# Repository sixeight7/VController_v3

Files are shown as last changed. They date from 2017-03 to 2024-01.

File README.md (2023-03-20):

# VController_v3
Production model of the VController, VC-mini and VC-touch

The VC-touch is a MIDI footcontroller with 15 buttons and a large TFT touch screen:

VC-touch

The VC-mini is a small version of the VController with 3 buttons, 3 LEDs, 2 encoders and 1 LCD display:

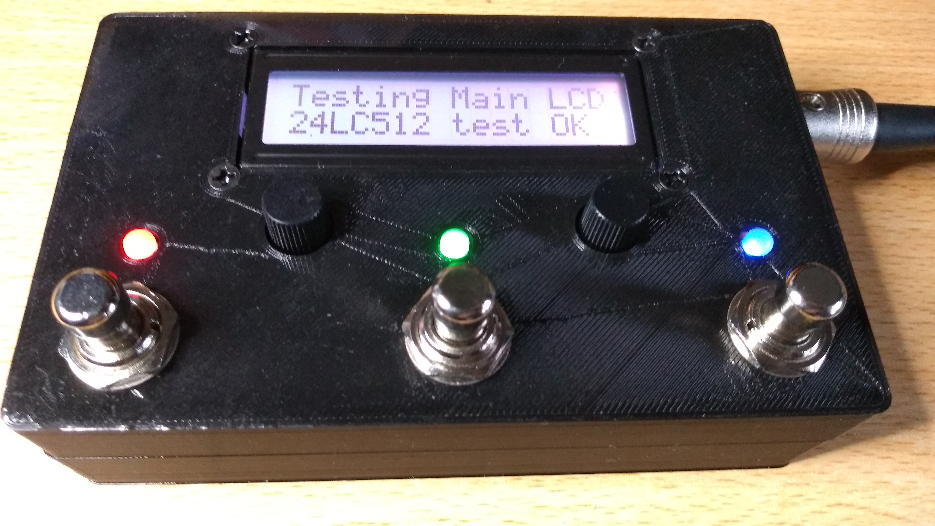
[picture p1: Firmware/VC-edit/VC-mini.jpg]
VC-mini


The VController is the original controller with 16 buttons, 12 LCDs and 12 LEDs:

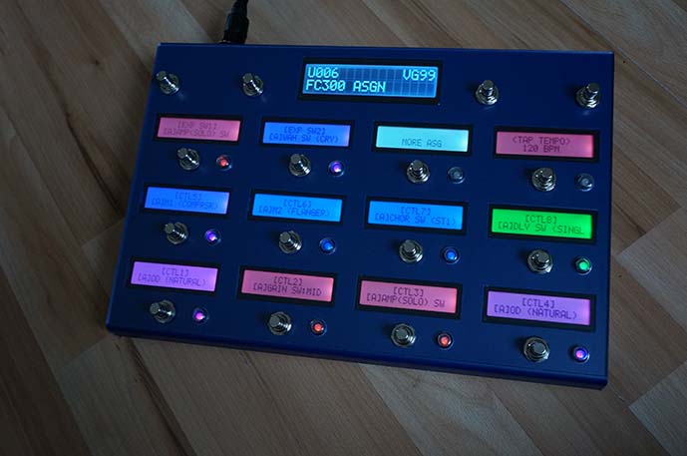
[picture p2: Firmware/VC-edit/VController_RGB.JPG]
VController


All can be fully programmed both onboard and via an external editor for Mac and PC called VC-edit.
All devices share the same code for the Teensy firmware and the editor (Qt)

# Device support
A number of guitar modelers and synths are supported, where it actively read patch names and parameter states for the following devices:
* Fractal Audio Axe-fx 2 (other models may work too, but have not been tested yet)
* Boss GP-10
* Roland GR-55
* Roland VG-99
* Boss Katana (50/100/Artist - MK1 and MK2)
* Boss SY-1000
* Kemper Profiling Amp
* Line 6 Helix (limited)
* Line 6 M13
* Zoom G3
* Zoom MS70-cdr
* Strymon Volante
* TC Electronics G-Major
* NUX MG-300

# General MIDI
The VController, VC-mini and VC-touch are also able to send MIDI PC, CC and Note on/off messages to control any device that is able to receive these messages.

# Programmability
The VController, VC-mini and VC-touch support up to 200 user pages, where a total of almost 3000 commands can be programmed. Any button can execute up to 50 commands.

# Connectivity of the VController
* There are two MIDI in/out conenctors and MIDI 2 doubles as an RRC2 connection for the VG-99.
* Four external expression pedals or eight external switches can be connected.
* One USB slave connector (also used for programming the VController)
* An internal or external Raspberry Pi can add four USB host ports to the VController.

# Connectivity of the VC-mini
* Two 7 pin MIDI connectors with MIDI in/out and power in one connector. MIDI1 has a seperate 7 pin connector with MIDI in/out reversed. The 7 pin connectors are compatible with regular 5 pin MIDI connectors.
* One external expression pedal or two external switches can be connected via a 3.5 mm jack plug (may need an adapter to regular jack.)
* One USB slave connector (also used for programming the VC-mini)
* One USB host port

# Connectivity of the VC-touch
* Three 7 pin MIDI connectors with MIDI in/out and power in one connector, MIDI in/out port on 3,5 mm plugs, wireless MIDI through MIDI BLE and WIFI - AppleMIDI.
* Three external expression pedal or six external switches can be connected via a 3.5 mm jack plug (may need an adapter to regular jack.)
* One USB slave connector (also used for programming the VC-touch)
* One USB host port

# Hardware
This repository contains the building plans (enclosure and schematics) for the VC-mini, the VController and the optional external Raspberry Pi. Check out the building guides for both projects.

# Firmware
This repository also contains the source code for the V-Controller, the VC-mini and for VC-edit. The source code for VC-bridge (the code for the raspberry pi) is in a separate repository called VC-bridge. There are also ready made hex files for the V-Controllers Teensy. There is also special firmware to check hardware of the V-Controller or the VC-mini.

For VC-edit there is a ready to run zip file for windows and dmg-file for Mac. Also the source code of VC-edit is provided.

# Webstore
You can buy ready made VC-mini's and VC-touches or seperate PCBs and enclosures at my webstore.
https://sixeightsoundcontrol.onlineweb.shop/

# Support
Please visit https://www.vguitarforums.com/smf/index.php?board=277.0 for additional information or for any questions you have regarding this project. Please post any questions on the board, where several users and builders can respond and help.

I have invested thousands of hours in this project. You can support me here: https://www.paypal.me/sixeight

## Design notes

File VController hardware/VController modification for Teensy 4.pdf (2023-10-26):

VController modification for Teensy 4.1

To run firmware 3.12.0 or higher on the VController the existing Teensy 3.2 must be replaced with a Teensy 4.1.

Step 1: determine the pin type used in the VController for the Teensy 3.2.
Open the VController by removing the six screws from the bottom plate. Remove the main PCB by removing the nuts of the EXP pedal jacks, the screws around the RRC2 connector and the screw next to it. Now gently remove the Teensy 3.2 and check the pin type. These are either thin pin headers or regular pins headers. I have used different ones for different VControllers

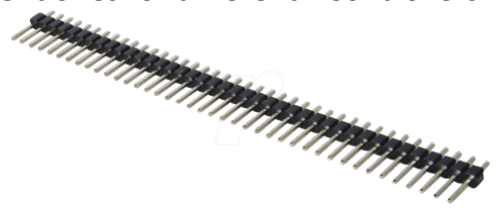
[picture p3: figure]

Thin pin headers: reichelt.de product code: BKL 10120538
Regular pin headers: reichelt.de product code: SL 1X40G 2,54
Step 2: get the parts
So you will need to get a Teensy 4.1 without a pin header attached and you will need two 14-pin headers.
Step 3: flash the firmware on the Teensy 4.1
The switch to get the Teensy 4.1 into program mode will no longer be accessible once it is placed on the board, so make sure you flash the firmware using the Teensy loader before you put the Teensy on the board.
Step 4: replace the Teensy
Solder the two 14-pin header to the top side of the Teensy, using pin 0 – 23 and the power pins. Remove the Teensy 3.2 and replace it with the Teensy 4.1.
Now replace the wires connected to D- and D+ to the small pads on the Teensy 4.1. The pads are not marked on the Teensy 4.1 but the wires do go the same way around.
The wires of pad 29 and 30 of the Teensy 3.2 go the pin 24 and pin 25 of the Teensy 4.1.
The wire of pad 28 of the Teensy 3.2 goes to pin 26 of the Teensy 4.1.
Then attach two wires connecting pin 9 with pin 28 and pin 10 with pin 29. This will fix the serial port that is on different pins on the Teensy 4.1

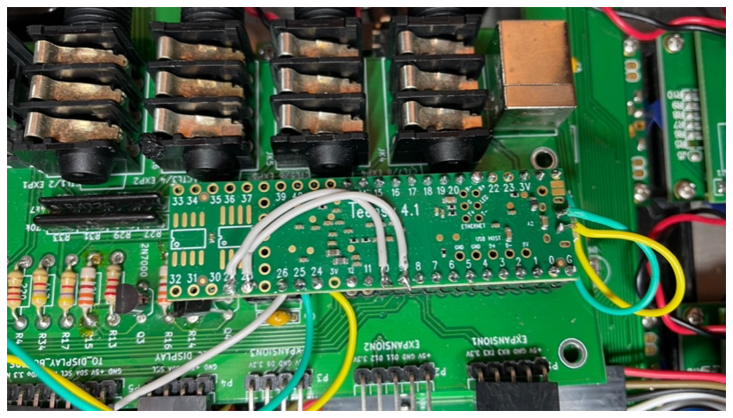
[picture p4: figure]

That’s it. If you have any questions or would like me to do the modification, please contact me at sixeightsoundcontrol@gmail.com.

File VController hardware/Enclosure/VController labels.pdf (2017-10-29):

USB | EXP4 | EXP3 | EXP2 | EXP1 | OUT | IN | IN/OUT | RRC2 | DC
CTL7/8 | CTL5/6 | CTL3/4 | CTL1/2 | MIDI 1 | MIDI2 | POWER
USB | EXP4 | EXP3 | EXP2 | EXP1 | OUT | IN | IN/OUT | RRC2 | DC
CTL7/8 | CTL5/6 | CTL3/4 | CTL1/2 | MIDI 1 | MIDI2 | POWER
USB | EXP4 | EXP3 | EXP2 | EXP1 | OUT | IN | IN/OUT | RRC2 | DC
CTL7/8 | CTL5/6 | CTL3/4 | CTL1/2 | MIDI 1 | MIDI2 | POWER
USB | EXP4 | EXP3 | EXP2 | EXP1 | OUT | IN | IN/OUT | RRC2 | DC
CTL7/8 | CTL5/6 | CTL3/4 | CTL1/2 | MIDI 1 | MIDI2 | POWER
USB | EXP4 | EXP3 | EXP2 | EXP1 | OUT | IN | IN/OUT | RRC2 | DC
CTL7/8 | CTL5/6 | CTL3/4 | CTL1/2 | MIDI 1 | MIDI2 | POWER
IN/OUT | OUT/IN | DC
MIDI | POWER
IN/OUT | OUT/IN | DC
MIDI | POWER
IN/OUT | OUT/IN | DC
MIDI | POWER
IN/OUT | OUT/IN | DC
MIDI | POWER
IN/OUT | OUT/IN | DC
MIDI | POWER
IN/OUT | OUT/IN | DC
MIDI | POWER
IN/OUT | OUT/IN | DC
MIDI | POWER
IN/OUT | OUT/IN | DC
MIDI | POWER
IN/OUT | OUT/IN | DC
MIDI | POWER
USB | EXP4 | EXP3 | EXP2 | EXP1 | OUT | IN | IN/OUT | RRC2 | DC
CTL7/8 | CTL5/6 | CTL3/4 | CTL1/2 | MIDI 1 | MIDI2 | POWER
USB | EXP4 | EXP3 | EXP2 | EXP1 | OUT | IN | IN/OUT | RRC2 | DC
CTL7/8 | CTL5/6 | CTL3/4 | CTL1/2 | MIDI 1 | MIDI2 | POWER

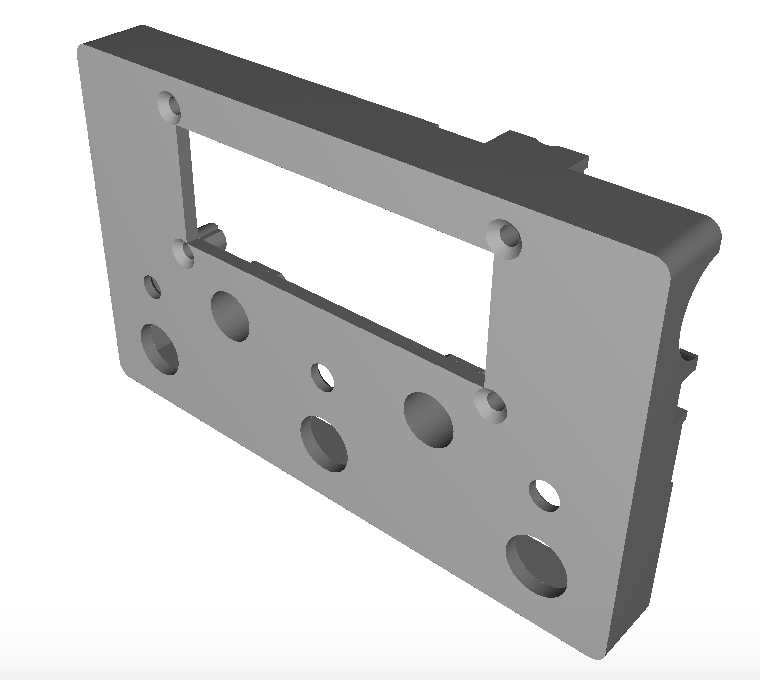
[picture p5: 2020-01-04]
VC-mini hardware/Enclosure/VCmini_upper_cover_Buydisplay_display.png

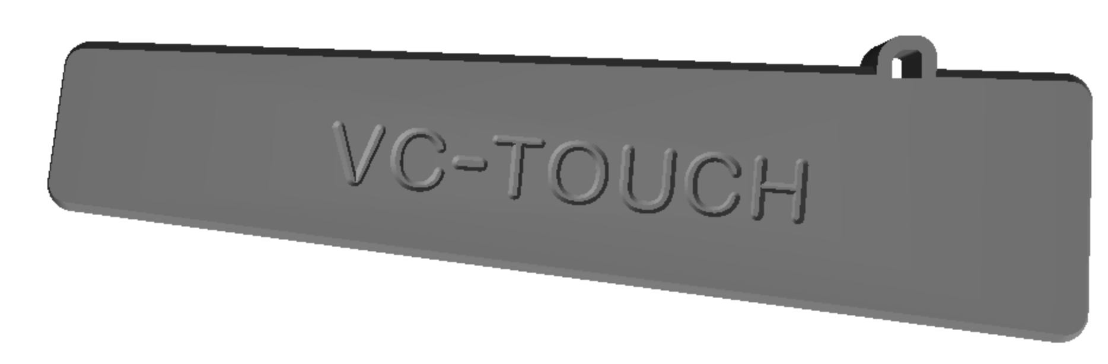
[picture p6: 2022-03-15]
VC-touch hardware/Enclosure stl/vctouch_right_side.png

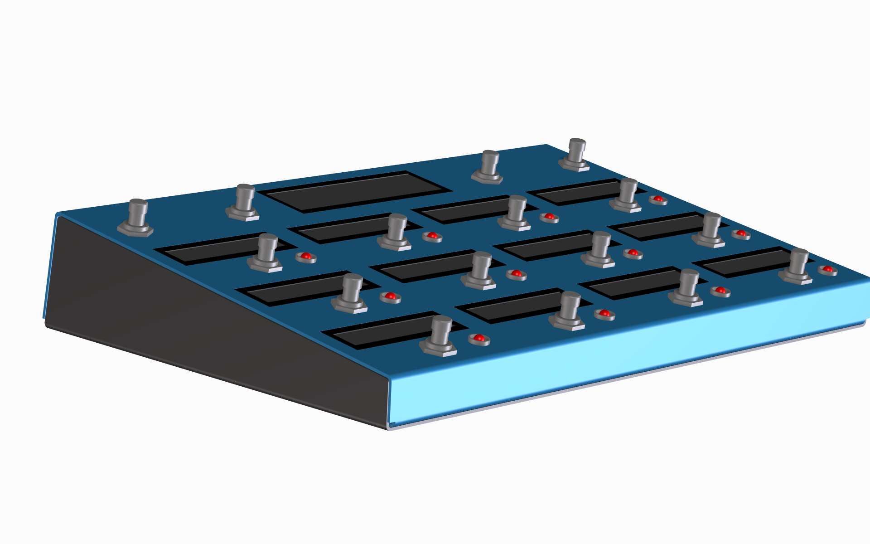
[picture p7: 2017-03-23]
VController hardware/Enclosure/Metal/VController front view render.png

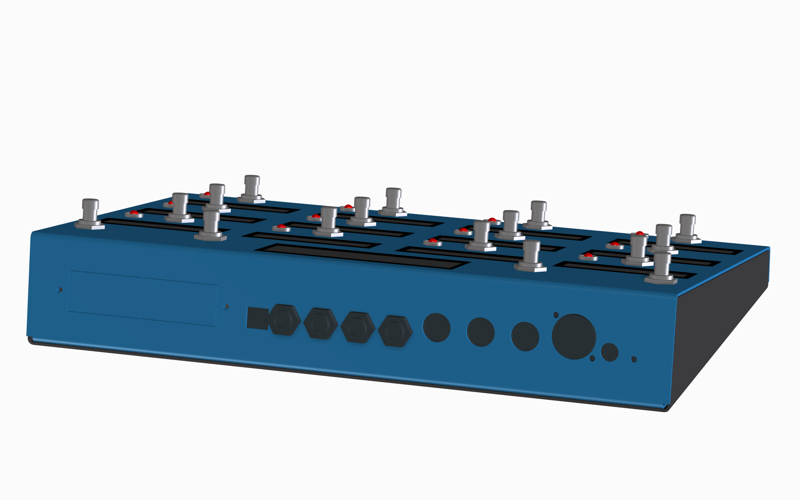
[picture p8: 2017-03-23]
VController hardware/Enclosure/Metal/VController back view render.png

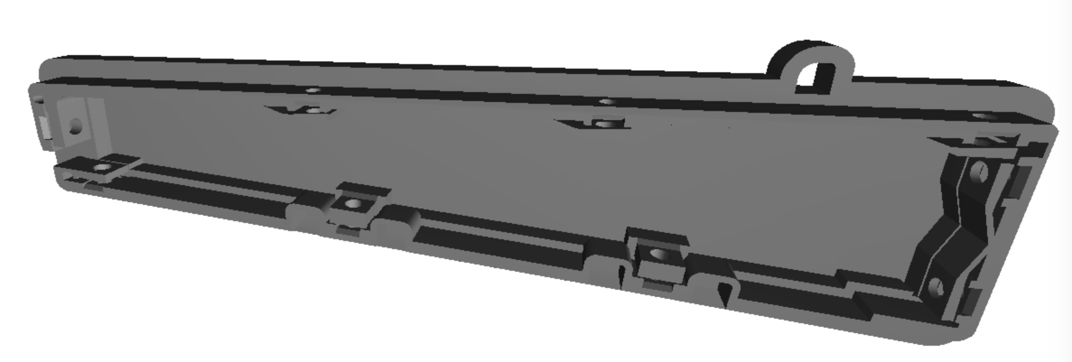
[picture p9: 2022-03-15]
VC-touch hardware/Enclosure stl/vctouch_left_side.png

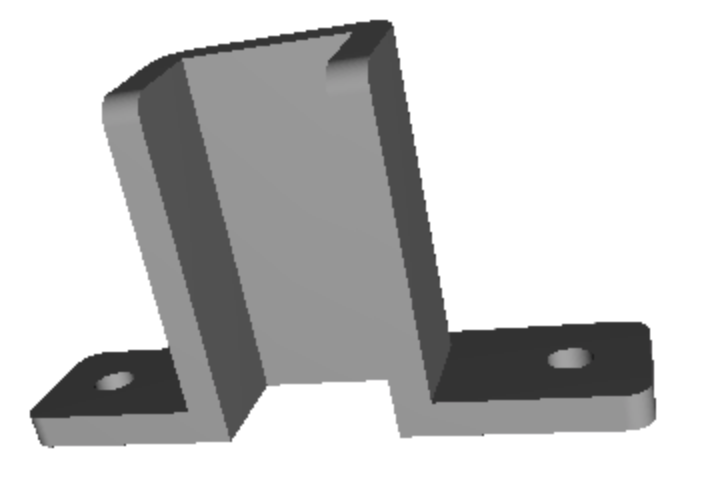
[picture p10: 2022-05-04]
VC-touch hardware/Enclosure stl/vctouch_display_support.png

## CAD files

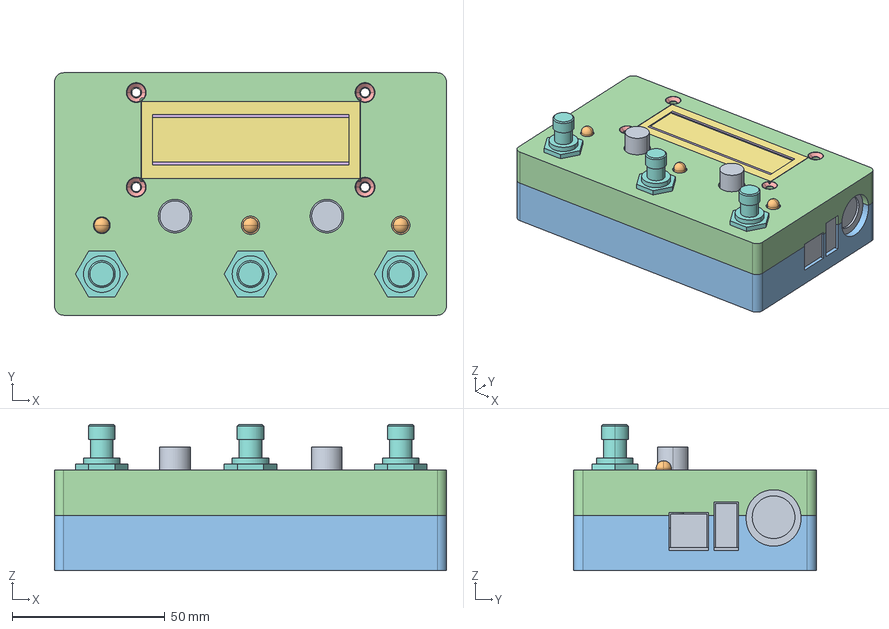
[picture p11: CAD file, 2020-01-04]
VC-mini hardware/Enclosure/VC-mini enclosure.stp
128.5 x 79.5 x 47.9 mm
PRINTPLAAT_B
LOWER_COVER_B
UPPER_COVER_B
UPPER_COVER_COLOR_DISPLAY
DISPLAY_SMALL_B
DISPLAY_COLOR
SWITCH x 3

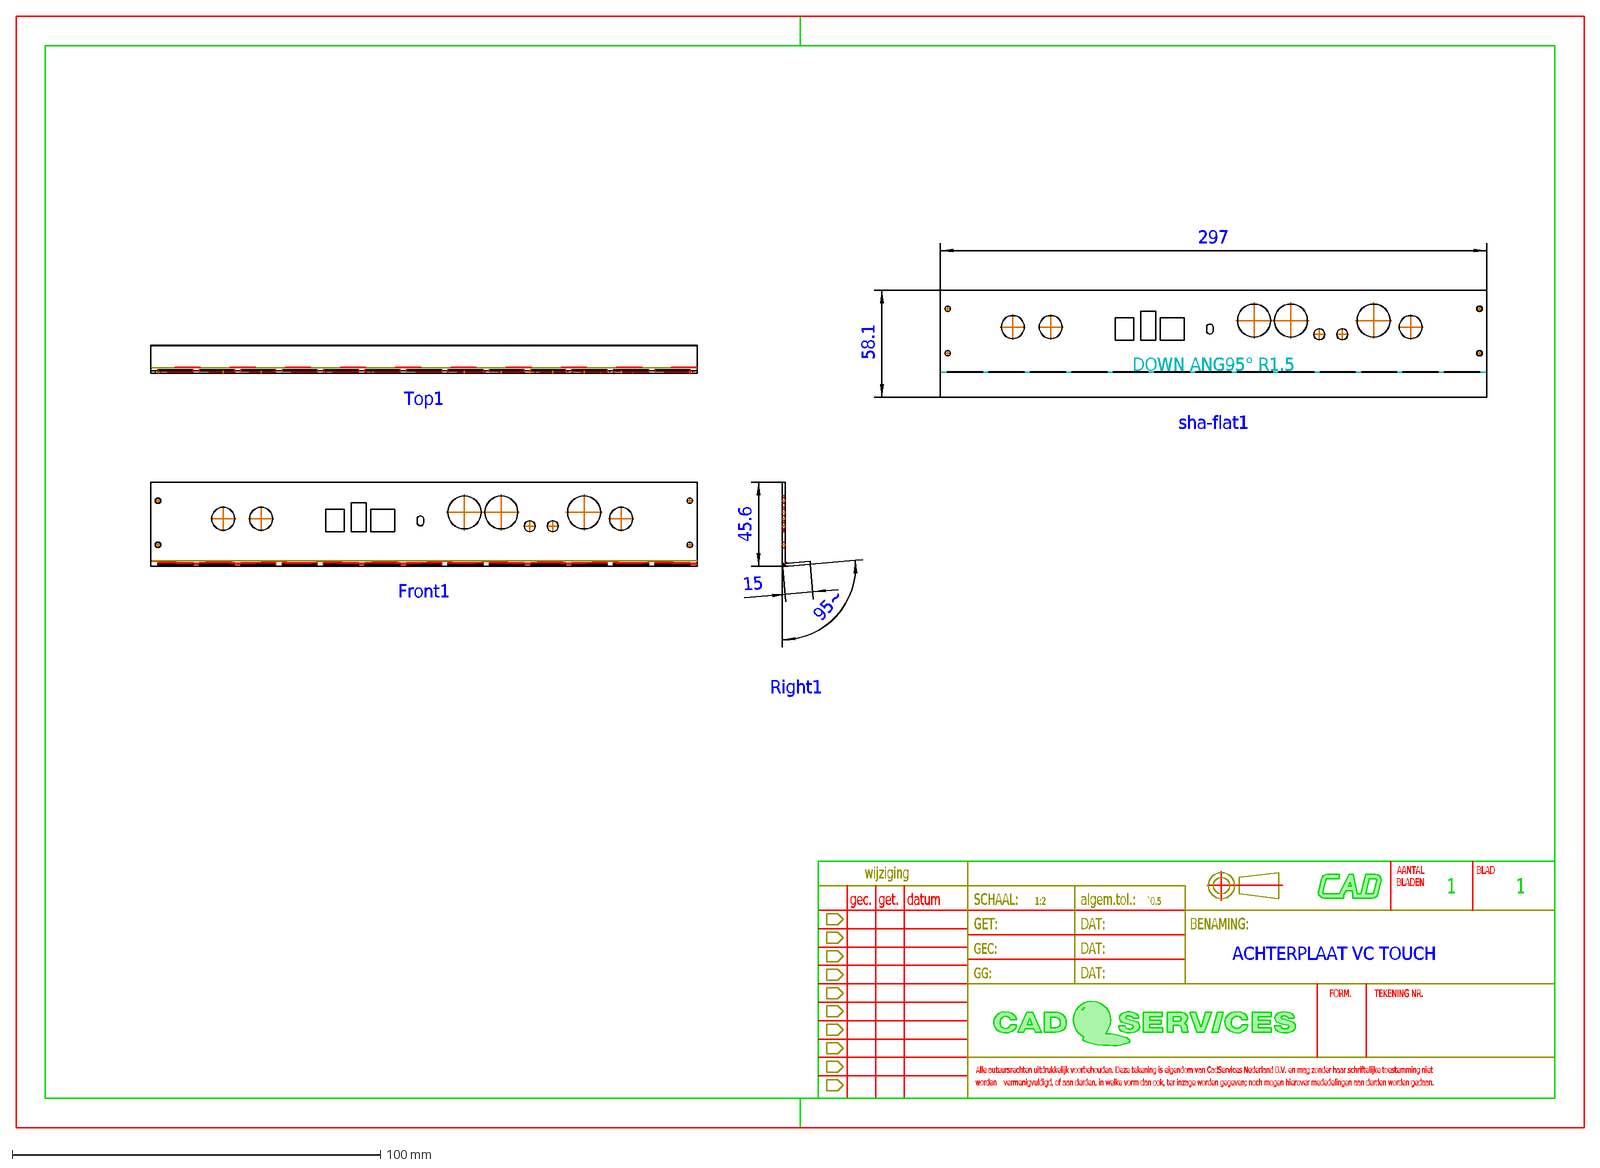
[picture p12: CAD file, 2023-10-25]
VC-touch hardware/Enclosure metal/backside.dxf
Front1
Right1
15
45.6
Top1
DOWN ANG95° R1.5
sha-flat1
297
58.1
SCHAAL:
Alle auteursrechten uitdrukkelijk voorbehouden. Deze tekening is eigendom van CadServices Nederland B.V. en mag zonder haar schriftelijke toestemming niet
1:2
algem.tol.:
GG:
DAT:
GET:
GEC:
wijziging
get.
gec.
datum
BENAMING:
worden
vermenigvuldigd, of aan derden, in welke vorm dan ook, ter inzage worden gegeven; noch mogen hierover mededelingen aan derden worden gedaan.
1
BLAD
FORM.
BLADEN
AANTAL
TEKENING NR.
ACHTERPLAAT VC TOUCH

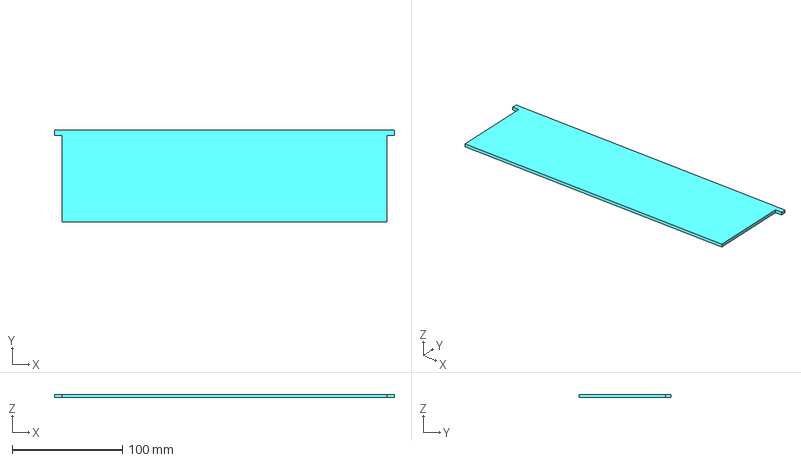
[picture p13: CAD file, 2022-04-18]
VC-touch hardware/Enclosure perspex/VC-touch_window.stp
309.0 x 84.0 x 3.00 mm

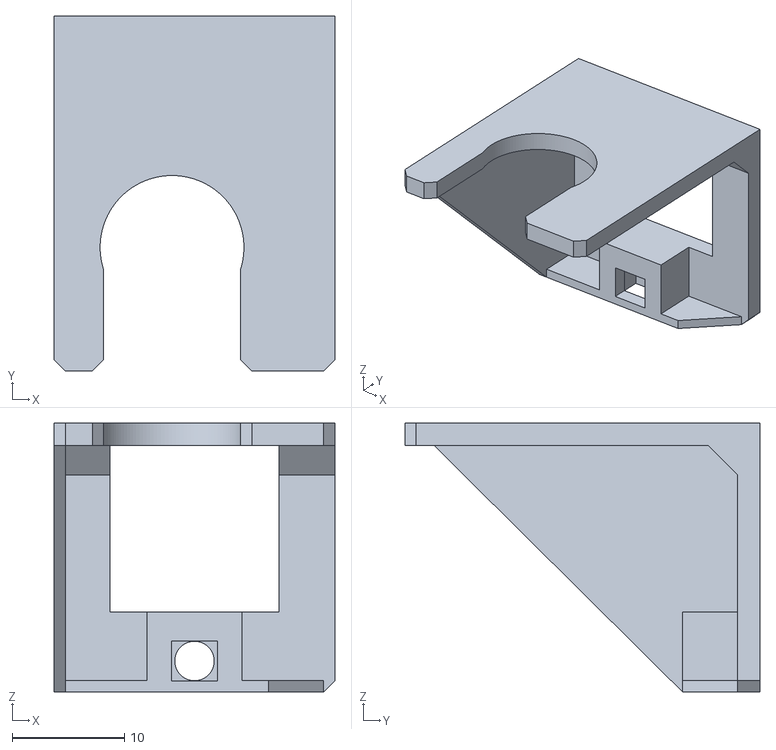
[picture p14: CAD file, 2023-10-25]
VC-touch hardware/Enclosure stl/vctouch_plate_holder.stl
25.0 x 31.6 x 23.9

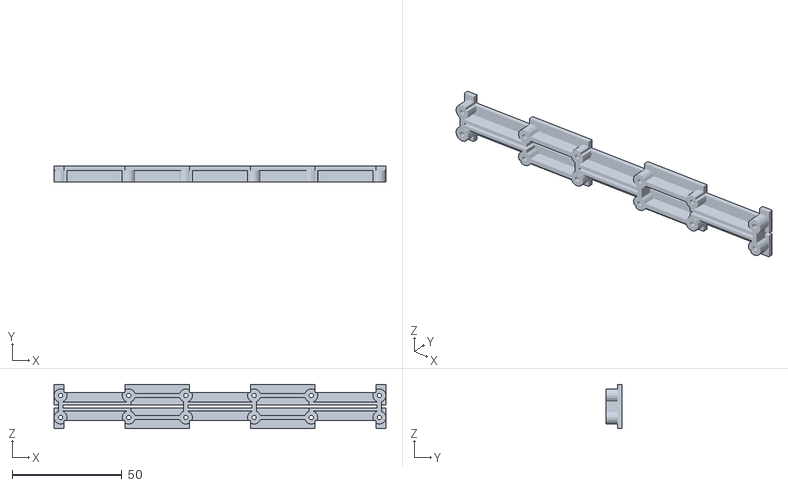
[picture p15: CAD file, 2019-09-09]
VController hardware/Enclosure/3D printing/Small 3xLCD support Adafruit.stl
151.0 x 7.30 x 20.2

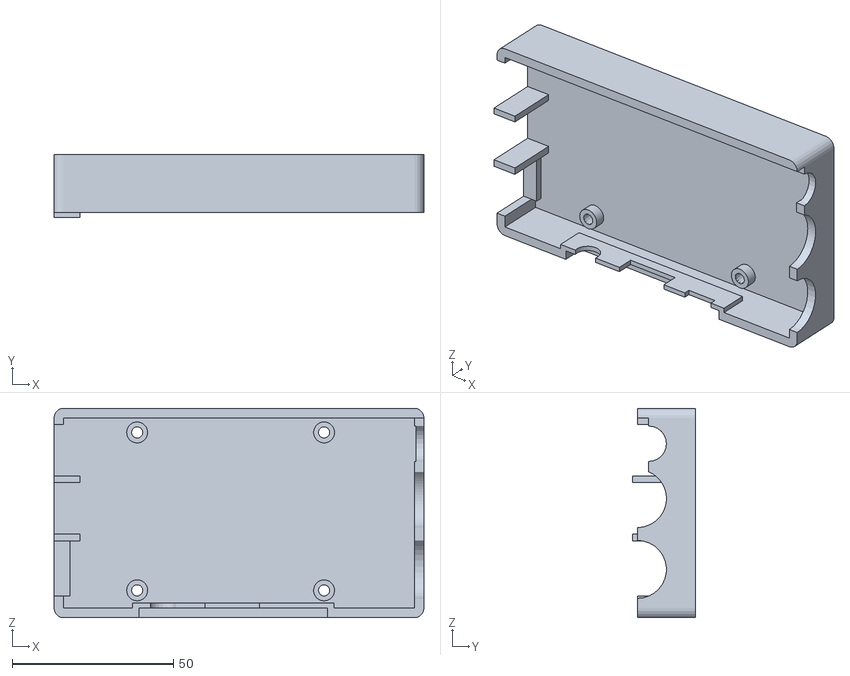
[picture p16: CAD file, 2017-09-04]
VController hardware/Enclosure/RPi case/top part.stl
114.8 x 19.5 x 65.0

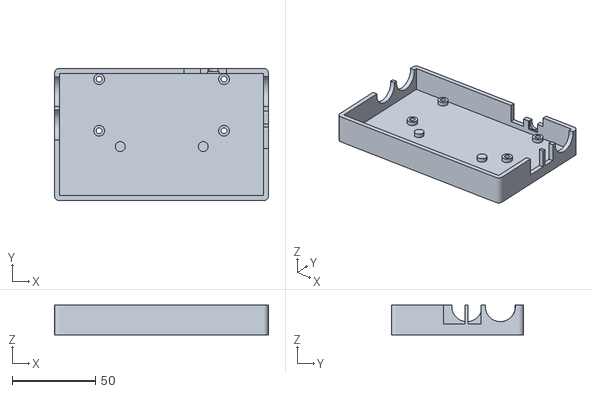
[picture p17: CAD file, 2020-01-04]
VC-mini hardware/Enclosure/VC-mini_lower_cover_b.stl
128.5 x 79.5 x 18.0

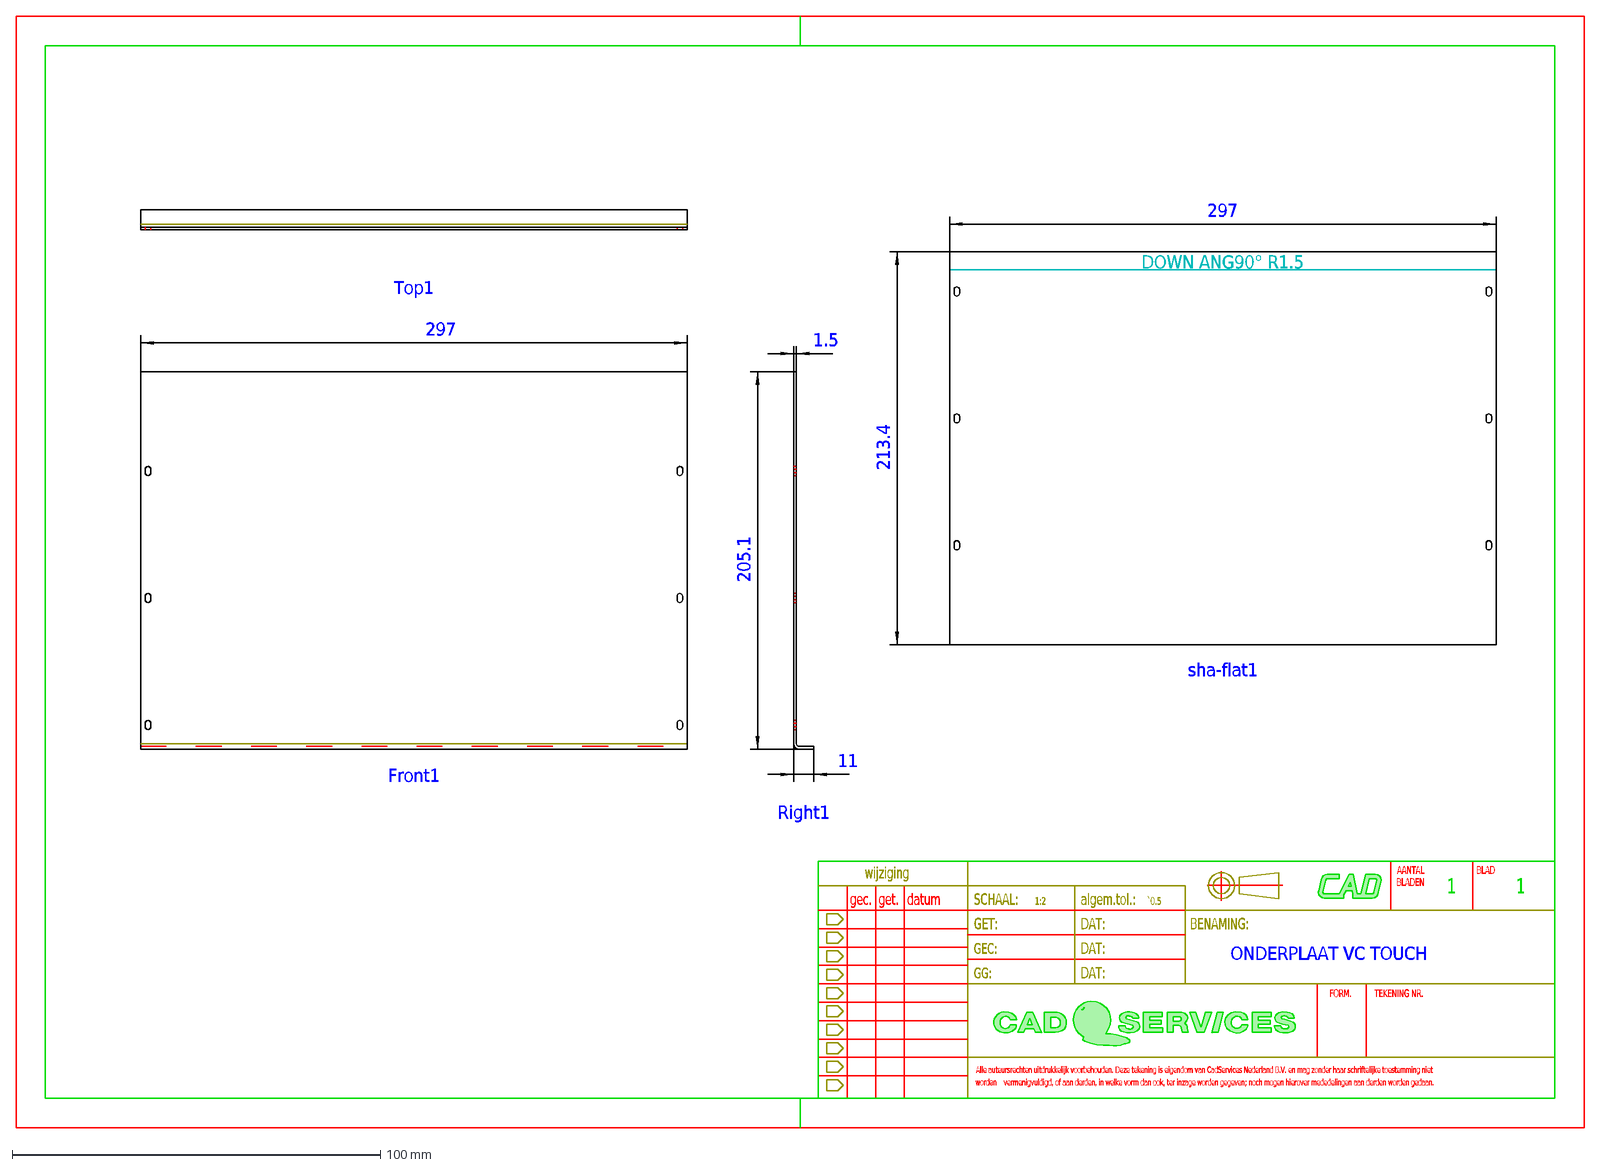
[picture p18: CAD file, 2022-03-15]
VC-touch hardware/Enclosure metal/bottom plate.dxf
Front1
297
Right1
1.5
11
205.1
Top1
DOWN ANG90° R1.5
sha-flat1
213.4
DAT:
TEKENING NR.
AANTAL
BLADEN
FORM.
BLAD
1
vermenigvuldigd, of aan derden, in welke vorm dan ook, ter inzage worden gegeven; noch mogen hierover mededelingen aan derden worden gedaan.
worden
BENAMING:
datum
gec.
get.
wijziging
GEC:
GET:
GG:
algem.tol.:
1:2
Alle auteursrechten uitdrukkelijk voorbehouden. Deze tekening is eigendom van CadServices Nederland B.V. en mag zonder haar schriftelijke toestemming niet
SCHAAL:
ONDERPLAAT VC TOUCH

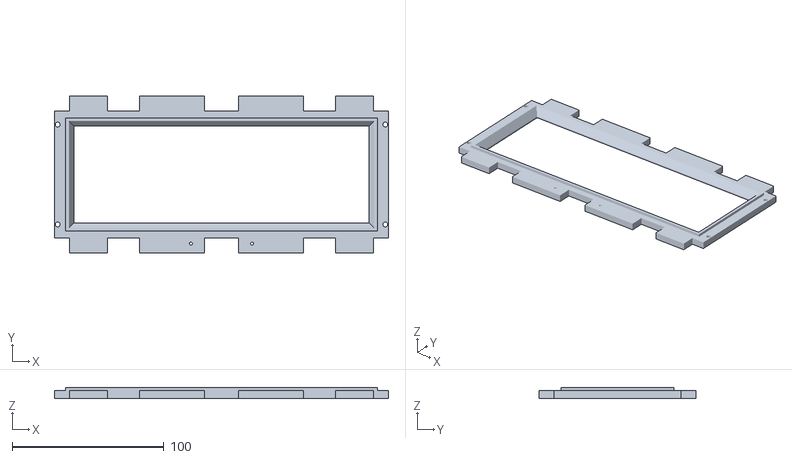
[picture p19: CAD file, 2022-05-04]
VC-touch hardware/Enclosure stl/vctouch_display_bezel.stl
220.0 x 103.6 x 7.00

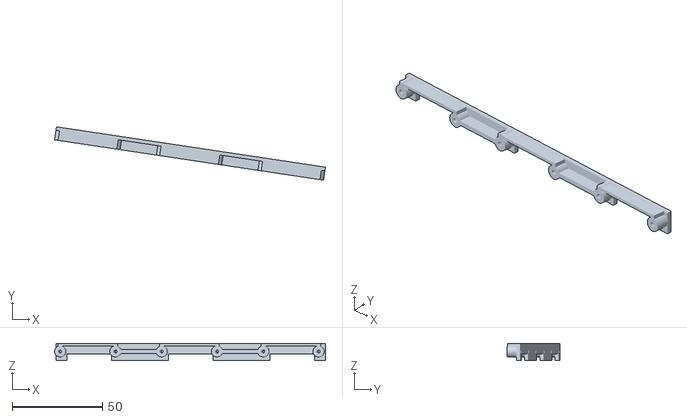
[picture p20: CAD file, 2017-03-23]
VController hardware/Enclosure/3D printing/Half support 3xLCD diameter_2_0.stl
150.4 x 29.6 x 9.60

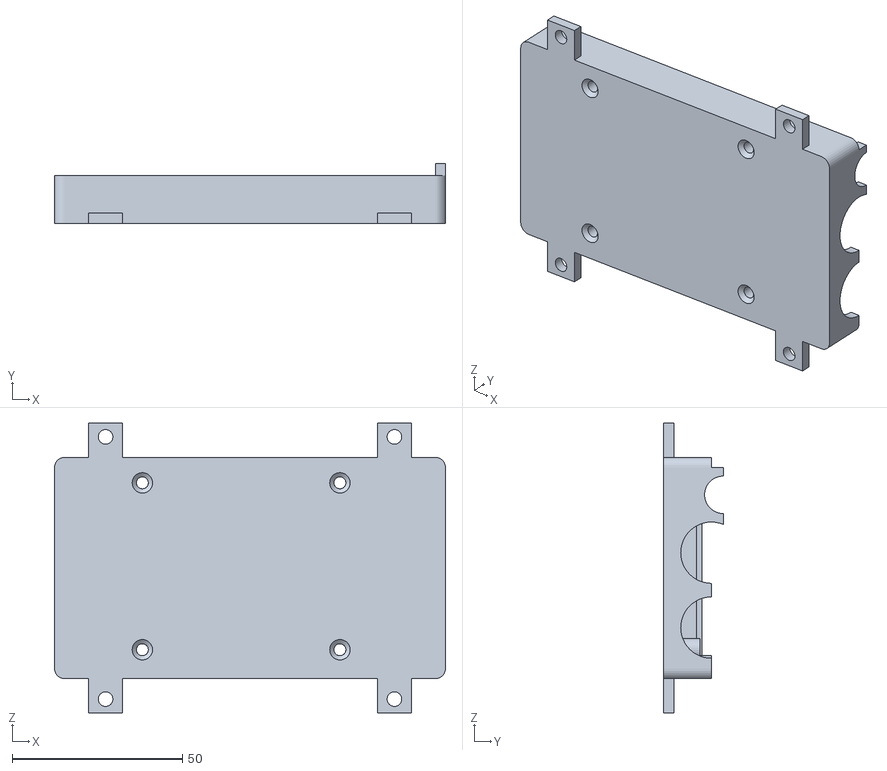
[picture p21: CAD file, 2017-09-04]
VController hardware/Enclosure/RPi case/bottom part.stl
114.8 x 17.5 x 85.0

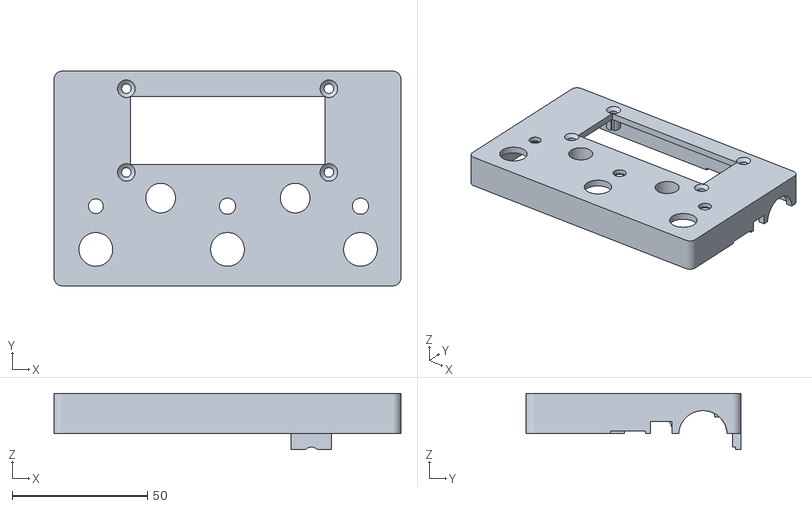
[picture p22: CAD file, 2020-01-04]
VC-mini hardware/Enclosure/VCmini_upper_cover_Buydisplay_display.stl
128.5 x 79.5 x 20.9

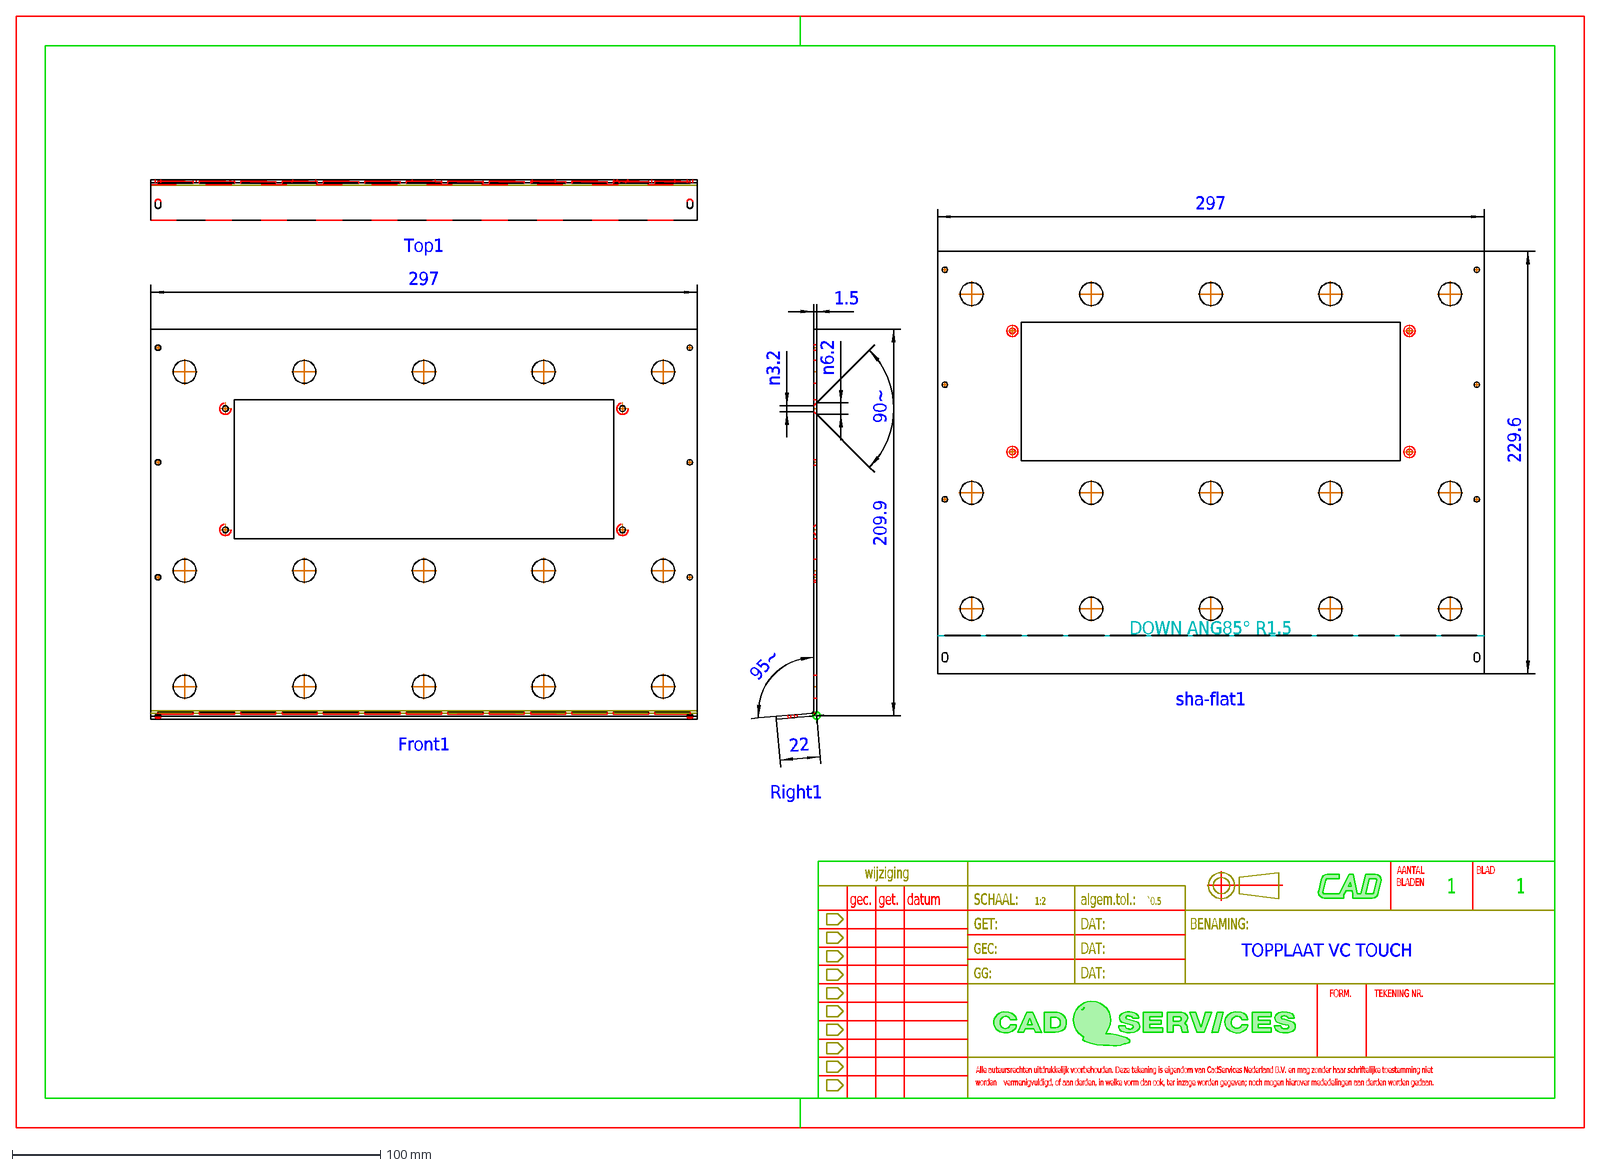
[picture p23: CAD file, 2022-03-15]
VC-touch hardware/Enclosure metal/top plate.dxf
Front1
297
Right1
1.5
209.9
22
Top1
DOWN ANG85° R1.5
sha-flat1
229.6
DAT:
TEKENING NR.
AANTAL
BLADEN
FORM.
BLAD
1
vermenigvuldigd, of aan derden, in welke vorm dan ook, ter inzage worden gegeven; noch mogen hierover mededelingen aan derden worden gedaan.
worden
BENAMING:
datum
gec.
get.
wijziging
GEC:
GET:
GG:
algem.tol.:
1:2
Alle auteursrechten uitdrukkelijk voorbehouden. Deze tekening is eigendom van CadServices Nederland B.V. en mag zonder haar schriftelijke toestemming niet
SCHAAL:
TOPPLAAT VC TOUCH

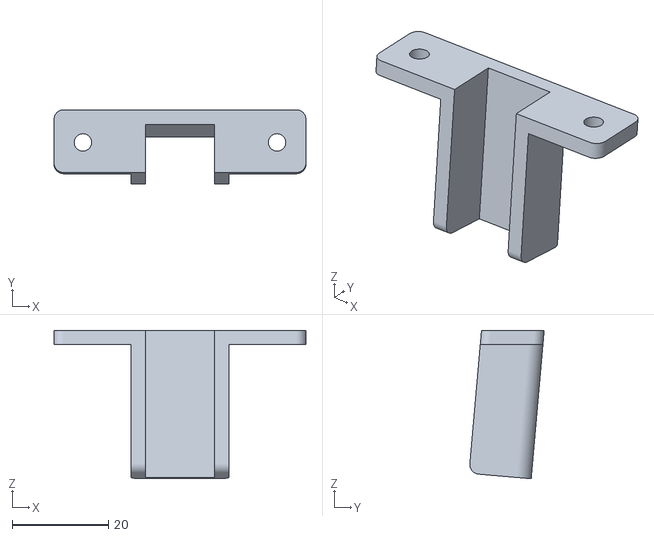
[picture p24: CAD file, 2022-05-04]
VC-touch hardware/Enclosure stl/vctouch_display_support.stl
52.3 x 15.4 x 30.8

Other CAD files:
VController hardware/Enclosure/Metal/RPi expansion board bracket.dwg
VController hardware/Enclosure/Perspex/perspex.dwg
VController hardware/Enclosure/Metal/top plate VController Adafruit displays.dwg
VController hardware/Enclosure/3D printing/Large LCD support_2_0.stl
VC-mini hardware/Enclosure/VC-mini_upper_cover_Adafruit_display.stl
VController hardware/Enclosure/3D printing/Small 3xLCD support diameter_2_0.stl
VController hardware/Enclosure/Metal/VController_mk4.step
VController hardware/Enclosure/Metal/bottom plate VController_mk4_05122016.dwg
VController hardware/Enclosure/Metal/top plate VController_mk4_05122016.dwg

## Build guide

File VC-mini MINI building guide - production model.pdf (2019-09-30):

V-Controller MINI production model building guide Version 1.1
By sixeight at vguitarforums.com

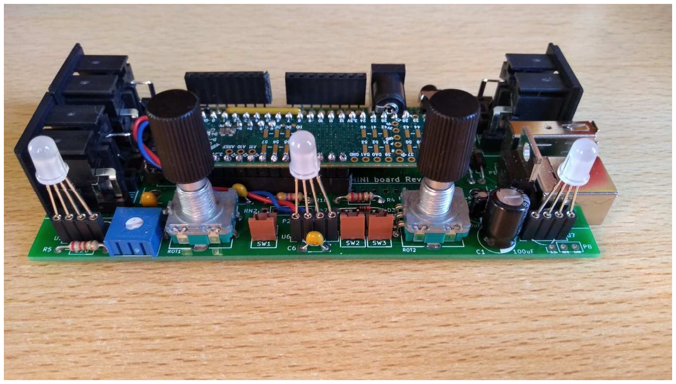
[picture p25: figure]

Introduction
Here is a quick guide for building the VC-MINI, a dedicated MIDI controller for Boss GP-10 / Roland GR-55 / Roland VG-99 / Zoom G3 / Zoom MS70-CDR / Line6 M13 / Line6 Helix / Fractal AxeFX / Boss Katana and the Kemper Profiling Amp. Building this device should cost around 4 hours and $100 -150 for parts, depending on the cost for the enclosure and the display.

Features of the VC-MINI:
Check out the VC-MINI User Guide for features.

Main parts of the VController:
The VController has the following main parts:
- 3D printed enclosure
- VController MINI PCB board.

Additional documents:
- STL files for the 3D printed enclosure:
- PDF with the schematic

Bill of materials: VC-mini

Reference | Num-ber | Part | Where to get
Display* | 1 | 16x2 LCD character displays ERM1602DNS-4-5V* | Buydisplay.com: ERM1602DNS-4-5V
Display** | 1 | RGB backlight Positive or negative LCD 16x2** | Adafruit: 398 or 399
Display | 1 | 16 or 18** pin header | reichelt.de: SL 1X40G 2,54
Display | 1 | Arduino stackable header kit R3. Use 8 + 8 or 6 + 10 pin (middle pins of display are not connected) | Sparkfun: PRT-11417
U5-U7 | 3 | Neopixel LED 5mm (Neopixel or PL9823 F5) | Adafruit: 1938 Ebay (search for PL9823 F5)
U5-U7 | 3 | Female header 2.54 mm, 1x4 straight Or 4 pin male header | reichelt.de: MPE 115-1-004
SW1-3 | 3 | Footswitch | http://www.ebay.com/itm/271930278587
SW1-3 U5 | 3 | PCB connector straight, brown, 2-pin (also for wire to USB port on Teensy) | reichelt.de: PS 25/2G BR
ROT1, ROT2 | 2 | Rotary encoder Alps STECC11B03 | reichelt.de: STEC11B03
ROT1, ROT2 | 2 | Rotary knob for rotary axis 6mm | reichelt.de: KNOPF 10-150B
RV1 | 1 | 10k trimmer 10 mm horizontal | reichelt.de: 76-10 10K (test 64W-10k and 64Z-10k)
U5 | 1 | Teensy 3.6 or 3.2 or LC (without pins as the Teensy is mounted upside down!’ | https://www.pjrc.com/store/teensy36.html reichelt.de: TEENSY 3.6
U5 | 1 | Pins for Teensy | reichelt.de: SL 1X40G 2,54
U5 | 2 | Socket for Teensy. 20 pins suffice for Teensy 3.6. Cut one into 14 pin + 5 pin (one pin butchered). See guide. | reichelt.de: BL 1X20G 2,54 (socket)
U2 | 1 | VO2630 dual optocoupler | reichelt.de: VO 2630
U1 | 1 | uA7805 Voltage regulator | reichelt.de: L 7805 CV
U4 | 1 | 24LC512 I/P serial EEPROM | reichelt.de: 24LC512-I/P
U5** | 1 | WS2811** | Adafruit: 1378
U1, U2 | 2 | 8 pin IC socket | reichelt.de: GS 8
JK1,JK2, JK3 | 3 | 7 pin din socket (MIDI) Cliff FM6727 Pro Signal PSG03465 | Farnell: 1791759 or 2679728 reichelt.de does not stock these. Could use 5 pin MABP 5S instead if power is not needed
JK4 | 1 | Power barrel – centre pin 2 mm | reichelt.de: LUM NEB 21R Farnell: 1737246
P7 | 1 | 1x Lumberg 1503-07 3,5mm stereo jack PCB | reichelt.de: LUM 1503-07
P3 | 1 | 1x USB male socket type B | reichelt.de: USB BW
P1 | 1 | 1 x USB A vertical | Reichelt.de: USB AW-VL
D1, D4, D5, D6, D7, D8 | 6 | 1N5817 shottky diode | reichelt.de: 1N 5817
D2, D3 | 2 | 1N4148 diode | reichelt.de: 1N 4148
C1 | 1 | 100 uF capacitor, >=16V | reichelt.de: RAD FR 100/35
C3 | 1 | 10 uF capacitor, >=16V | Reichelt.de: SM 10/16RAD
C2, C4, C5, C6, C7** | 4* or 5** | 100 nF capacitor | reichelt.de: KERKO 100N
RN1, RN2 | 2 | Resistor network 4 res./5 pin 4k7 RN2 can be skipped. | reichelt.de: SIL 5-4 4,7K
R1, R2, R3, R6 | 1 | Resistor network 4 res./8 pin 47 | reichelt.de: SIL 8-4 47
R7, R8, R11, | 1 | Resistor network 4 res./8 pin 4k7 | reichelt.de: SIL 8-4 4,7K

R13
R10 | 1 | 4k7 resistor | reichelt.de: 1/4W 4,7k
R4, R5 | 2 | 220 resistor | reichelt.de: 1/4W 220
R12 | 1 | 470k resistor | reichelt.de: 1/4W 470K
R9* | 1 | 100 Ohms resistor* | reichelt.de: 1/4W 100
| 4 | 15mm spacer | reichelt.de: DI 15mm
| 4 | M3 x 12mm (black) | ebay
| 4 | M3 x 16mm (black) | ebay
* Only for monochrome display | ** Only for colored display

Power supply (optional)
1 | Compact switching power supply,
18W, out 9V

Reichelt.de: PSAA 18U-090

Building the Main PCB

PCB manufacturing:
Contact me to order a main PC board at SixEightSoundControl@gmail.com or by sending a pm to sixeight on vguitarforums.com.

Options

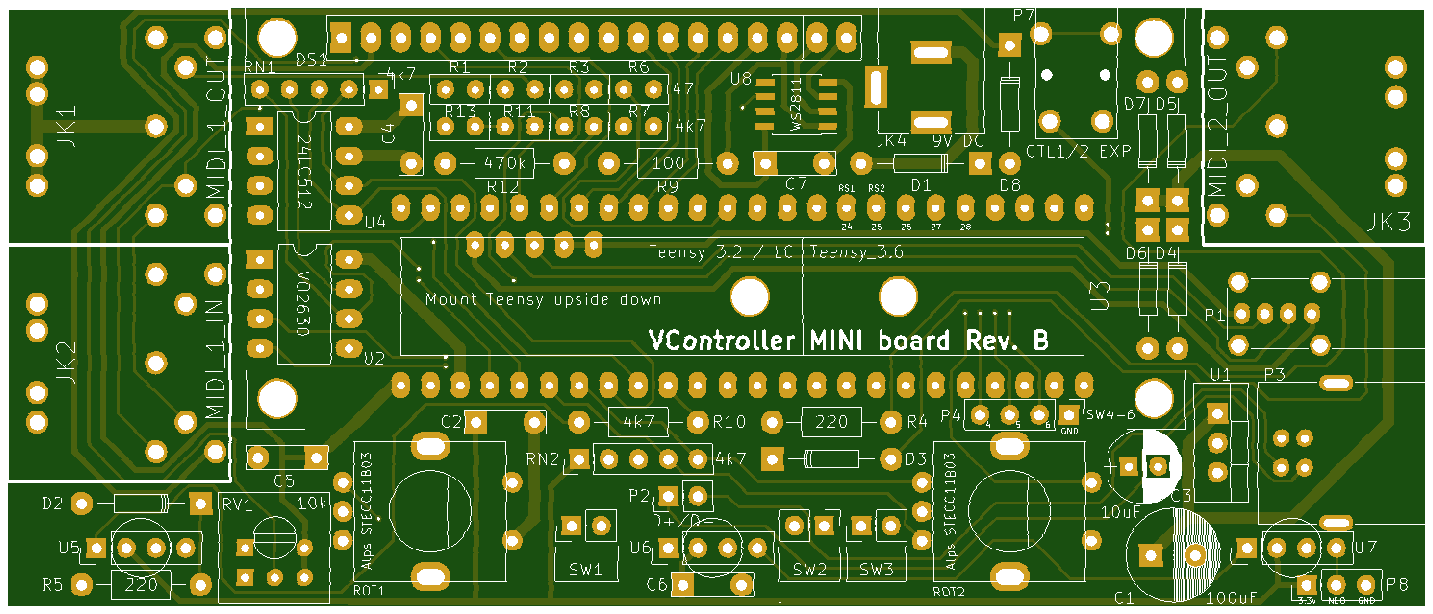
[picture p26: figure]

To build the VC-mini, there are a few choices to be made.

Teensy 3.6, 3.2 or LC:
The VC-mini board is compatible with all these Teensy models.
1) Teensy 3.6 is the best option. It has plenty of memory and speed and most important it is the only Teensy with a USB host port, which you need for direct connection of the Katanas, the Boss GP-10 and the Zoom devices! All Teensies do have a working USB slave port. (GP-10 currently not working)
2) Teensy 3.2 is large enough to run the full VController code, but it does not have a USB host port.
3) Teensy LC is the cheapest, but it will not run the full sketch of the VController and it has no USB host port. But it may be just fine for your project.

Monochrome or RGB backlit display:
I really like the Buydisplay white on black monochrome display. It has the best visibility:

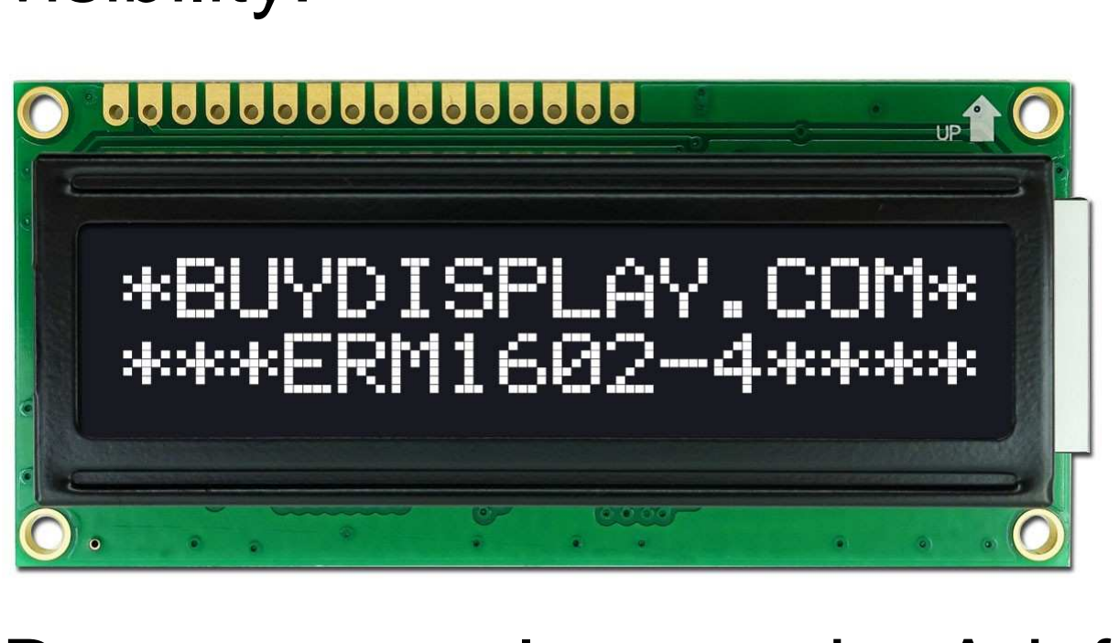
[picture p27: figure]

But you can also use the Adafruit RGB positive or negative displays:

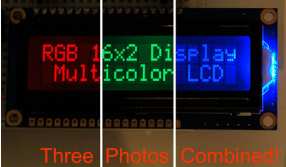
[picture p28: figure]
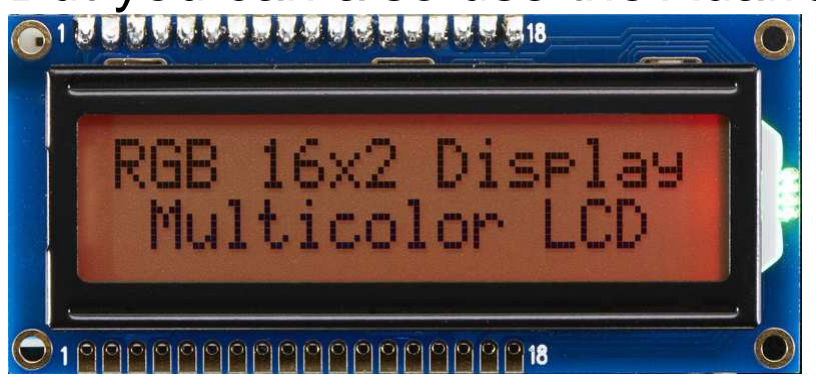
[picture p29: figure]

When using an RGB backlit display R9 (100 Ohms) must be omitted and U5 (WS2811) and its capacitor (C7) must be put on the board. You can also use U5 to control the backlight of a monochrome display.

Do note that most 16x2 displays have the same PCB size, but the size of the bezel is different. There are different 3D print (stl) files for the the Buydisplay and the Adafruit displays. Use different branded displays at your own risk. In my opinion most white on blue displays have bad visibility!

Soldering:
I always solder starting with the parts with the least height. Then I work my way up to the parts with more height. Before soldering all the pins of the connectors, check if they fit the enclosure.

Soldering the Teensy:
For the Teensy I use two low profile 20 pin female headers:

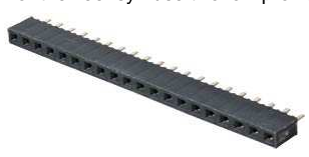
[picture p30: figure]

The Teensy 3.6 has more than 20 pins, but not all pins are used.
One of the headers is cut into a 14 and a 5 pin header. The cut will butcher one pin. The headers are connected to the board in the following way:

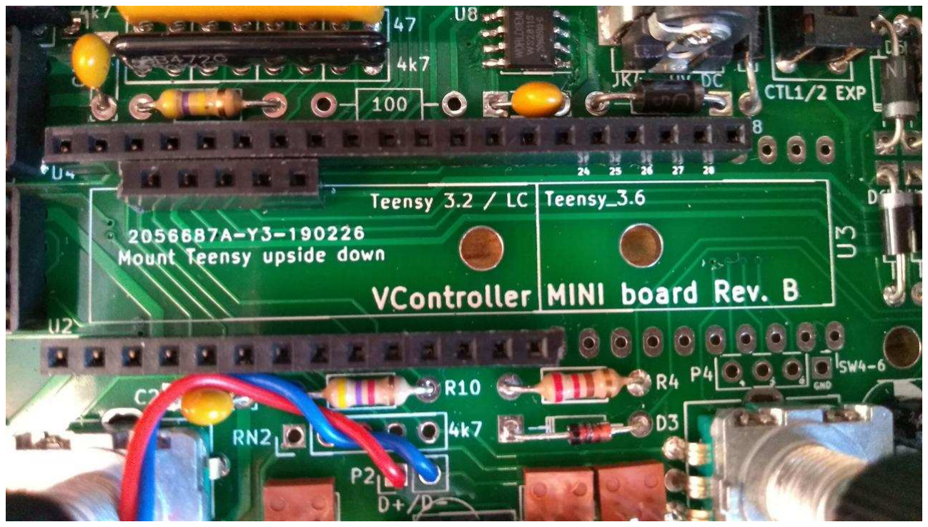
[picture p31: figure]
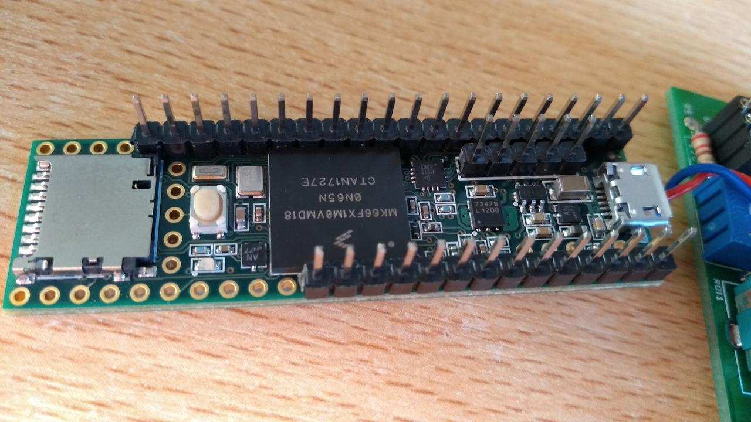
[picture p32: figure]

Also on the Teensy I only connect the pins that are in use:

Two wires connect the D+ and D- pads on the Teensy to the D+ / D- connectors on the PCB:

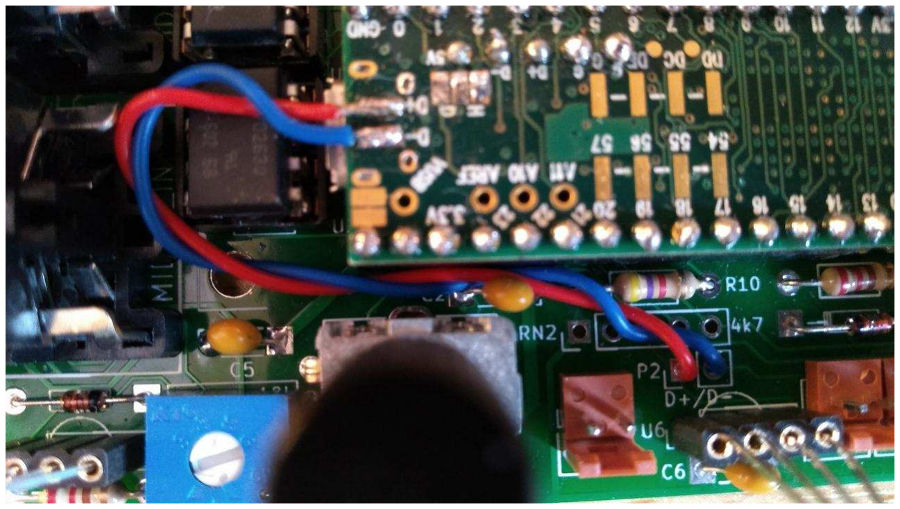
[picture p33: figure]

Connecting the Teensy 3.2 or Teensy LC
The 20 pin female headers can be cut to 14 pins for the Teensy 3.2 or LC. Use two wires to connect pin 24 and 25 from the board to the Teensy. Pin 24 and 25 are marked on the PCB.

On the Teensy 3.2 these pins are pads and on the LC they are holes.

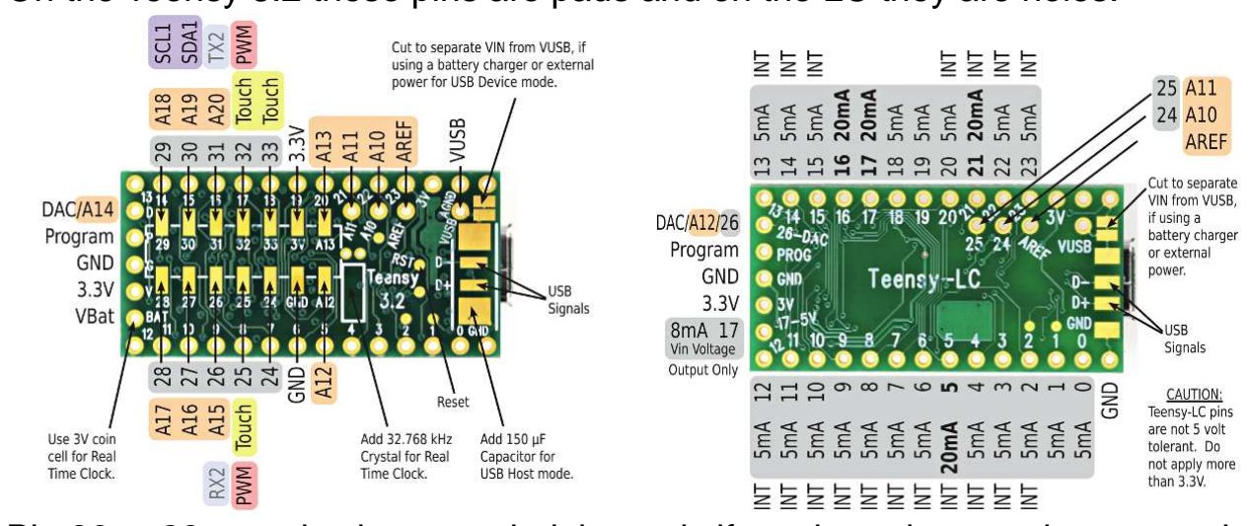
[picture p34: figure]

Pin 26 to 28 can also be extended, but only if you intend to use the connections for the extra switches (switch 4-6, see further modifications)

Also connect D+ and D- from the PCB to the pads on the Teensy.

Adding the display:
The display is attached to the PCB using four 15 mm spacers. A standard 16 or 18 pin female header is too short to make the connection between the display and the PCB. So I use stackable headers. The Arduino Stackable Header Kit R3 is just fine for the job:

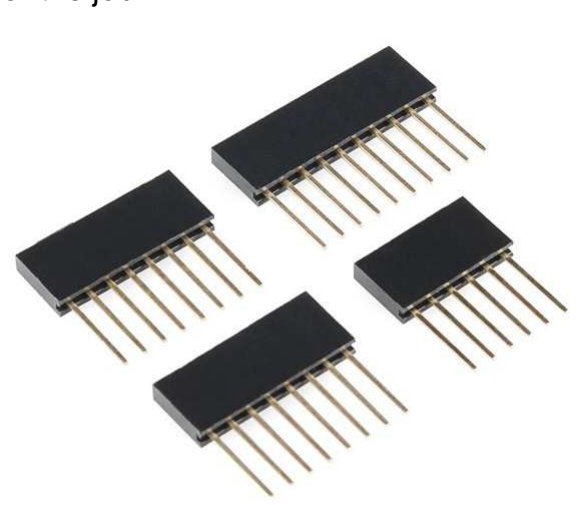
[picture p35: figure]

Before cutting the pins of the header, make sure you put the spacers in place and push the female header up to the display, so it all fits properly:

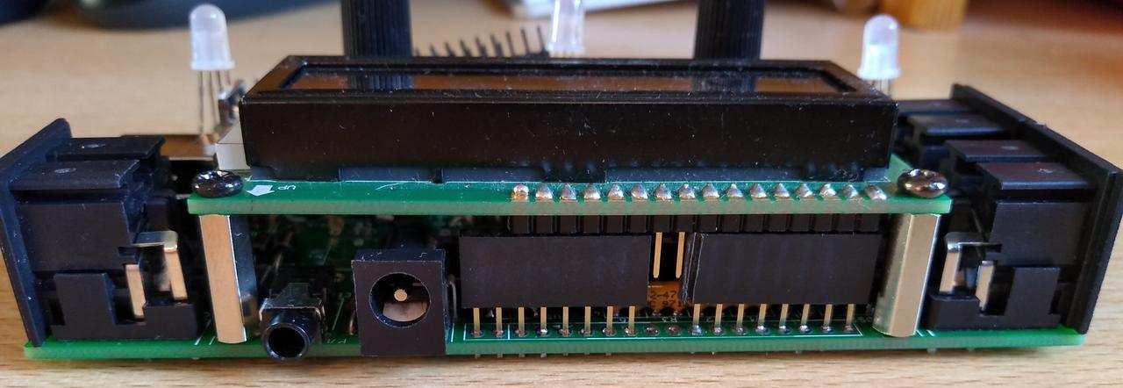
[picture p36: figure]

The middle pins are not connected, but that is no problem. The pads on the PCB are not connected either.

Adding the neopixel displays:
The height of the Neopixel LEDs also has to line up properly with the board, but by chance everything fits beautifully and makes assembly very simple.

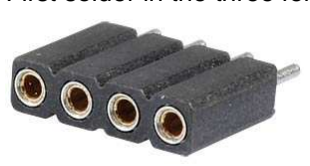
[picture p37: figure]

First solder in the three female precision four pin headers:

The LEDs just fit without making any cuts to them:

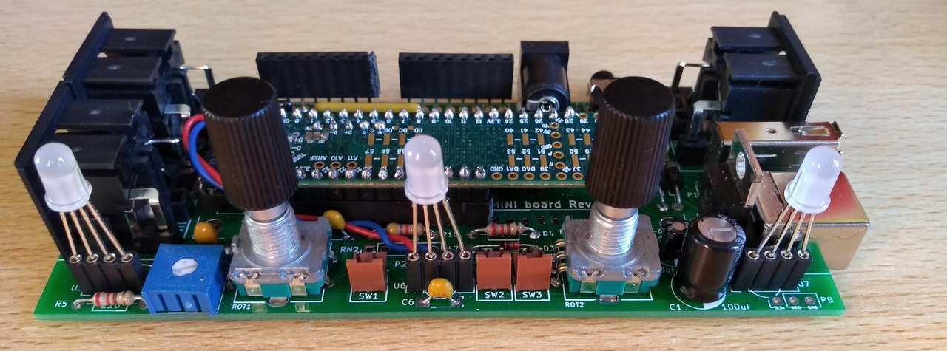
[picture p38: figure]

Do watch the pinout of the neopixel LEDs. The longer pins are on the right side in the picture above. Data is on the left, data out on the right side.

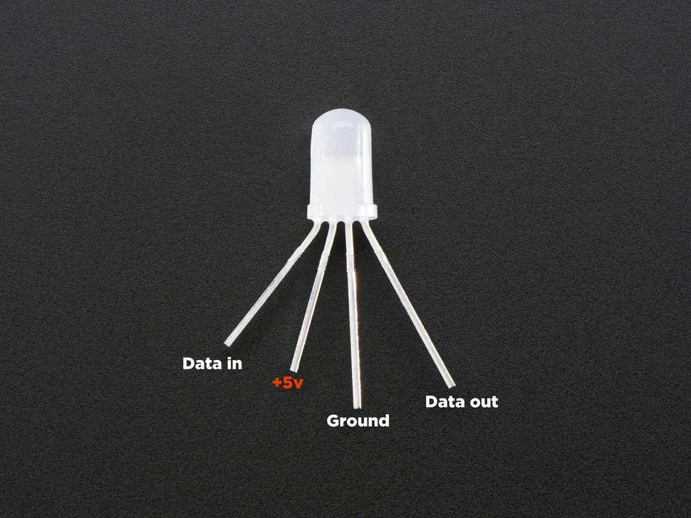
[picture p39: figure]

Further modifications

Adding extra switches and LEDs
Just above ROT2 there is an optional connector (P4) for three extra switches.

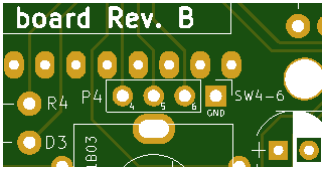
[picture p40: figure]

These share a common ground. On the Teensy LC there are not enough available pins to connect any extra pins.

To add extra Neopixel LEDs to these switches, three more LEDs can be daisychained to connector P8.

You will need to manually change the firmware to be able to use there extra switches and pins.

Using 3.3V display
If you have a 3.3V display, there is an easy modification to support these. First cut the 5V to the display and RV1, by cutting a trace below C5

Then use a small wire to connect 3.3v power to the display. The picture below shows the wire on the top of the board, but it is easier to do this on the bottom.

Usually 3.3V displays are more expensive than 5V ones, so unless you have one lying around, there is no reason to do this modification!

Testing:
You can find a link to a hardware test sketch in the firmware section below. Link to sketch:
https://github.com/sixeight7/VController_v3/tree/master/Firmware/Hardware_test_VC_mini_rev_B

Link to pre-compiled test sketch: https://github.com/sixeight7/VController_v3/tree/master/Firmware/Compiled
you need Hardware_test_VC_mini_rev_B.ino.hex, which can be loaded in the Teensy application.

The test sketch does a number of tests during boot.
Check that the display and the LEDs are working and that the 24LC512 tests out OK. You can also test the switches and check if the LEDs line up with the switches.

Printing the enclosure
The enclosure consists of two parts, an upper cover and a lower cover. There are two versions of the upper cover: one for the Buydisplay displays and one for the Adafruit (RGB) displays:

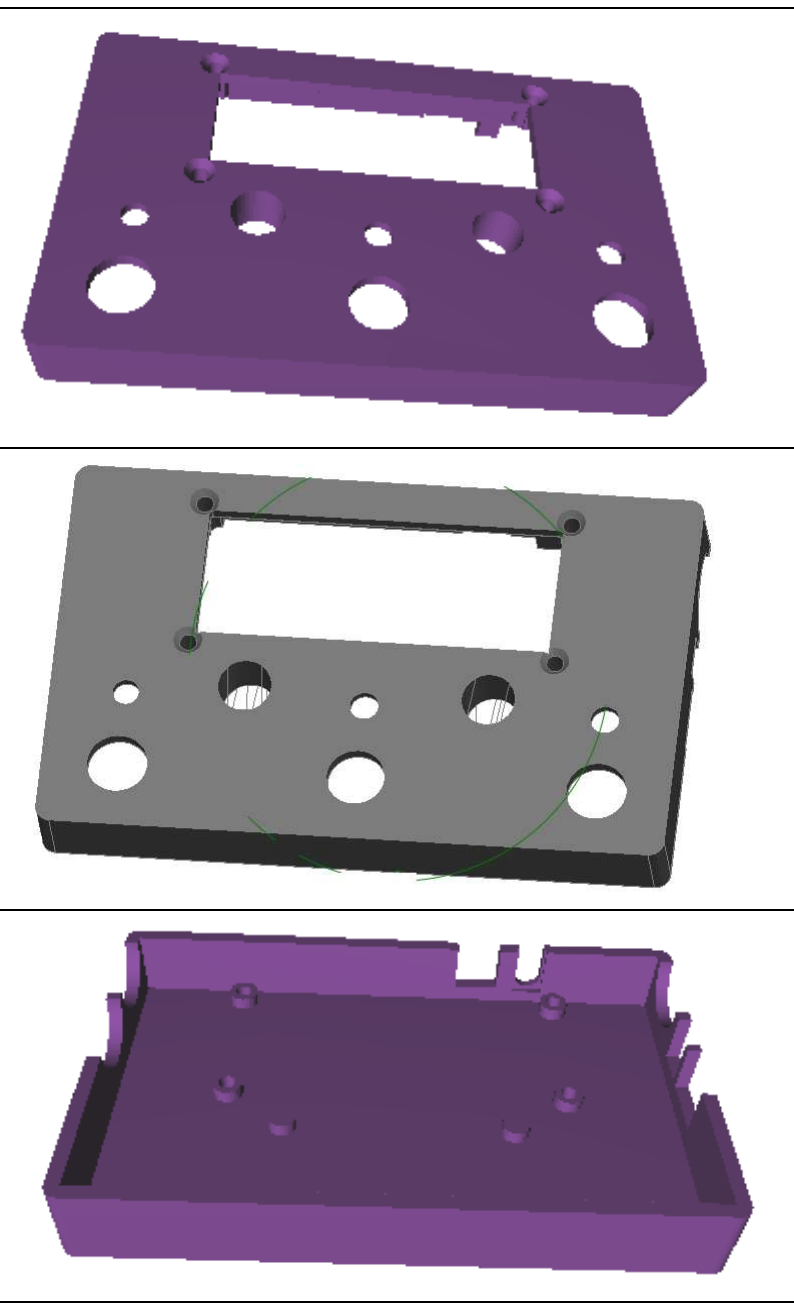
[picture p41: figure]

Upper cover Buydisplay: Link to stl: https://github.com/sixeight7/VController_v3/VC-mini hardware/Enclosure/ VCmini_upper_cover_Buydisplay_display.stl

Upper cover Adafruit: Link to stl: https://github.com/sixeight7/VController_v3/VC-mini hardware/Enclosure/ VCmini_upper_cover_Adafruit_display.stl

Lower cover: Link to stl: https://github.com/sixeight7/VController_v3/VC-mini hardware/Enclosure/ VCmini_lower_cover_b.stl

I use Innofil PLA black 2.85 mm on a Ultimaker 3 printer. The print quality setting is “draft”. This will have fewer layers, give a stronger result and reduce printing time. Probably ABS will give a stronger enclosure, but so far I have not experimented with this, as the 3D printer I make use of does not have the correct nozzle for that filament.

Putting it all together

Once the enclosure is ready and all the board has passed the hardware test, it is time to put everything together.

First solder the 2 pcb connection wires to the switches. The default length is a bit long, so I usually cut them in half.

First attach the display to the top half of the enclosure using the screw and the spacers:

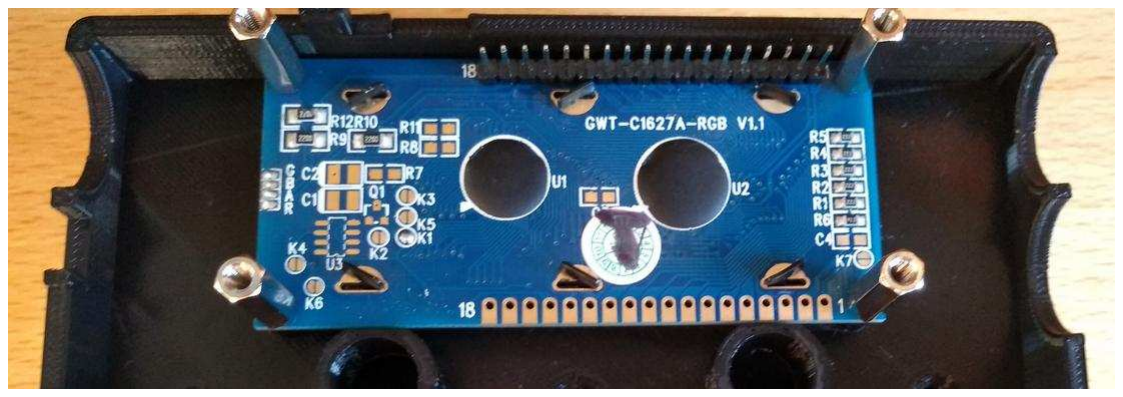
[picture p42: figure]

Now add the encoders to the PCB. Do not solder them, until the PCB is put in the enclosure and the rotary knobs are aligned with the holes in the enclosure.

Then add the switches:

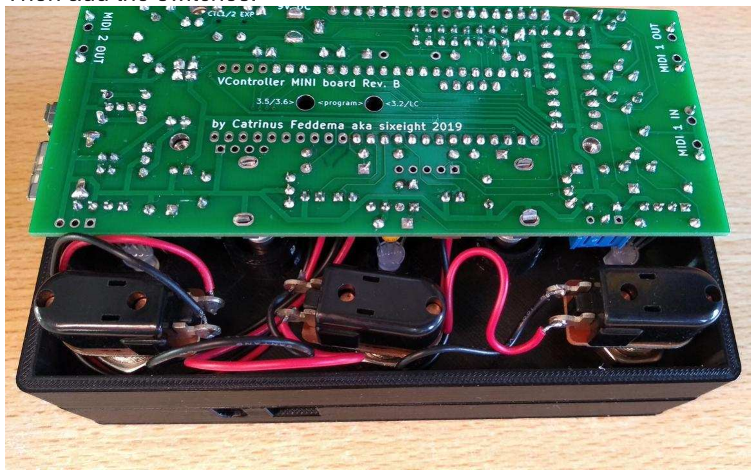
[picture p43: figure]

It should all fit nicely.

Firmware
There are two ways to install firmware. One is to use a pre-compiled hex file. The other way is to compile the data yourself, using the Arduino IDE.

Loading precompiled hex files to the Arduino:

In https://github.com/sixeight7/VController_v3/tree/master/Firmware/Compiled you can download the hex files for the test sketch and the VController firmware itself. Right click on the hex file and select Save as…

To install the firmware on the VController you need the following tool: https://www.pjrc.com/teensy/loader.html

Follow the instructions on the PJRC website to install the tool for you operating system.

To install the firmware, take the following steps:

1. Connect the VController or just the Teensy to your computer using a USB cable
2. Press the small button on the Teensy. It is now ready to receive firmware.
3. Start the Teensy loader. You should see the following three buttons:
4. Press the first button to open the hex file.
5. Press the second button to upload it to the Teensy.
6. Press the third button to reboot the Teensy. This should reboot the VController with the hardware test sketch or the Vcontroller firmware.

Compile the Teensy sketches yourself:

You will need to install Arduino IDE with the additional Teensyduino add-on: https://www.arduino.cc/en/main/softwarehttps://www.pjrc.com/teensy/teensyduino.html

You will need the correct LiquidCrystal library, which can be found here: https://bitbucket.org/fmalpartida/new-liquidcrystal/downloads/LiquidCrystal_V1.2.1.zip

Test sketch for hardware: to test the displays, LEDs and switches: https://github.com/sixeight7/VController_v3/tree/master/Firmware/Hardware_test_VC_PM

Firmware can be downloaded and installed from github: https://github.com/sixeight7/VController_v3/tree/master/Firmware/VController_v3

The first page of the VController gives instructions on how to compile the code for the full VController or for the VC-mini. Enable the correct hardware.h file and make the right settings in the Arduino IDE.

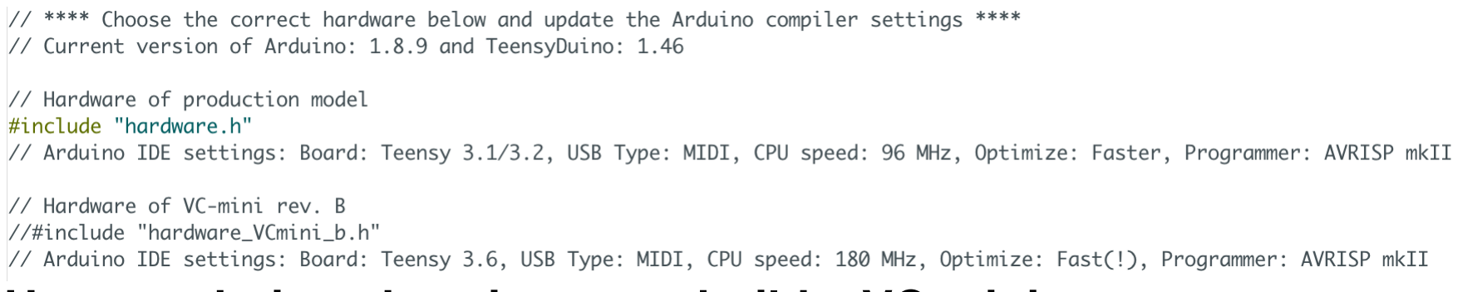
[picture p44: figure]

How much time does it cost to build a VC-mini:

Ordering of parts | 1 hours
Having enclosure and 3D printing done | 15 minutes
Building PCB | 2 hours
Putting it all together | 15 minutes
Testing and debugging | 30 minutes
Total time: | 4 hours

RRC2 cable:

To make an RRC2 to DIN-7 cable, I use an existing CAT 5 or CAT6 cable and replace one of the RJ45 connectors with a DIN-7 plug.

First check if the existing cable has been wired according to T-568A or T-568B standard, by checking if the colours match the correct diagram below. Then use the correct diagram for the DIN-7 side.

The view of the DIN-7 pin is the solder side of the plug.

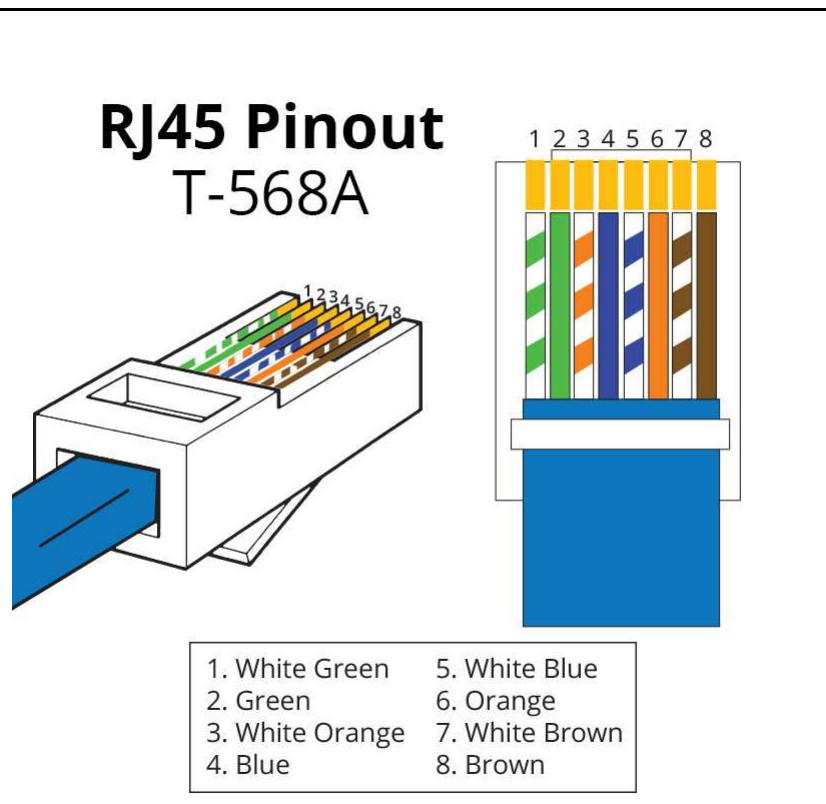
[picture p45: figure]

RJ45 side – T-568A | DIN-7 side

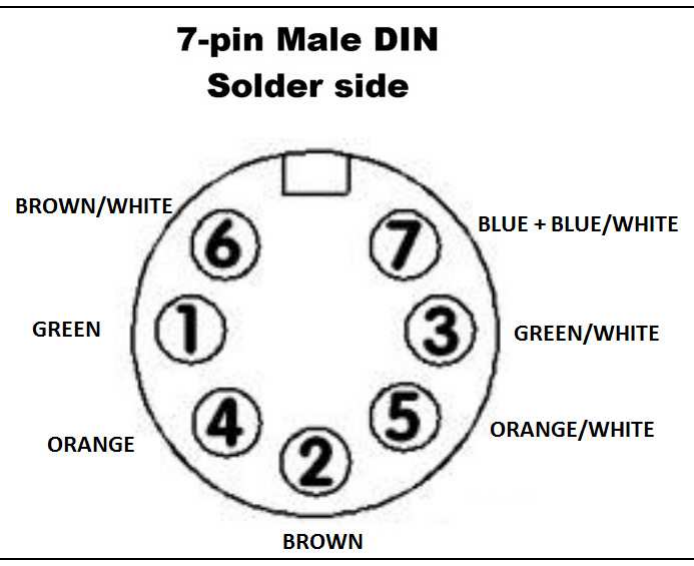
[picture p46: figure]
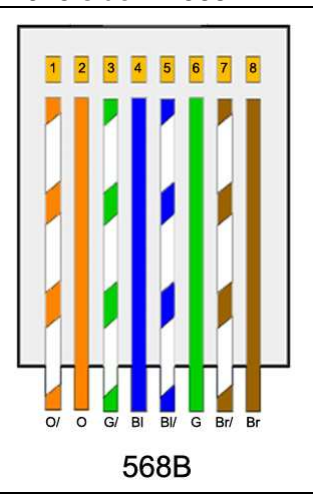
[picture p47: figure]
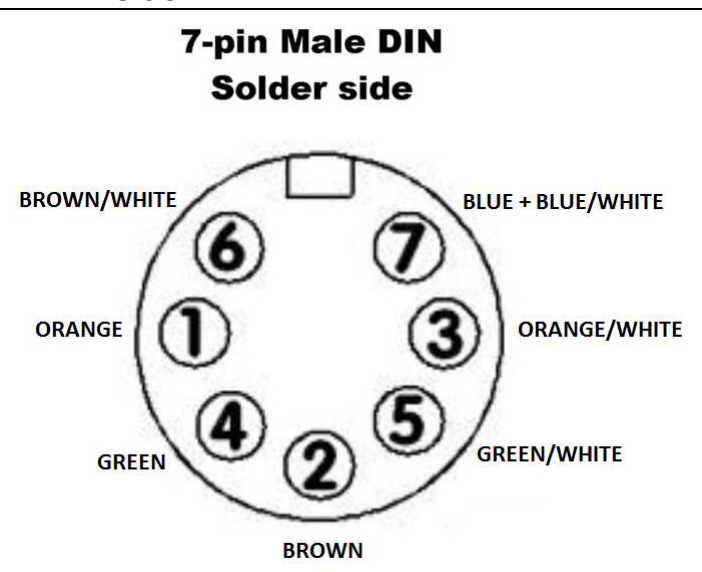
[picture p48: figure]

RJ45 side – T568B | DIN-7 side

Additional information:
Check out my blog at vguitarforums.com: http://www.vguitarforums.com/smf/index.php?topic=15154.0

I have spent countless hours since May 2015 developing the VController and the VC-mini. I would really appreciate a small donation: https://www.paypal.me/sixeight

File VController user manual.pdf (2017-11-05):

# V-Controller user manual

## Version 20171011

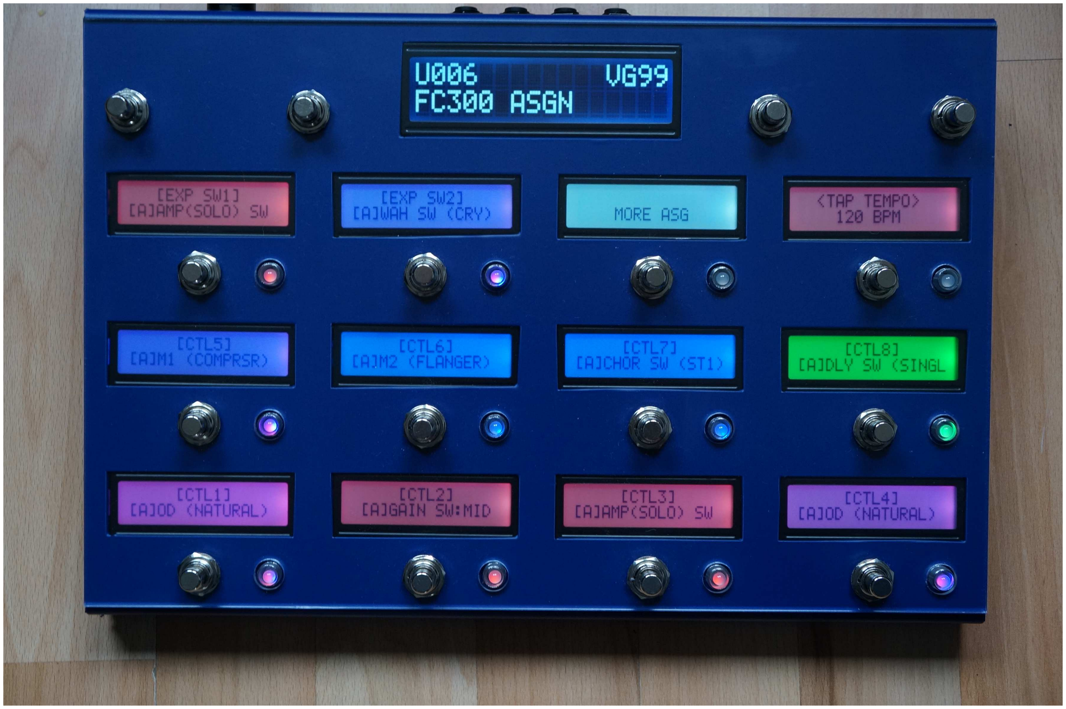
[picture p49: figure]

## By Catrinus Feddema (sixeight at vguitarforums.com)

Features:
- Advanced midi foot controller with 16 switches, 13 displays and 12 RGB LEDs.
- Two serial midi ports. Midi 1 has a midi out port with midi in and power on extra pins and a separate midi in port. Midi port 2 with parallel RRC2 port (for VG99)
- USB connector for MIDI and firmware updates.
- Connections for four expression pedals or dual switches. Automatically detects the type of pedal connected including if it is a normally open or normally closed external switch(es).
- Option slot for extra hardware. Currently developed:
- Raspberry pi board which will add four USB host ports!
- Currently supported devices:
- Boss GP-10
- Roland VG-99
- Roland GR-55
- Zoom G3
- Zoom MS70-cdr
- Features for these devices:
- Automatic detection when connected or disconnected
- Reading of patch names from these devices.
- Control of a number of parameters. For the most common parameters the names and current states are read from the devices.
- Control and active reading of assigns (Boss/Roland only)
- Colour coded effect types
- Global Tap Tempo: all devices pick up the tempo from the V-Controller. There is the option to keep this tempo on all patches on all devices.
- Global tuner for most devices (not possible on GR-55 or Zoom G3)
- US-20 simulation: smart muting of GP10, GR55 or VG99 by switching off the COSM guitar/synth/normal PU on the devices that are not active.
- The VController has the following switch types:
- Patch select
- Patch select in bank
- Bank up/down
- Previous patch / next patch
- Direct select
- Parameter control (momentary, toggle, three state, four state, five state, range, updown)
- Assign control (through cc or FC300 emulation for VG99)
- Mute/unmute
- Global tap tempo and set tempo
- Global tuner
- Select page
- Select next device
- Page up/down
- Midi PC/CC/note on/off
- Autobass mode: sends a CC message with the number of the lowest string that is being played (CC #15)
- Internal Raspberry Pi option slot or external Raspberry Pi box.

Making connections:

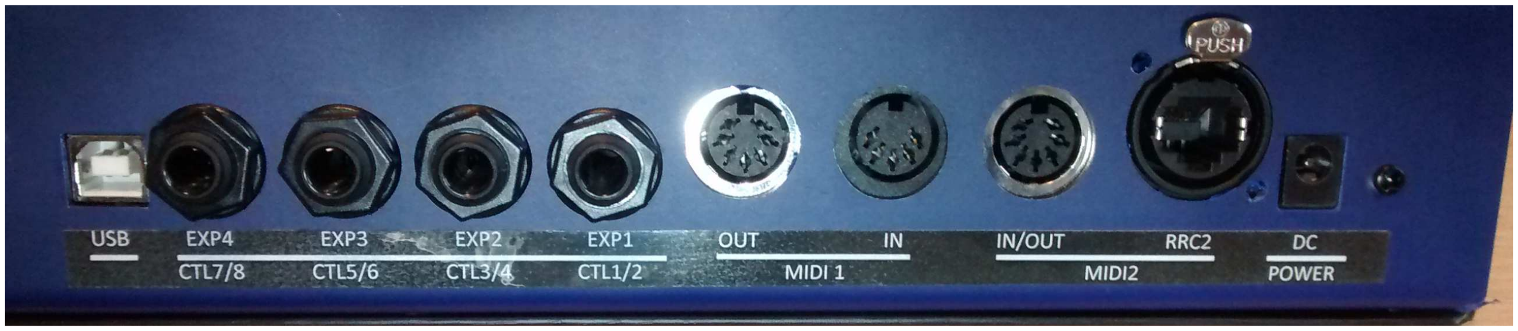
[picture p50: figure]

- USB – Use this port to connect the VController to a PC or Mac. The VController will act as a “class compliant” MIDI device. This USB port is also used for firmware upgrades.
- EXP1-4 / CTRL 1-8 – External input jacks. These support:
- An expression pedal (tested with Roland EV-5 and Roland DP-10)
- A normally closed single or dual switch.
- A normally open single or dual switch.

The type of pedal or switch is detected during power on of the VController. Make sure no external footswitch is pressed when switching on the VController.

- MIDI 1 OUT and IN – To connect to an external MIDI device.
- MIDI 2 IN/OUT and RRC – Midi 2 has in and out wires to the same connector. Details are below. RRC2: use only to connect to a VG-99. Do not connect anything to MIDI-2 in/out when RRC2 is in use!
- DC power jack: connect a “Roland-style” power supply rated at 9 V. The basic VController draws less than 1A. But with an internal or external Raspberry Pi, you will need more power, especially when the Raspberry Pi also powers other devices over USB. To be on the safe side a 2-3A power supply is recommended.

Power can be supplied through the DC power jack, through the RRC2 connector (from the VG99) or through the MIDI 1 or MIDI 2 7-pin connectors.

Always connect MIDI in and MIDI out as communication between the VController and the devices is bi-directional.

Wiring of midi connectors:

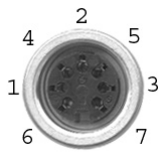
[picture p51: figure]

Midi 1 OUT/IN and midi 2 OUT/IN:

### 1. MIDI IN PIN + 2. Ground/Shield 3. MIDI IN PIN -4. MIDI OUT PIN + 5. MIDI OUT PIN -6. Power Positive (+9V) 7. Power Negative (GND)

Midi 1 IN:

### 1. No connection 2. No connection 3. No connection 4. MIDI IN + 5. MIDI IN -

Here is how you can connect the devices the VController supports:
Device | Connection
Boss GP-10 | USB host port on Raspberry Pi Serial midi via Primova MIDX-10/20
Roland GR-55 | Two serial midi cables to MIDI1 Midi splitter cable to MIDI1 out or MIDI2 out USB host port on Raspberry Pi
Roland VG-99 | RRC2 cable Two serial midi cables to MIDI1 in and out Midi splitter cable to MIDI1 out or MIDI2 out Serial midi to USB cable to Raspberry Pi (USB to Raspberry Pi does not work for FC300 assigns!)
ZOOM G3 | USB host port on Raspberry Pi
ZOOM MS70-cdr | USB host port on Raspberry Pi

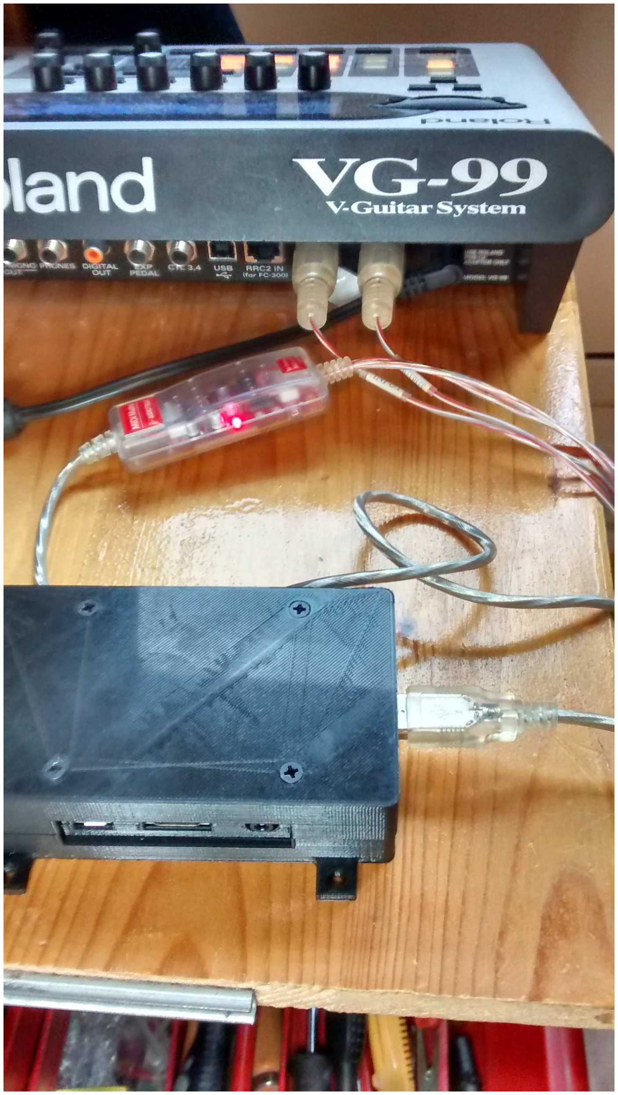
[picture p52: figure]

Note: Connecting the VG99 with a single USB cable to the Raspberry Pi has the limitation that the FC300 assigns do not work! For these assigns the VController mimics the FC300. The VG99 does not expect an FC300 to be connected to the USB host port, and therefore it does not work. As a solution you can connect the VG99 via a MIDI-to-USB adapter to the Raspberry Pi. Then the FC300 assigns work fine.

Raspberry Pi
One option is to have a Raspberry Pi (RPi) in the VController option slot. The internal MIDI3 connection is used to connect the RPi to the VController.

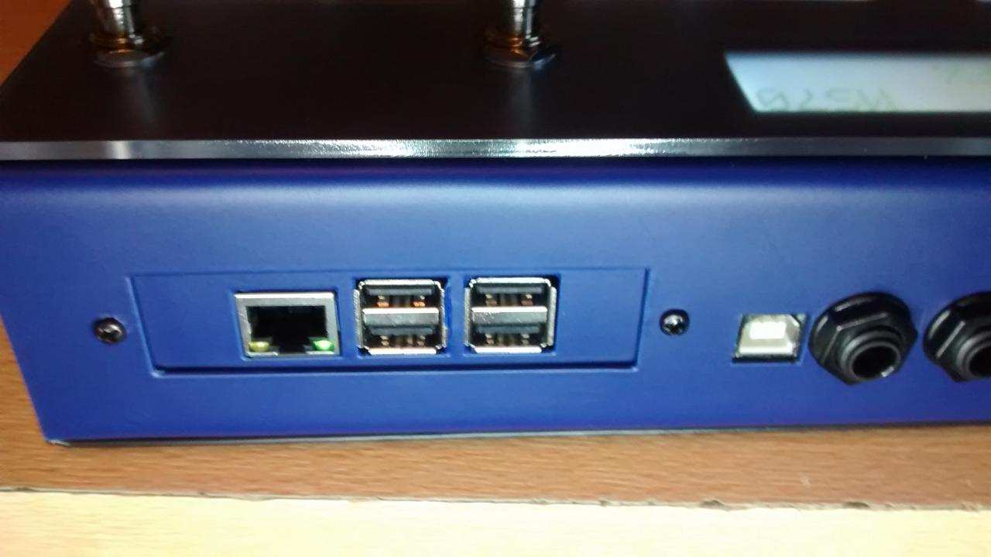
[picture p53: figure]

It is also possible to put the RPi with the VCBridge software in a separate box.

The external Raspberry Pi has the following connections:
- Midi IN/OUT is mainly used for MIDI IN, but has MIDI OUT and POWER OUT on extra pins. Always use this port to connect the VController with one wire!

- Midi OUT/IN is mainly used for MIDI OUT, but has MIDI IN and POWER IN on extra pins.
- DC POWER: use this pin to connect a Roland style power supply (9V, 1 Amps)
- Ethernet port: can be used to program the Raspberry Pi.
Do NOT use this port to connect to the RRC2 port of the VG99 or VController!
- Four USB host ports. You can connect these to GP10, GR55, GP10, G5 or MS70cdr. Also a USB to MIDI adapter can be connected here. The Raspberry Pi has not been tested with a USB host.
- 5V micro USB port. This port can also power the Raspberry Pi. It is not possible to remote power the VController through this port. You have to use the main 9V DC Power input for that
- HDMI. You can connect a HDMI monitor here. Together with a USB keyboard the Raspberry Pi can be programmed this way as well.
- 3,5 mm headphone jack. Is not used by the VController software.

When the Raspberry Pi is built inside the VController, only the Ethernet port and the USB ports are available on the outside. Power and MIDI are connected internally. The HDMI and headphone jack are not accessible.

You can hotplug devices to the USB ports or the serial MIDI ports. The RPi is actively detecting the connection of new USB devices.

Basic operation
The VController is switched on by pressing the top left switch. It is switched off by holding that switch for three seconds. Alternatively it can be switched on and off by a separate switch at the back. This is an extra hardware option.

The Raspberry Pi (RPi) is powered together with the VController when it is built in. With the RPi in a separate enclosure, the RPi is powered as soon as power is connected to it. After power is applied it will take around 20 seconds before the Linux operation system of the RPi has booted. A green LED will come on when the VCbridge software is running and the RPi is ready to pass on MIDI data to the VController.

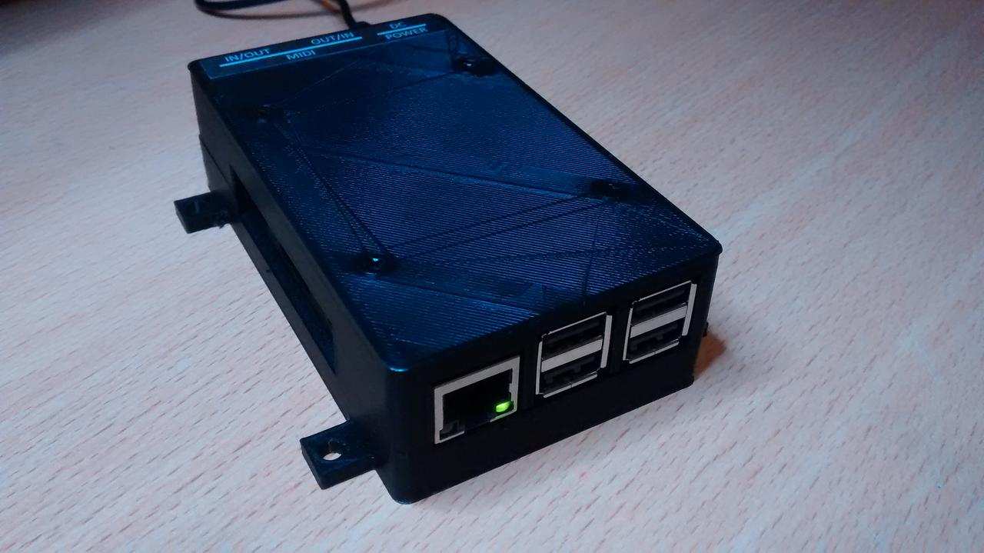
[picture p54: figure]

Whenever a supported device is connected to the VController, it will connect automatically as long as both MIDI in and MIDI out are connected. A USB connection is always bi-directional . The VController automatically reads the relevant patch names and parameter states of this device.

Multiple devices can be connected at the same time. It is best to use a different port for every device. All the USB ports on the RPi are seen as separate ports!!!

The VController sends midi data only to the port where the device is detected. This avoids midi buffer overruns when a lot of devices are connected. Also on the Raspberry Pi (internal or external) the midi data is only sent to the USB port that has a device connected. General MIDI data can be sent to all ports.

The VController has 16 internal switches and 8 external switches. Every switch can execute any number of commands on press. The configuration of all the switches is stored in a page. The VController has a number of fixed pages and a number of programmable pages.

The internal switches are numbered 1 to 16:

Switch 13 | Switch 14 | Switch 15 | Switch 16
Switch 9 | Switch 10 | Switch 11 | Switch 12
Switch 5 | Switch 6 | Switch 7 | Switch 8
Switch 1 | Switch 2 | Switch 3 | Switch 4

By default switch 13 – 16 have the following functions. This can be programmed otherwise:

Switch | Press | Long press
13 Bank down (patch/parameter select) | Patch down (assign page) | Open direct select Extra long press – power down
14 Bank up (patch/parameter select) | Patch up (assign page) | Open direct select
15 | Select next connected device | Open select page for programmed pages or menu
16 | Select next page of current device* | Open select page for programmed pages or menu

Select next page of current device: For every device three pages can be set. This switch toggles through the three pages. By default these are set to patch select, parameter select, assign select for Boss/Roland devices. For Zoom there is only one default page. In the device menu, you can change these device pages.

When you connect devices to the VController the first time, check if the midi channel of the device matches the settings on the VController.

Here are the default midi channels of the devices as set on the VController:

Device | MIDI channel
Boss GP-10 | 1
Roland GR-55 | 8
Roland VG-99 | 9
ZOOM G3 | 1
ZOOM MS70-cdr | 1

You can also change the MIDI channel on the VController in the device menu. To get to the device menu long press switch 15, then press MENU (switch 12) followed by Device Settings (switch 10). Note that the GP-10 only works on midi channel 1 and not on other channels. This is a bug in the GP-10. On Zoom devices the MIDI channel cannot be changed.

Once the midi channels match, you should be able to select patches on your devices from the VController.

Here are the MIDI settings I use on the VG99:

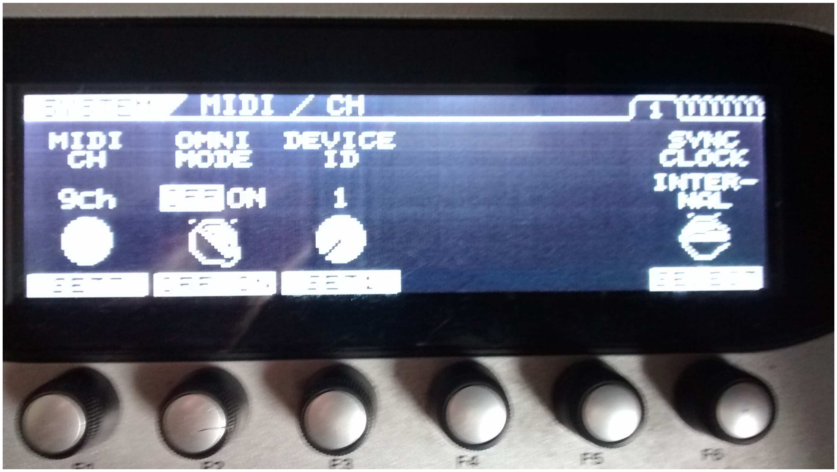
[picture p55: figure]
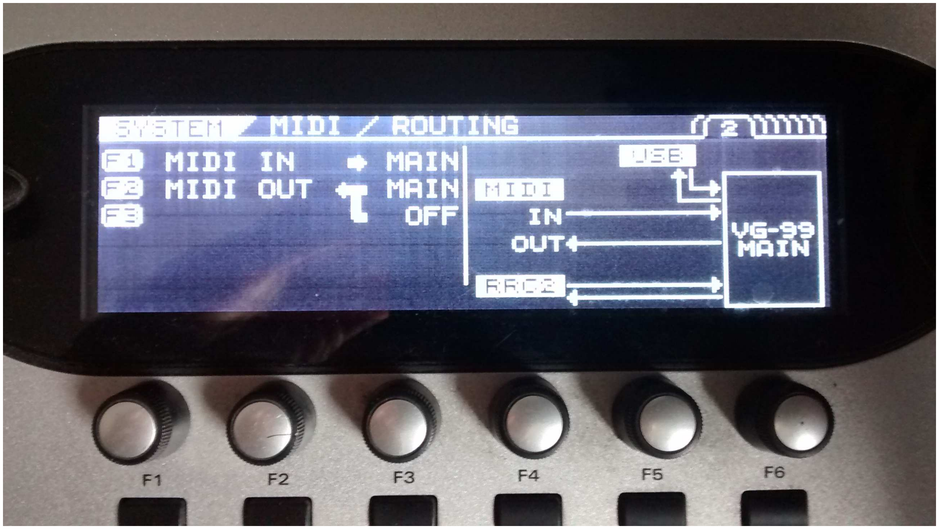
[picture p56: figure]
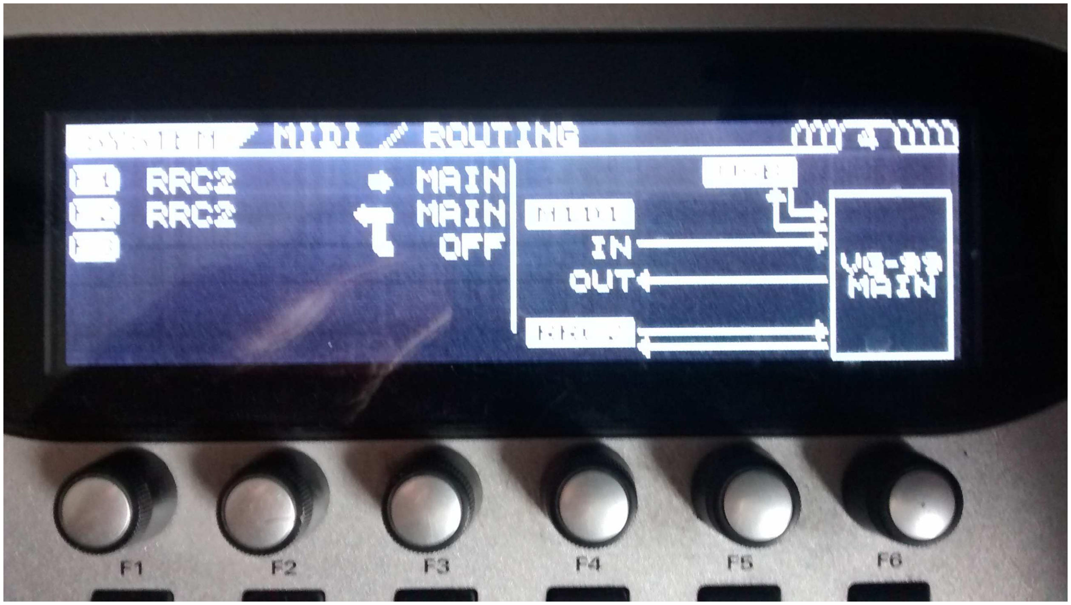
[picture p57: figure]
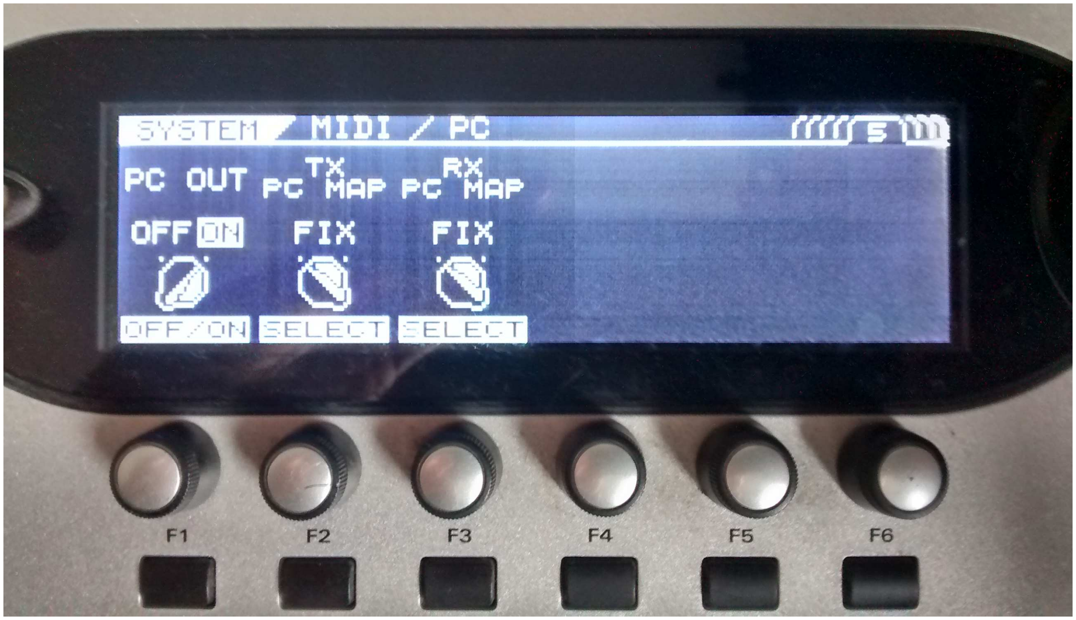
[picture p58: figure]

And here are my MIDI settings on the GR-55:

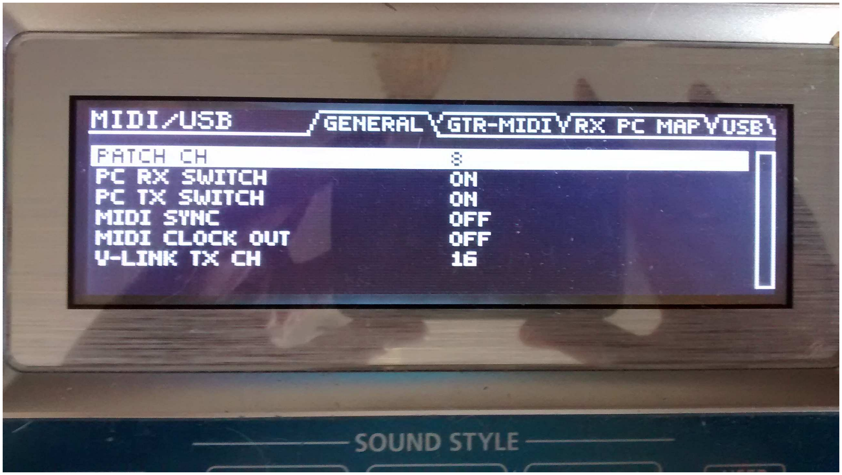
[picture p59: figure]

Pressing switches
The VController will detect the press and release of all its switches (also external). Some functions are triggered by long pressing a switch, holding it for 1 second. Powering down the VController is done by holding switch 13 for 3 seconds.
It is possible to hold switches that are programmed to control a parameter or cc. The speed of change is increasing as the switch is held down.

Navigating the VController

The VController is programmed with a number of fixed pages and with a number of programmable pages.

With the fixed pages it is possible to select a device (switch 15) and switch between the patches, parameters and assigns of this device (switch 16)

On a patch page switch 13 and 14 control BANK DOWN and BANK UP.
On a parameter page switch 13 and 14 will select the previous or next page of parameters.
On an assign page switch 13 and 14 will select the previous or next patch.

Direct select mode
Long pressing BANK UP or BANK DOWN will take you to direct select mode. Here you can type the number of the patch you want to go to. For devices with many patches (VG99) you can press bank up and down to move forward and backward 100 patches in direct select mode.

Controlling parameters
On a parameter page a select number of parameters are available to be changed. The memory of the VController is insufficient to support all possible parameters of a device. More parameters can be added in future firmware updates.
Parameters can the following types:
Type | Description
Momentary | Press activates and release deactivates parameter
Toggle | Activation and deactivation are toggled
Three state | Run through three values of the parameter
Four state | Run through four values of the parameter
Step | Run through any number of values with a programmable step size
Updown | Pressing will change direction. Holding it will change the value
Range | Used for expression pedals to change the value of the parameter between a minimum and maximum value

The switches on the fixed parameter pages are always of type toggle, step or up/down.

Controlling assigns

The VController can control assigns on the GP10, GR55 and VG99. Zoom devices do not have any assigns.

On all three devices assigns can be programmed. The VController activates the assigns through CC messages. The cc number of the assign on the device has to match the cc number of the assign on the VController.

Once the cc values match, the assign parameter will be read. When the parameter is known to the VController, its name will be shown on the display. If a parameter is unknown, it can still be controlled, but its name will not be displayed. Instead the assign number is shown.

For the VG99 a lot of extra assigns can be controlled. The FC300 CTL1 – 8 assign, the FC300 EXP1, EXP2, EXP SW1 and EXP SW 2 assigns can be programmed and controlled.

From the VG99 assign page you can choose “More assigns.” Here you can see the parameters that are set to all the internal assigns of the VG99. But these assigns cannot be controlled.

Navigating programmable pages
Long pressing switch 15 or 16 will take you to SELECT USER PAGE. Here you see the first 10 user pages and a switch for the MENU.

By default the VController has four example user pages:

Name | Description
GP + GR | To show an example how to navigate two devices on one page. Switch 15 and 16 will do BANK DOWN and BANK UP for the currently selected device. Its name is shown in the main display.
GPVGGR | To show an example how to navigate three devices on one page. Switch 15 and 16 will do BANK DOWN and BANK UP for the currently selected device. Its name is shown in the main display.
FUNCTION TEST | Will show a number of functions that can be programmed to switches
GEN MIDI TEST | Will show the possibilities of using MIDI PC/CC and NOTE ON/OFF commands. Also some custom labels are set.

Select a user page from this menu. On all example user pages switch 16 is reserved to go to the next user page (using the command NEXT_PAGE). Switch 15 will take you to the patch page of the next device. (You may want to reprogram switch 15 to PREV_PAGE if you want more flexibility in navigating the user pages.)

The default user pages serve as an example. You can program your own user pages to tailor the VController for your specific setup.

Global tempo/tuner
Global tempo will update the tempo on all connected devices. When Glob. Tempo on PC is enabled in the settings, all patches will inherit this tempo.

Long pressing global tempo will enable global tuner. Here all connected devices will go in tuner mode. The GR55 and Zoom G3 (v2) do not support this feature. Tuner mode cannot be triggered through any midi command on these devices.

Press any switch on the VController to exit global tuner mode.

US20 emulation
This feature works for GP10, GR55 and VG99. I have these devices connected through a passive GK splitter. US20 emulation allows me to select a patch on one device and have the sound on the other devices switch off. Here the GP+GR and GPVGGR example pages come in handy. Any patch on any device can be selected.

Pressing the switch of the active patch will display “GP10 can be mute” or “GP10 always on.” When a device is “always on”, it will not be switched off by US20 emulation. This will allow several devices to sound at the same time.

Bass mode

With bass mode, you can allow the GP10, GR55 or VG99 to play only the lowest played string of your guitar. You need a patch with a number of specific assigns on these devices to trigger bass mode. Bass mode is always enabled on the VController. It will just send a few cc messages to the device. In the patch you can determine through assigns if you want to act on those cc’s or not.

Bass mode will keep track of the lowest string that is played and send the number of that string as a CC number to a device. By default CC 15 is used for bass mode. Guitar to midi has to be switched on on the device for bass mode to work. Guitar to midi has to be in mono mode, not poly! Also chromatic should be switched on.

Here are my settings on each of the devices that support guitar-to-midi:

GP-10 | MIDI On/Off: ON Mode: MONO Chromatic: ON Pedal bend: OFF Data thin: OFF String Ch: 1 Dynamics: 10 Play Feel: FEEL 2 LowVeloCut: 4
GR-55 | Switch: ON Mode: MONO Chromatic: ON String ch: 1 Data thin: OFF The rest does not matter…
VG-99 | Gtr to midi: ON Patch/Mode: MONO Patch/Play feel: STRUM or FEEL4 Patch/Chromatic: TYPE2 System: Bend thin: OFF System: Basic Ch: OFF System: PC mask: OFF

The VController will use the device MIDI channel as has been set in MENU – DEVICE SETTNGS – MIDI channel

If you make the following assigns on the device, bass mode will switch the strings on and off, so that only the lowest string is heard.

Make five assigns that all have the following settings

Assign target | Assign source | Target min | Target max | Source mode | Act range low | Act range hi
String level 5 | CC #15 | 100 | 0 | MOMENT | 5 | 6
String level 4 | CC #15 | 100 | 0 | MOMENT | 4 | 5
String level 3 | CC #15 | 100 | 0 | MOMENT | 3 | 4
String level 2 | CC #15 | 100 | 0 | MOMENT | 2 | 3
String level 1 | CC #15 | 100 | 0 | MOMENT | 1 | 2

Use these assigns to control the sound of a bass guitar and the bass note will be automatically added to the chord you are playing

If you only want to control three strings, only make the first two assigns and set the level of the top three switches to 0 in the patch.

You can download some example bass mode patches for GP10 / GR55 and VG99 from here:
https://github.com/sixeight7/VController_v3/tree/master/bass%20mode%20patches To download right button mouse click and choose Save as…

In the GLOBAL SETTINGS you can make specific settings for Bass mode.

I have had the best experience with the GP-10 with velocity setting of 50 and the GR-55, with a velocity setting of 100 on the VController. Also it often helps to disable the assigns for the highest two or three strings (B-E or G-B-E) as they are not really bass notes. This helps to avoid false triggers.

VController menu’s

Long pressing switch 15 or 16 will take you to SELECT USER PAGE. Here you can select MENU (switch 12.)

You can select the following menu’s:

GLOBAL SETTINGS

US20 Emulation | See US20 emulation
Glob. Tempo on PC | When enabled the global tempo will be written to all connected devices when a patch change is made. This way all patches will keep the same tempo even if you go from one patch to another.
Main display mode | Will determine if the second line of the main diplsay will show he PAGE NAME, PATCH NAME or PATCHES COMBINED. The last option shows a number of characters of all the patches that are currently active and on (in US20 emulation)
Bass mode G2M channel | The Guitar to midi channel (default: 1)
Bass mode device | The device that is used for bass mode
Bass mode CC | The cc number that is used to control bass mode on through assigns on the device (default CC #15)
Bass mode vl | The minimum velocity that is needed to activate a string. Set this value lower if Bass mode does not respond. Set this value higher if higher payed strings are not blocked through bass mode.
SAVE & EXIT | Save changes and exit
Cancel | Do not save changes and exit

DEVICE SETTINGS

Select device | Will select a device.
Midi channel | Set the midi channel of the selected device. Note that GP10, G3 and MS70-cdr have to be on channel 1, otherwise patch change will not work.
Colour | Set the colour of patch select LEDs (or backlights) for this device
Is always on | Part of US20 mode.
Device page #1 Device page #2 Device page #3 | Pressing switch 16 on the VController will toggle on default between patch/parameter and assign pages. Here you can set other pages (also user pages!) that will be selected by pressing switch 16.
SAVE & EXIT | Save changes and exit
Cancel | Do not save changes and exit

LED SETTINGS

FX COLOUR MENU | Will open a menu where you can set the effect colours by effect category.
LED brightness | Will set the brightness of the neopixel LEDs. Usually set low as these can be very bright! 255 really hurts my eyes.
Backlight Bright | Brightness of RGB backlights (only works for RGB model)
Virtual LEDs | Show LED state in displays!
FX off is dimmed | When enabled an FX LEDs will dim when it is switched off. This way you can see the colour of the effect type. When disabled an FX LEDs will switch off when it is switched off.
Global colour | Colour used for page and menu selection
BPM colour | Colour of the tap tempo and set tempo LED
MIDI PC colour | Colour of a MIDI PC LED
MIDI CC colour | Colour of a MIDI CC LED
MIDI note colour | Colour of a Midi note LED
SAVE & EXIT | Save changes and exit
Cancel | Do not save changes and exit

PROGRAM SWITCHES
See chapter Programming the VController for details

FIRMWARE MENU

Init settings | Will initialize all menu settings to their default values
Init commands | Will initialize all programmed commands to the four example pages that were on the VController when you first got it.
Program mode | Will put the Vcontroller in firmware upgrade mode. See Firmware upgrade for details.
EXIT | Will exit this menu

Programming the VController

On the VController you can program 3000 commands on 200 user pages. Any switch can execute any number of commands. Both internal and external switches (and expression pedals) can be programmed

When you press a switch on the VController it will check if there are any commands programmed on the current page for this switch. If no commands are found, the VController will check if there is a command on the default page and execute that one.

I usually program the external switches on the default page. This way these switches will perform the same action on any page. But you do have the option to “override” default behavior on certain pages by programming a command for these switches on these pages. This allows for a very flexible setup.

PROGRAM SWITCHES

PAGE | Select a page you want to edit. You can also choose the default page or a new page here.
SWITCH | Select the switch on the page. You can choose internal switches, external switches or “on page select” here.
COMMAND | The command you want to edit
EDIT PAGE NAME | Here you can edit the name of the selected page
EDIT SWITCH NAME | Here you can edit the label of the selected switch
EDIT COMMAND | Press this switch to edit the command
MORE… | To clear pages, switches, labels or commands
DECREASE VALUE | Will decrease the value of the last selected parameter (page, switch or command)
EXIT | Will exit this menu

Pressing EDIT COMMAND will take you to the following menu:

PROGRAM SWITCHES

DEVICE | Common Functions, GP10, GR55, VG990, G3, MS70cdr or Current device. Use current device to make one page suitable for several devices.
COMMAND | Select a command
Parameters… | Depends on the command
DECREASE VALUE | Will decrease the value of the last selected parameter (device, command or parameter)
SAVE CMD | To save the command
EXIT | Will exit this menu

The VController has the following common functions:

Command | Parameters | Description
NO COMMAND | -
SELECT PAGE | Page name
PAGE UP | - | Go to the next user page
PAGE DOWN | - | Go to the previous user page
TAP TEMPO | - | Global tap tempo
SET TEMPO | BPM | Set global tempo to specified value
GLOBAL TUNER | - | Enable global tuner
MIDI PC | Program, channel, port | Send a MIDI program change message to the specified channel and port. Set port to ALL PORTS when port is unknown.
MIDI CC | Number, toggle type, max, min, channel, port

Send a MIDI continuous controller message to the specified channel and port. Set port to ALL PORTS when port is unknown.

Toggle types:
ONE SHOT: send max value on press, nothing on release
MOMENTARY. Send max value on press and min value on release
TOGGLE: Send max and min value on subsequent presses
TOGGLE_ON: Same, but default LED state is on.
RANGE: use this for expression pedals STEP: first press sends min value. Every subsequent press increases value by one until max value is reached.
UPDOWN: change parameter between min and max value by holding the switch
MIDI note | Note, velocity, channel, port | Send a MIDI note message to the specified channel and port. Press sends note on message. Release sends not off message
NEXT DEVICE | - | Select the next connected device

Device commands:

Command | Parameters | Description
PATCH SELECT | Patch number, patch bank (100) | To select a patch. To select patch number 314 set patch bank to 3 and patch number to 14.
PARAMETER | Parameter, Toggle type, Value(s) | Control a fixed parameter on the device. Toggle types: MOMENTARY. Send max value on press and min value on release TOGGLE: Send max and min value on subsequent presses

| | TRISTATE: Select one of three values to the device. FOURSTATE: Select one of four values to the device. STEP: first press sends min value. Every subsequent press increases value by the value entered under step until max value is reached. RANGE: use this for expression pedals UPDOWN: change parameter between min and max value by holding the switch
ASSIGN | Assign, trigger | To control an assign on a device. When selecting an assign a default trigger is given. You can choose other cc-numbers if you prefer, but for FC300 controls on the VG99 the default triggers have to be used.
PATCHBANK SELECT | Number, bank size | To select a patch in a bank. Command is used together with BANK UP and BANK DOWN
BANK UP | Bank size | Display the next bank of patches on the PATCHBANK SELECT switches
BANK DOWN | Bank size | Display the previous bank of patches on the PATCHBANK SELECT switches
NEXT PATCH | - | Go to the next patch
PREV PATCH | - | Go to the previous patch
MUTE | - | Mute the device (US20 mode)
SEL DEVICE PAGE | Page | Selects a page and sets the current device.
SEL PAGE PATCH | - | Go to DEVICE PAGE #1 (see Device settings)
SELECT PAGE PAR | - Go to DEVICE PAGE #2 (see Device settings)
SELECT PAGE ASSIGN | - Go to DEVICE PAGE #3 (see Device settings)

Firmware updates.

Find the latest firmware for the VController on Github: https://github.com/sixeight7/VController_v3/tree/master/Firmware/Compiled

In this folder you can download a hex file. Right click on the hex file and select Save as…

To install the firmware on the VController you need the following tool: https://www.pjrc.com/teensy/loader.html

Follow the instructions on the PJRC website to install the tool for you operating system.

To install the firmware, take the following steps:

### 1. Connect the VController to your computer using a USB cable 2. On the VController go to the MENU and choose FIRMWARE MENU – Program

Mode. The VController is now ready to receive the firmware.

### 3. Start the Teensy loader. You should see the following three buttons:

4. Press the first button to open the hex file.

### 5. Press the second button to upload it to the VController 6. Press the third button to reboot the VController. This should reboot the

VController with the new firmware.

The procedure above describes how to upload already compiled firmware to the VController. There will be a guide soon, that will show you how to install the full Arduino IDE and the procedure to compile and upload the firmware yourself.

Updating the Raspberry Pi

You can contact me to download a newer version of the RPi configuration. I am still developing a good way to offer these images online.

The default password for Debian Jessie is on the RPi (user: pi, password: raspberry). Proceed at your own risk.

Specifications

VController:

Weight | 3.350 grams
Dimensions: | 343 x 232 x 70 mm
| (depending on bends and switches)
DC power: | 9V at 500mA (1A with internal RPi)
Measured current: | 240 mA (basic model with Buydisplay displays)

RPi enclosure:

Weight: | 175 grams
Dimensions: | 114 x 85 x 33 mm
DC power: | 9V at 500mA (1A with VController powered as well)
| 5V at 1A though the micro USB is also possible, but
| the VController cannot be powered this way.
Measured current: | 150 mA (with no external devices connected)

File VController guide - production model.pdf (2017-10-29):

V-Controller production model building guide
- First beta version -
By sixeight at vguitarforums.com

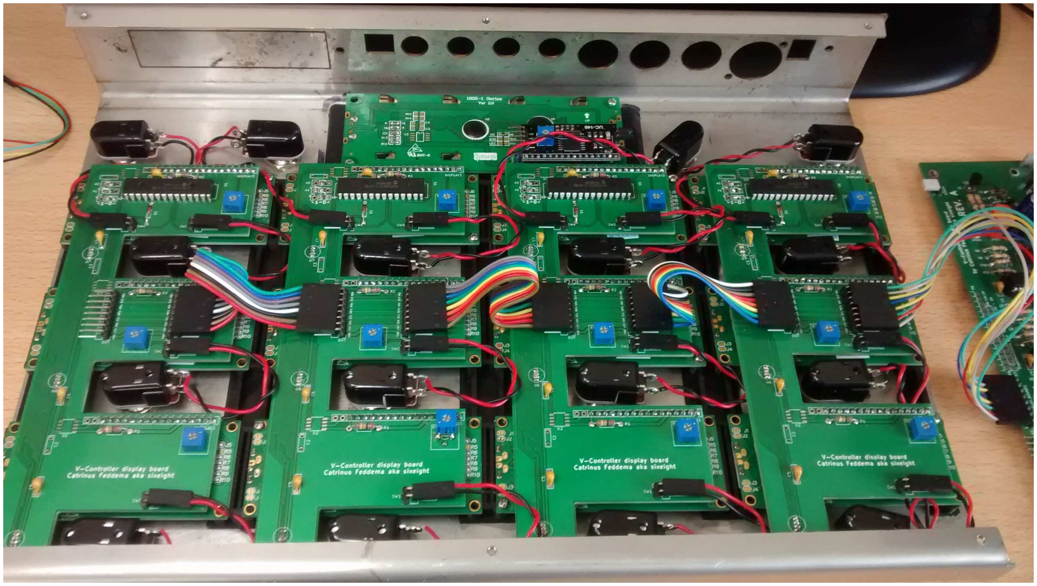
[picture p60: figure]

Introduction
Here is a quick guide for building the V-Controller, a dedicated MIDI controller for Boss GP-10 / Roland GR-55 / Roland VG-99 / Zoom G3 and Zoom MS70-CDR. Building this device should cost around 20 - 40 hours and $200 - 400 for parts, depending on the cost for the enclosure.

Features of the V-Controller:
Check out the VController User Guide for features.

Main parts of the VController:
The VController has the following main parts:
- Enclosure of sheet metal with 3D printed supports for the displays
- Main PCB board with Teensy and all the connectors.
- 4 display PCB boards with 12 displays and Neopixel LEDs connected. Also 16 footswitches connect to the these boards
- 1 main display connected to a i2c module
- Option board: Raspberry Pi model B+ adding 4 USB host ports.

Additional documents – see https://github.com/sixeight7/VController_v3:
- PDF, DWG and step files for the enclosure:
- STL files for the 3D printed files:
- PDF and gerber files of the PCBs

Options for parts:
The following options are available for the VController:
- Type of display: LCD monochrome or LCD RGB color. The RGB color option has not been build, tested or implemented yet.
- Position of on/off switch – at the back or using one of the top switches.
- Enclosure: spray paint, spray coating or wrapped.

Parts list: Enclosure

Reference | Number | Part | Where to get
| 1 | Metal enclosure | DIY
| 1 | Large LCD support | DIY
| 3 | Small LCD support | DIY
| 2 | Half small LCD support | DIY
| 52 | 2,2mm x 6,5mm screws for LCDs | Conrad: 839536 - 8J Microschroeven.nl
| 10 | M3 screws | reichelt.de: SKL M3X10-50
| 1 | Coloured plastic wrapping
| 1 | large 16x2 LCD character display ERM1602DNS-1-5V | Buydisplay.com: ERM1602DNS-1-5V
| 1 | I2c module | ebay
| 1 | 4 pin 20cm 2.54mm Female to Female jumper wire Dupont cable | Ebay – can also be 2x 2pin jumper wire.

Parts list: four PCB displays

Reference | Number | Part | Where to get
U1 | 4 | MCP23017 | Conrad.nl: 651440 - 89 reichelt.de: MCP 23017-E/SP (large)
Display1-3 | 12 | 16x2 LCD character displays ERM1602DNS-4-5V | Buydisplay.com: ERM1602DNS-4-5V
Display1-3 | 12 | RGB backlight Positive or negative LCD 16x2** | Adafruit: 398 or 399
Display1-3 | 12 | 16 pin* or 18 pin** header | reichelt.de*: SL 1X50G 2,54 (x4) reichelt.de**: SL 1X36G 2,54 (x6)
Display1-3 | 12 | 16 pin female header 18 pin female header** - cut to size The BL 1x20G is less high!!! | reichelt.de: MPE 094-1-016 reichelt.de: BL 1X20G 2,54 (pins) or 40 pin female headers from ebay
U2-U4 | 12 | WS2811** | Adafruit: 1378
U5-U7 | 12 | Neopixel LED 5mm (Neopixel or PL9823 F5) | Adafruit: 1938 Ebay (search for PL9823 F5)
U5-U7 | 12 | Female header 2.54 mm, 1x4 straight Or 4 pin male header | reichelt.de: MPE 115-1-004 or reichelt.de*: SL 1X50G 2,54 (x1)
U5-U7 | 12 | 5mm Chrome Plastic LED Bezel Holder | ebay
C1 – C7 | 16* or 28** | Capacitor 100n | reichelt.de: KERKO 100N
SW1-4 | 16 | Footswitch | http://www.ebay.com/itm/271930278587
SW1-4 | 16 | 2 pin angled header (for switch) | reichelt.de: SL 1X40W 2,54
SW1-4 | 8 | 2 pin 20cm 2.54mm Female to Female jumper wire Dupont cable | ebay
RV2 | 4 | 10k trimmer 10 mm horizontal | reichelt.de: 76-10 10K
R1-3 | 12 | Resistor 100 Ohm* | reichelt.de: 1/4W 100
P1, P2 | 8 | 8 pin angled header | reichelt.de: SL 1X40W 2,54
P1 | 1 | 8 pin 20+cm 2.54mm Female to Female jumper wire Dupont cable | Could also be 2 4 pin cables
P1, P2 | 3 | 8 pin 10cm 2.54mm Female to Female jumper wire Dupont cable | ebay

* Only for monochrome display
** Only for colored display

Parts list: PCB main

Reference | Number | Part | Where to get
U1 | 1 | Teensy 3.2 | https://www.pjrc.com/store/teensy32.html reichelt.de: TEENSY 3.2
U1 | 2 | 14-pin strips (male and female) for holding the Teensy in place – cut to size | reichelt.de: BL 1X20G 2,54 (pins)
U2, U3 | 1 | 6n137 optocoupler | reichelt.de: 6N 137
U4 | 1 | uA7805 Voltage regulator or 5V buck converter (when Rpi is in the option slot) | reichelt.de: L 7805 CV ebay: 5V buck convertor – check if pinout corresponds to the image on the left.
U5 | 1 | 24LC512 I/P serial EEPROM | reichelt.de: 24LC512-I/P
U2, U3, U5 | 3 | 4x 8 pin IC socket | reichelt.de: GS 8
JK1, JK3 | 2 | 7 pin din socket (MIDI) Cliff FM6727 Pro Signal PSG03465 | Farnell: 1791759 or 2679728 reichelt.de does not stock these. Could use 5 pin instead if power is not needed
JK2 | 1 | 5 pin din socket (MIDI) Pro Signal PSG03463 | Farnell: 1791756 reichelt.de: MABP 5S
J1 | 1 | RRC2: Neutrik NE8FAH (screws not included) | Farnell: 3886256
J1 | 2 | 2 screws: self tapping 2.9 x 1.05 tri-rondular configuration, 8 mm long, panhead (Neutrik A-SCREW-1-8) | Thought the official Neutrik screws were way overpriced. Found similar screw on ebay.
JK4, JK5, JK6, JK7 | 4 | jack socket 6.35 mm stereo Neutrik NR-J6HF | reichelt.de: NEUTRIK NR-J6HF
JK4, JK5, JK6, JK7 | 4 | jack mounting nut Neutrik NR-JNUTB | reichelt.de: NEUTRIK NR-JNUTB
JK8 | 1 | Power barrel – centre pin 2 mm | reichelt.de: LUM NEB 21R Farnell: 1737246
JK9 | 1 | 1x USB male socket type B | reichelt.de: USB BW
Q1 | 1 | IRF9530 P-channel MOSFET | reichelt.de: IRF 9530
Q2 | 1 | BC547 transistor or similar | reichelt.de: BC 547C
Q3, Q4 | 2 | 2N7000 MOSFET TO92 | reichelt.de: 2N 7000
D1, D2, D4, D8 | 4 | 1N5817 shottky diode | reichelt.de: 1N 5817
D3,D5, D6, D7 | 4 | 1N4148 diode | reichelt.de: 1N 4148
SW1 | 1 | Power switch | Anything you like – drill your own hole or use a regular footswitch…
C1 | 1 | 220 uF capacitor, >=16V | reichelt.de: RAD FR 220/35
C2 | 1 | 100 uF capacitor, >=16V | reichelt.de: RAD FR 100/35
C9 | 1 | 10 uF capacitor, >=16V | Reichelt: SM 10/16RAD
C7 | 1 | 4,7 uF >= 16V | Reichelt: SM 4,7/50RAD
C3, C4 C5,C6 | 4 | 100 nF capacitor | reichelt.de: KERKO 100N
R1, R6, R7, R8 | 4 | 47 resistor | reichelt.de: 1/4W 47
R2, R3, R38, R39 | 4 | 10k resistor | reichelt.de: 1/4W 10K
R13, R14 | 2 | 2k2 resistor | reichelt.de: 1/4W 2,2K
R15, R16 | 2 | 3k3 resistor | reichelt.de: 1/4W 3,3K
R4, R5 | 2 | 220 resistor | reichelt.de: 1/4W 220
R9, R10, R17, R34, R36, R37 | 6 | 4k7 resistor | reichelt.de: 1/4W 4,7K
R35 | 1 | 100k resistor | reichelt.de: 1/4W 100K

R18-R24, R26, R28,R30, R32 | 3 | Resistor network 4 res./8 pin 4k7 | reichelt.de: SIL 8-4 4,7K
R27, R29, R31, R33 | 1 | Resistor network 470k | reichelt.de: SIL 8-4 470K
P1, P2, P3, P4, P5, P6, P8 | 2 | 5 + 5 + 4 + 4 + 8 + 12 + 3 = 41 pins in angled pin strips | reichelt.de: SL 1X40W 2,54
P12, P13 | 1 | M3 PCB Holder | http://nl.rs-online.com/web/p/screw-terminals/6142425/ (small numbers) https://www.ettinger.de/en/product/13.42.320 (large quantities)

Parts list: Option board Rpi (internal)

Reference | Number | Part | Where to get
U1 | 1 | Raspberry Pi model B+ | reichelt.de: RASPBERRY PI B+
U1 | 4 | Distance sleeve (3-5mm) | reichelt.de: DK 5mm
U1 | 1 | Micro SD card 16 Gb class 10 | reichelt.de: INTENSO 3433470
| 1 | Bracket
| 1 | Connecting wire – could be 4 pin Dupont

Parts list: Option board Rpi (external)

Reference | Number | Part | Where to get
| 1 | Raspberry Pi model B+ | reichelt.de: RASPBERRY PI B+
| 1 | Micro SD card 16 Gb class 10 | reichelt.de: INTENSO 3433470
| 1 | Enclosure (3d printed)
U1 | 1 | 6n137 optocoupler | reichelt.de: 6N 137
U2 | 1 | 74HC14 6xinv. Smitt trigger | reichelt.de: 74HC 14
U3 | 1 | 5V buck converter | ebay: 5V buck convertor – check if pinout corresponds to the image on the left.
CON1 | 1 | Power barrel – center pin 2 mm | reichelt.de: LUM NEB 21R Farnell: 1737246
| 2 | 7 pin din socket (MIDI) Cliff FM6727 Pro Signal PSG03465 | Farnell: 1791759 or 2679728 reichelt.de does not stock these. Could use 5 pin instead if power is not needed
P2 | 1 | Female header 2x20 pin | reichelt.de: MPE 094-2-040
D1, D3, D4 | 4 | 1N5817 shottky diode | reichelt.de: 1N 5817
D2 | 1 | 1N4148 diode | reichelt.de: 1N 4148
C2 | 1 | 100 uF capacitor, >=16V | reichelt.de: RAD FR 100/35
C3 | 1 | 10 uF capacitor, >=16V | Reichelt: SM 10/16 RAD
C1, C4 | 2 | 100 nF capacitor | reichelt.de: KERKO 100N
R1, R4, R5 | 3 | 220 resistor | reichelt.de: 1/4W 220
R2 | 1 | 4k7 resistor | reichelt.de: 1/4W 1,8K
| 4 | 12mm spacer | reichelt.de: DI 12mm
| 4 | M3 x 12mm (black) | ebay
| 4 | M3 x 16mm (black) | ebay

Cable for external RPi
2 | Neutrik NYS323G 7 pin plug | Farnell: 8020442
| Tasker C281 7x0,25 mm² audio cable | Or something similar

Power supply (optional)
1 | Compact switching power supply, 18W, out 9V

Reichelt.de: PSAA 18U-090

Enclosure
See https://github.com/sixeight7/VController_v3/tree/master/Enclosure/Metal. There are three parts to the enclosure:
- Top plate
- Bottom plate
- RPi expansion board bracket

There are two versions of the Top plate of the VController:
- top plate VController_mk4_05122016
- top plate VController Adafruit displays

The difference is in the size of the holes for the displays. I found Adafruit displays (both monochrome and RGB) to have a slightly larger bezel than the Buydisplay ones. Make sure you use the Adafruit version of the top plate when you have those displays.

The dwg files show flat versions of each of these boards. Extra space for bending has been taken into account, but different type of metal may give different results.

You may want to give the VController_mk4.step file to a metal company and let make their own design for the flat version of the enclosure. That way they can be sure the extra space for making the bends is compatible with the materials and tools used.

I found a metal company that does laser cutting to build the enclosure for me. Bending the enclosure was done at a different place, but it would be wise to have both done at the same place. See additional documents for building plans for the enclosure.

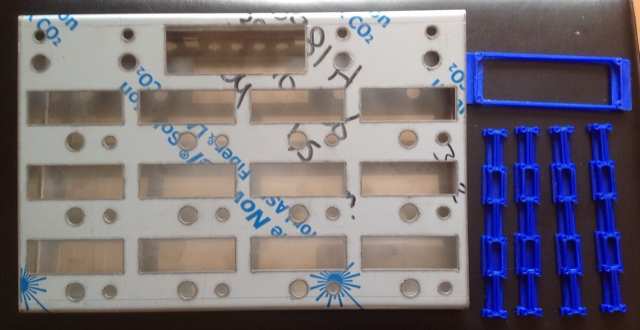
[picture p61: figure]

After the board is made, you may have to do some filing to get it smooth on all sides. Laser cutting often leaves some melted metal bits left on the enclosure.

You can take out the piece of metal for the option board slot if you need it. With a chisel and a hammer it is very easy to get it out.

3D printing:
See https://github.com/sixeight7/VController_v3/tree/master/Enclosure/3D%20printing:

The holes in the 3D design are 2 mm, but turned out to be slightly smaller when printed. The preferred color for the filament is black. I use Innofil PLA black 2.85 mm on a Ultimaker 3 printer. The print quality setting is “draft”. This will have fewer layers, give a stronger result and reduce printing time. The display supports will be out of view, so there is no reason to go for high quality fine layer settings.

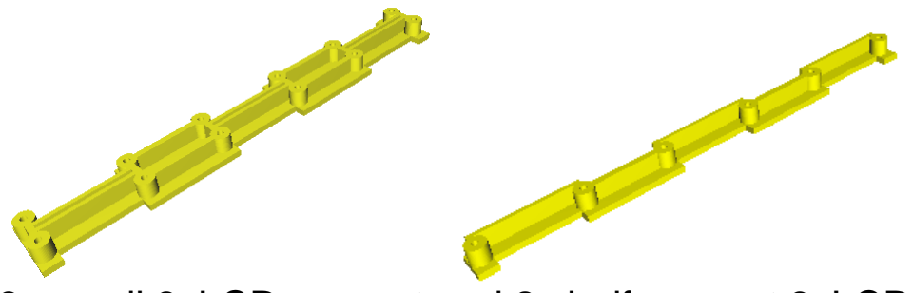
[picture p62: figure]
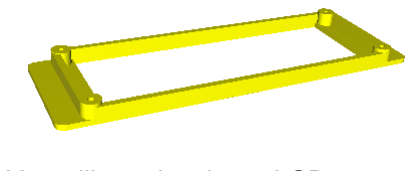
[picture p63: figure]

You will need 1x large LCD support, 3x small 3xLCD support and 2x half support 3xLCD. Or alternatively you could print four small supports and cut one in half. If you have Adafruit displays, make sure you print the Small 3xLCD support Adafruit stl. This one is easily breakable.

The 3D supports are attached to the enclosure with glue. I used Bison Kit. Tested beforehand if the glue would not make the 3D printed supports melt. So far the glue has been strong enough and the display supports have not loosened at all.

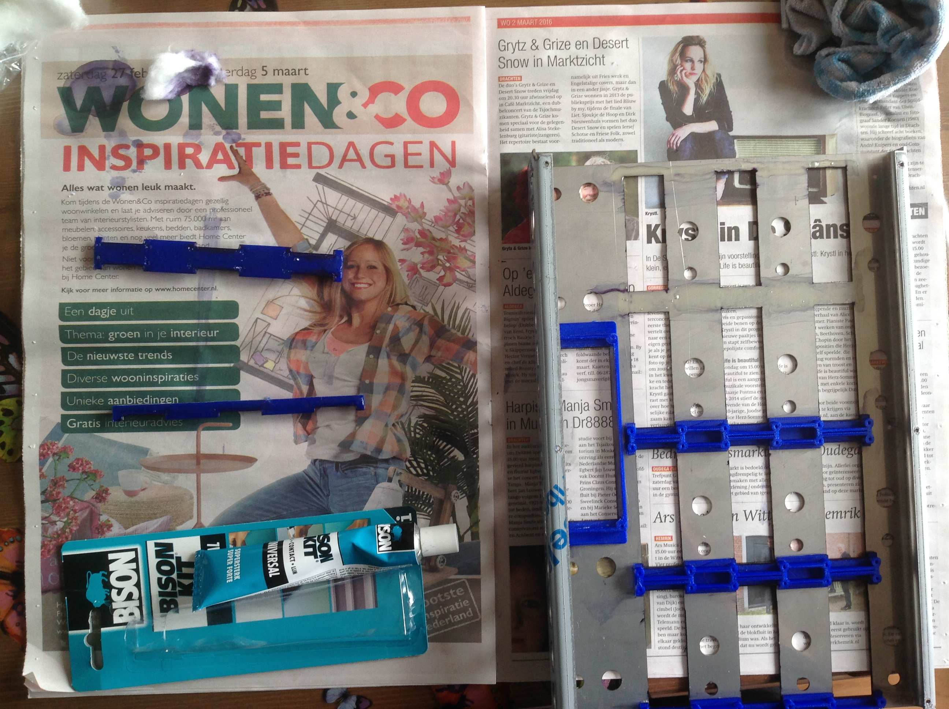
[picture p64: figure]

Check all the boards and displays fit before painting or wrapping the enclosure. I always have to do a little filing to get the displays to fit.

Check out the video: Gluing the enclosure

https://youtu.be/sExP2jf99Nc

Main display with i2C module

You will need a i2c module, which can be bought from ebay easily On most of these adapters you can set the i2c address (with A0, A1, A2 – see picture below)


Some of these adapters have the PCF8574T chip. These are in the 0x20-0x27 i2c address range. Others have the PCF8574AT chip. These are in the 0x38-0x3F address range.

It does not matter which type you have. You can change the address in the VController firmware (hardware.h). Set it to address 0x27 if you have the PCF8574T and to 0X3F if you have the PCF8574AT. The hardware test sketch will check for both addresses and show the correct address on the display!

Connecting the i2c adapter to the main display:

The large display has a different pinout from the i2c module. To fix this:
- Pull out pin 15 and 16 from i2C module. First cut the plastic.
- Connect two wires running from pin 1 and 2 on the display to pin 15 and 16 on the i2c interface (pin 1 to pin 15 and pin 2 to pin 16)
- Place the i2c module shifted two pins to the right. Pin 1 - 14 of the i2c module should be connected to pin 3 – 16 of the display.


Building the Main PCB

PCB manufacturing:
The schematic and design of the main PCB with Gerber files is here: https://github.com/sixeight7/VController_v3/tree/master/Main%20board

The gerber files can be send zipped to a PCB manufacturer. I found easyeda.com to be very cheap as long as you stick to their defaults: 1.6 mm, green, HASL, 1oz. Copper weight, 1 design per panel.

Dimensions: 215 x 60 mm
Layers: 2
Thickness: 1.6 mm
Hole count: 320 plated pads + 13 non plated pads + 12 vias = 335 total

Soldering:
I always solder starting with the parts with the least height. Then I work my way up to the parts with more height. Before soldering all the pins of the connectors, check if they fit the enclosure. I found everything fitted fine without any filing.


See additional documents for schematic and large PCB design..

The first version (REV. A) of the main PCB board had some errors:
- Power barrel pins were connected backwards
- 2N7000 were connected backwards. This will fry the Teensy as it puts 5V power on the 3.3V power line!
- The external jacks use pin 13 of the Teensy. This pin is not suitable. It has been moved to pin 28 (pad on the Teensy)
- Capacitor C9 was too large and is changed to 10 uF.
- When installing new firmware, the Teensy drops the power pin and the VController is switched off! To solve this, there is a modification with a resistor of 100 kOhm to keep the VController on during updates and a capacitor of 4,7 uF to keep the power pin low when the VController has to be switched off.
- I found I could raise the speed of the i2c bus. The MCP23017 chips and the 24LC512 EEPROM chip run at 1500 MHz, the PCF8574 chips on the expander run at 800 MHz. Raising the i2c speed drastically improves performance of the VController. To allow for maximum performance, I now use the second i2c bus of the Teensy for the main display at 800 MHz and run the primary i2C bus at 1500 MHz.
- Also the 6N138 optocouplers have been replaced by 6N137 optocouplers, as these perform much better according to internet sources.

These errors have been fixed in the REV. C version of the main board!

Power conversion

You may want to replace the 7805 with a buck convertor. I use these found on ebay:


I used a small knife to cut the trace next to the ADJ pad and added a blob of solder to connect the 5V. That way the voltage level is stable at around 4.95 Volts. I do not trust the small potmeter on the front. Touching it changes the voltage. The RPi and other attached USB devices may break when voltage exceeds 5.5 Volts.

The EN pin on the convertor is not connected. You probably could leave out Q1 (IRF9530 P-channel MOSFET) and connect its gate here, but I haven’t tested that yet.

Check out the video: Soldering the main board

https://youtu.be/yJqYoJ4opok

Building the display board

PCB manufacturing:
The schematic and design of the main PCB with Gerber files is here: https://github.com/sixeight7/VController_v3/tree/master/Display%20board

Dimensions: 165 x 69 mm
Layers: 2
Thickness: 1.6 mm
Hole count: 152 plated pads + 53 vias = 205 holes

Soldering:
These board are a little tricky. Components are soldered to both sides of the board. The displays and neopixel LEDs go to the bottom side of the board.

The biggest challenge is that the legs of the Neopixel LEDs are quite short. If you solder the display boards straight to the PCB the legs of the LEDS will just reach the board. But you can no longer reach the solderings below the displays.


Alternatively one could solder the LEDs to a 4 pin straight header. This will extend the legs and allow the display boards to be connected through 16 pin female headers. You also have to watch that the legs of the LED do not short in the LED bezel. Therefore I put a small piece of insulation around the LEDs. I found the insulation of an old CAT5 cable to be a perfect fit. It is large enough to fit around the legs of the LED and small enough to fit in the bezel. You can also use electrical tape to make the isolation.


Be careful to check if everything fits and is at the right height as you fit the board in the enclosure. It is best to add the LEDs to the display boards after everything is in put together in the enclosure.

The neopixel LEDs are connected in a large chain. Every data out is
connected to the next data in. The ground pin and “data out” pin are
longer than the other pins. Also on some LEDs there is a small indent in the “ring” at the bottom of the LED above the “data out” pin. On the board the “data in” pin should face to the bottom of the board:

Addressing of boards:

With the A0 – A2 jumpers next to the MCP23017 chip a unique address must be set for each board. I usually just hardwire the jumpers as wires to the board. The boards are addressed 0 to 3 from right to left, looking from behind the displays (VController opened up)

Address 3:
A0 O-O O
A1 O-O O
A2 O O-O
10

Address 2:
A0 O O-O
A1 O-O O
A2 O O-O
10

Address 1:
A0 O-O O
A1 O O-O
A2 O O-O
10

Address 0:
A0 O O-O
A1 O O-O
A2 O O-O
10

Check out the video: Soldering the display boards

https://youtu.be/4Qu6WvendfU

Testing:
You can find a link to a hardware test sketch in the firmware section below.

The test sketch does a number of tests during boot. For every stage of the test the build in LED of the Teensy will flash. Here is a description of what happens during every flash:

1st flash: power on
2nd flash: Neopixel LEDs are initialized and on
3rd flash: Neopixel backlights are initialized and on (when present)
4th flash: i2c bus 1 initialized
5th flash: i2c bus 2 initialized
6th flash: main LCD initialized
7th flash: 12 display LCDs initialized 8th flash: main LCD data test
9th flash: other display data test
10th flash: EEPROM data test

I usually test the boards by interconnecting them and then I run the test sketch. When the test is ready, you should see the following:


Check that all the displays are on and that the 24LC512 tests out OK.

During the build I tested the boards first with just the lowest display connected. This way I still had access to the chip and the connection pins. Once that display worked I added the next one.

Check out the video: Soldering and testing displays

https://youtu.be/hMdTI5rJZvg

Putting it all together

Once the enclosure is ready and all the boards have passed the test, it is time to put everything together.

First solder the 2 pin dupont wires to the switches. The 2 pin dupont wires are cut in half and used for two switches.

Attach the LED holders to the enclosure. Next add all the displays. Now add the perspex plate and the switches.


Three 8 pin dupont wires are used to interconnect the boards. One longer one is used to connect board 0 to the main board.

Also a four pin dupont wire is used to connect the main display i2C module to the main board.

Now is a good time to run the test sketch again. The main display should show which switch is pressed or released. So you can test all switches here.

Lastly add the LEDs to the display boards.

Now it is time to run the final check. During the test sequence all LEDs should light up white. By pressing the switches the colour of the corresponding LED should change colour.

It is quite easy to short the data pins of the LEDs via the bezel. Make sure you isolated everything carefully.

After the test sketch runs succesfully, you can upload the VController firmware and test all the MIDI ports and switch/expression pedal connections.

Check out the video: Putting it all together

https://youtu.be/iXB7WEzQCkI

Firmware
There are two ways to install firmware. One is to use a pre-compiled hex file. The other way is to compile the data yourself, using the Arduino IDE.

Loading precompiled hex files to the Arduino:

In https://github.com/sixeight7/VController_v3/tree/master/Firmware/Compiled you can download the hex files for the test sketch and the VController firmware itself. Right click on the hex file and select Save as…

To install the firmware on the VController you need the following tool: https://www.pjrc.com/teensy/loader.html

Follow the instructions on the PJRC website to install the tool for you operating system.

To install the firmware, take the following steps:

1. Connect the VController or just the Teensy to your computer using a USB cable
2. Press the small button on the Teensy. It is now ready to receive firmware.
3. Start the Teensy loader. You should see the following three buttons:
4. Press the first button to open the hex file.
5. Press the second button to upload it to the Teensy.
6. Press the third button to reboot the Teensy. This should reboot the VController with the hardware test sketch or the Vcontroller firmware.

Compile the Teensy sketches yourself:

You will need to install Arduino IDE with the additional Teensyduino add-on: https://www.arduino.cc/en/main/softwarehttps://www.pjrc.com/teensy/teensyduino.html

You will need the correct LiquidCrystal library, which can be found here: https://bitbucket.org/fmalpartida/new-liquidcrystal/downloads/LiquidCrystal_V1.2.1.zip

Test sketch for hardware: to test the displays, LEDs and switches: https://github.com/sixeight7/VController_v3/tree/master/Firmware/Hardware_test_VC_PM

Firmware can be downloaded and installed from github: https://github.com/sixeight7/VController_v3/tree/master/Firmware/VController_v3

Raspberry Pi option board:
A Raspberry Pi can be added to the VController to have an additional four USB host ports, supporting all the devices the VController supports so far. This board can be build either internal or external.

Raspberry Pi firmware:
The Raspberry Pi runs with special firmware called VCbridge. You can find the source code and installation instructions here:
https://github.com/sixeight7/VCbridge

You can also download a ready made image from here: https://www.dropbox.com/s/cgy4ypnyhkf0ucw/2017-10-24%20VCbridge.rar?dl=0

To install the ready made image:
1) Download and unrar the 2017-10-24 VCbridge.rar image.
2) Download Win32DiskImager from https://sourceforge.net/projects/win32diskimager/
3) Connect the microSD card to your PC.
4) Upload the image.

Internal Raspberry Pi board:
For the internal board we need a Raspberry Pi, a bracket and a four or five pin Dupont wire.


The design of the bracket is found here: https://github.com/sixeight7/VController_v3/tree/master/Enclosure/Metal

A four pin Dupont wire can be connected to pin 4 (5V) ,6 (GND) ,8 (UART0_TXD) and 10 (UART0_RXD) of the GPIO to the +5V, GND, RX3 and TX3 pin of the main board. See pinout GPIO below:


I have built my own Dupont connector with 5 pin connectors, so I would not connect it the wrong way.

External Raspberry Pi board:
For the external board we need a 3D printed enclosure and a PCB.

The design of the enclosure is found here: https://github.com/sixeight7/VController_v3/tree/master/Enclosure/RPi%20case

It consists of two parts. In total the enclosure requires 87 gram of PLA.

Building the PCB. You can find the gerbers here: https://github.com/sixeight7/VController_v3/tree/master/RPi%20Expansion%20Board

Here is the data you need to get the board made:
Dimensions: 89 x 57 mm
Layers: 2
Thickness: 1.6 mm
Hole count: 118 plated pads + 1 via = 119 total

The raspberry Pi board fits upside down on the Rpi board:


12 mm spacers go in between the boards. The two halves of the enclosure fit around the boards and are screwed tight in the spacers. Always start with the top side of the enclosure, add the PCB board and attach the spacers. Then add the Raspberry Pi and the bottom side of the enclosure.


Check out the video: Building the RPI expansion board

https://youtu.be/kFdNmJK0trg

Adding labels


For the back of the VController and for the top of the external Raspberry Pi there are some labels, which you can find here: https://github.com/sixeight7/VController_v3/blob/master/Enclosure/VController%20labels.pdf

I have printed them and laminated them with an adhesive laminating pouche. After laminating, I cut them and then laminated them again to seal the edges.

How much time does it cost to build a VController:

Ordering of parts | 2 hours
Having enclosure and 3D printing done | 1 hours
Building main board | 2 hours
Building display boards | 4 hours
Soldering i2c board to main display | 30 mins
Soldering wires to switches | 30 mins
Soldering pin headers to displays | 30 mins
Preparing LEDs | 30 mins
Gluing display holders to enclosure | 30 mins
Putting plastic on enclosure | 2 hours
Putting it all together | 3 hours
Building Rpi board | 1 hour
Testing and debugging | 2 hours
Total time: | 20 hours

Additional information:
Check out my blog at vguitarforums.com: http://www.vguitarforums.com/smf/index.php?topic=15154.0

I have spent countless hours since May 2015 developing the VController. I would really appreciate a small donation:
https://www.paypal.me/sixeight

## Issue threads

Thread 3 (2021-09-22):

You might be interested in some ZDL decoding?

shooking, 2021-09-22:
Hallo @sixeight7

Firstly great stuff you have done here and round the internet.
I am posting my stuff, based also on Mungewell's zoom-zt, on my site https://github.com/shooking/ZoomPedalFun
Currently my ZDL research is under the B1ON/DerivedData/DecodeFirmware

Recently I got a G5 - your G3 work really helped there AND that at least makes it easy to set and FX at a slot.
But I didnt see how to inject ZDL, so I got an MS-70 CDR (hence why I am lurking in your code).
The midi seems to be "hidden" on this (mostly).

As you know Mungewell pretty much has the newer "n" series nailed. I have extended this to the GCE-3.
The older series share _some_ similarity but with restricted sysex.

### ZDL Format
So far I am working on extracting as much info from a firmware to get the ZDLs.
And from the ZDLs to get info into JSON for use in basic GUIs for my Pi touchscreen.

MS-70CDR has some concept of the FLST_SEQ.ZDT.
But unlike the Zoom B1XFour say it doesnt encode the Zoom Type in it.
However, I did find it gives us the FX Group and I also discovered how to get the FXID.
Ordinarily I would then inject these into a modern Zoom pedal via
```
probeString="F0 52 00 6E 64 03 00 ${hexSlot} ${OnOff} ${hexFXValueLow} ${hexFXValueHigh} 00 ${hexGroupVal} 00 F7"
```

As you already know the CDR is 61 rather than 6E and uses 31 as its command. Alas I do not seem able to work out the Group extension.

That is
```
probeString="F0 52 00 65 31 ${hexFX} 01 ${hexFXValueLow} ${hexFXValueHigh}  F7"
```
on a B1On sets the 1st two bytes of an FX ID to 2xhexFXValueLow + 1, hexFXValueHigh
But no idea how to set the group.

I noticed you have ID concept as
```
const PROGMEM ZMS70_FX_type_struct ZMS70_FX_types[] = { // Table with the name and colour for every effect of the Zoom MS70-CDR
  {0, 0,    "---", FX_TYPE_OFF}, // 01
  {12, 195, "CoronaCho", FX_MODULATE_TYPE}, // 02
  {12, 224, "Chorus", FX_MODULATE_TYPE}, // 03
  {12, 33,  "VintageCE", FX_MODULATE_TYPE}, // 04
  {12, 227, "ANA 234Cho", FX_MODULATE_TYPE}, // 05
  {12, 3,   "CE-Cho5", FX_MODULATE_TYPE}, // 06
  {12, 35,  "Clone Chorus", FX_MODULATE_TYPE}, // 07
  {12, 161, "Super Cho", FX_MODULATE_TYPE}, // 08
  {12, 163, "Mirage Chorus", FX_MODULATE_TYPE}, // 09
  {12, 65,  "Stereo Cho", FX_MODULATE_TYPE}, // 10
  {12, 4,   "Corona Tri", FX_MODULATE_TYPE}, // 11
  {12, 97,  "Ensemble", FX_MODULATE_TYPE}, // 12
  {12, 131, "Silky Chorus", FX_MODULATE_TYPE}, // 13
...
```

I will be updating my git soon - I should have read Barsik's notes on the file format more closely. You only get 4090 bytes max in a block and have to account for the 6 format bytes.
Anyhow when I extract the FX from the 2.1 firmware and compare with the FLST I make Corona Cho as follows:

```
F:\Interests\Guitars\MS70-CDR\pants>more CoronaCho.json
{
    "fxname": "CoronaCho",
    "fxid": "0x1e0",
    "gid": "0x6",
    "version": "1.00",
    "Parameters": [
        {
            "name": "SPEED",
            "mmax": 100,
            "mdefault": 50,
            "pedal": false
        },
        {
            "name": "DEPTH",
            "mmax": 100,
            "mdefault": 50,
            "pedal": false
        },
        {
            "name": "FxLVL",
            "mmax": 100,
            "mdefault": 65,
            "pedal": false
        },
        {
            "name": "TONE",
            "mmax": 100,
            "mdefault": 75,
            "pedal": false
        },
        {
            "name": "DRY",
            "mmax": 1,
            "mdefault": 1,
            "pedal": true
        }
    ]
}
```

So I figure the group is 6 and ID 0x1e0.
Why|?

```
<<<00 02 00 00 00 00 00 00 00 00>>>00 06 00 00 00 00 00 00 00 00CRN_CHO.ZDL00 00CHORUS.ZDL00 0000VTGCE.ZDL00 0000 00ANA234CH.ZDL0CE_CHO5.ZDL00 00...
```
The number inside <<<n>>> is the _previous_ folder id.
The number after is the current. So for sure these FX are 6.

To confirm IF you start a ZDL with 00 00 00 00
then offset 0x40 onwards gives the type (FXID/GID) combo

```
$ hexdump -C CoronaCho.ZDL
00000000  00 00 00 00 53 49 5a 45  08 00 00 00 38 00 00 00  |....SIZE....8...|
00000010  82 49 00 00 49 4e 46 4f  30 00 00 00 5a 4f 4f 4d  |.I..INFO0...ZOOM|
00000020  20 45 46 46 45 43 54 20  44 4c 4c 20 53 59 53 54  | EFFECT DLL SYST|
00000030  45 4d 20 56 45 52 20 31  2e 30 30 00 06 00 00 00  |EM VER 1.00.....|
00000040  e0 01 00 06 31 2e 30 30  00 00 00 00 7f 45 4c 46  |....1.00.....ELF|
```

Ideally I would love to work out the sysex, like on a B1XFour, to set the FXID/GID but on B1ON and MS-70 CDR.

I was interested in whether your IDs can be injected via sysex or if this is your own numbering.

From what I can see from the firmware direct
```
0035d246: 0000 3c3c 3c00 0000 0000 0000 0000 003e 3e3e 0001 0000 0000 0000  ..<<<0>>>1
0035d260: 0000 434f 4d50 2e5a 444c 0000 0000 0052 4143 4b43 4f4d 502e 5a44  ..COMP.ZDL.....RACKCOMP.ZD
0035d27a: 4c00 4d5f 434f 4d50 2e5a 444c 0000 004f 5054 434f 4d50 2e5a 444c  L.M_COMP.ZDL...OPTCOMP.ZDL
0035d294: 0000 3136 305f 434f 4d50 2e5a 444c 004c 494d 4954 4552 2e5a 444c  ..160_COMP.ZDL.LIMITER.ZDL
0035d2ae: 0000 534c 5741 544b 2e5a 444c 0000 005a 4e52 2e5a 444c 0000 0000  ..SLWATK.ZDL...ZNR.ZDL....
0035d2c8: 0000 4e4f 4953 4547 5445 2e5a 444c 0044 4952 5459 4754 452e 5a44  ..NOISEGTE.ZDL.DIRTYGTE.ZD
0035d2e2: 4c00 4f52 414e 4745 4c4d 2e5a 444c 0047 5241 5943 4f4d 502e 5a44  L.ORANGELM.ZDL.GRAYCOMP.ZD
0035d2fc: 4c00 4455 414c 5f43 4d50 2e5a 444c 003c 3c3c 0001 0000 0000 0000  L.DUAL_CMP.ZDL.<<<1
0035d316: 0000 3e3e 3e00 0200 0000 0000 0000 004c 494e 4553 454c 2e5a 444c  >>>2 LINESEL.ZDL
0035d330: 0000 4745 512e 5a44 4c00 0000 0000 0042 5f47 4551 2e5a 444c 0000  ..GEQ.ZDL......B_GEQ.ZDL..
0035d34a: 0000 5045 512e 5a44 4c00 0000 0000 0042 5f50 4551 2e5a 444c 0000  ..PEQ.ZDL......B_PEQ.ZDL..
0035d364: 0000 5350 4c49 5454 4552 2e5a 444c 0042 4f54 544f 4d5f 422e 5a44  ..SPLITTER.ZDL.BOTTOM_B.ZD
0035d37e: 4c00 4558 4349 5445 522e 5a44 4c00 0043 4f4d 4246 4c54 522e 5a44  L.EXCITER.ZDL..COMBFLTR.ZD
0035d398: 4c00 4155 544f 5741 482e 5a44 4c00 0042 5f41 5457 4148 2e5a 444c  L.AUTOWAH.ZDL..B_ATWAH.ZDL
0035d3b2: 0000 5245 534f 4e53 2e5a 444c 0000 0043 5259 2e5a 444c 0000 0000  ..RESONS.ZDL...CRY.ZDL....
0035d3cc: 0000 534c 4f57 464c 5452 2e5a 444c 005a 5f54 524f 4e2e 5a44 4c00  ..SLOWFLTR.ZDL.Z_TRON.ZDL.
0035d3e6: 0000 4d5f 4649 4c54 4552 2e5a 444c 0041 5f46 494c 5445 522e 5a44  ..M_FILTER.ZDL.A_FILTER.ZD
0035d400: 4c00 425f 4352 592e 5a44 4c00 0000 0053 5445 502e 5a44 4c00 0000  L.B_CRY.ZDL....STEP.ZDL...
0035d41a: 0000 5345 5146 4c54 522e 5a44 4c00 0052 4e44 4d46 4c54 522e 5a44  ..SEQFLTR.ZDL..RNDMFLTR.ZD
0035d434: 4c00 4643 5943 4c45 2e5a 444c 0000 0053 545f 475f 4745 512e 5a44  L.FCYCLE.ZDL...ST_G_GEQ.ZD
0035d44e: 4c00 5354 5f42 5f47 4551 2e5a 444c 003c 3c3c 0002 0000 0000 0000  L.ST_B_GEQ.ZDL.<<<2
0035d468: 0000 3e3e 3e00 0600 0000 0000 0000 0054 5245 4d4f 4c4f 2e5a 444c  ..>>>6 TREMOLO.ZDL
0035d482: 0000 4455 4f54 5245 4d2e 5a44 4c00 0053 4c49 4345 522e 5a44 4c00  ..DUOTREM.ZDL..SLICER.ZDL.
0035d49c: 0000 5048 4153 4552 2e5a 444c 0000 0044 554f 5048 4153 452e 5a44  ..PHASER.ZDL...DUOPHASE.ZD
0035d4b6: 4c00 5752 5050 4841 5345 2e5a 444c 0054 4845 5649 4245 2e5a 444c  L.WRPPHASE.ZDL.THEVIBE.ZDL
0035d4d0: 0000 4348 4f52 5553 2e5a 444c 0000 0042 5f43 484f 5255 532e 5a44  ..CHORUS.ZDL...B_CHORUS.ZD
0035d4ea: 4c00 4445 5455 4e45 2e5a 444c 0000 0042 5f44 4554 554e 452e 5a44  L.DETUNE.ZDL...B_DETUNE.ZD
0035d504: 4c00 5654 4743 452e 5a44 4c00 0000 0053 5443 484f 2e5a 444c 0000  L.VTGCE.ZDL....STCHO.ZDL..
0035d51e: 0000 454e 5345 4d42 4c45 2e5a 444c 0042 5f45 4e53 4d42 4c2e 5a44  ..ENSEMBLE.ZDL.B_ENSMBL.ZD
0035d538: 4c00 5355 5045 5243 484f 2e5a 444c 0056 494e 464c 4e47 522e 5a44  L.SUPERCHO.ZDL.VINFLNGR.ZD
0035d552: 4c00 464c 414e 4745 522e 5a44 4c00 0042 5f46 4c4e 4752 2e5a 444c  L.FLANGER.ZDL..B_FLNGR.ZDL
0035d56c: 0000 4459 4e46 4c4e 4752 2e5a 444c 0056 4942 5241 544f 2e5a 444c  ..DYNFLNGR.ZDL.VIBRATO.ZDL
0035d586: 0000 4f43 5441 5645 2e5a 444c 0000 0042 5f4f 4354 4156 452e 5a44  ..OCTAVE.ZDL...B_OCTAVE.ZD
0035d5a0: 4c00 5054 4348 5348 4654 2e5a 444c 004d 4e50 4954 2e5a 444c 0000  L.PTCHSHFT.ZDL.MNPIT.ZDL..
0035d5ba: 0000 425f 5049 5443 482e 5a44 4c00 0048 5053 2e5a 444c 0000 0000  ..B_PITCH.ZDL..HPS.ZDL....
0035d5d4: 0000 4245 4e44 4348 4f2e 5a44 4c00 004d 4a52 4f4c 4c45 2e5a 444c  ..BENDCHO.ZDL..MJROLLE.ZDL
0035d5ee: 0000 5249 4e47 4d4f 442e 5a44 4c00 0043 455f 4348 4f35 2e5a 444c  ..RINGMOD.ZDL..CE_CHO5.ZDL
0035d608: 0000 434c 4f4e 4543 484f 2e5a 444c 0053 544f 4e45 5048 412e 5a44  ..CLONECHO.ZDL.STONEPHA.ZD
0035d622: 4c00 4246 5f46 4c47 5f32 2e5a 444c 0053 494c 4b59 4348 4f2e 5a44  L.BF_FLG_2.ZDL.SILKYCHO.ZD
0035d63c: 4c00 4d49 5241 4745 4348 2e5a 444c 0043 524e 5f43 484f 2e5a 444c  L.MIRAGECH.ZDL.CRN_CHO.ZDL
0035d656: 0000 414e 4132 3334 4348 2e5a 444c 0043 524e 5f54 5249 2e5a 444c  ..ANA234CH.ZDL.CRN_TRI.ZDL
0035d670: 0000 3c3c 3c00 0600 0000 0000 0000 003e 3e3e 0007 0000 0000 0000  ..<<< 6 >>>7
0035d68a: 0000 4249 5443 5255 5348 2e5a 444c 0042 4f4d 4245 522e 5a44 4c00  ..BITCRUSH.ZDL.BOMBER.ZDL.
0035d6a4: 0000 4d4f 4e4f 5359 4e2e 5a44 4c00 005a 5f4f 5247 414e 2e5a 444c  ..MONOSYN.ZDL..Z_ORGAN.ZDL
0035d6be: 0000 4155 544f 5041 4e2e 5a44 4c00 0052 5443 4c4f 5345 542e 5a44  ..AUTOPAN.ZDL..RTCLOSET.ZD
0035d6d8: 4c00 3c3c 3c00 0700 0000 0000 0000 003e 3e3e 0008 0000 0000 0000  L.<<< 7>>>8
0035d6f2: 0000 4445 4c41 592e 5a44 4c00 0000 0054 4150 4545 4348 4f2e 5a44  ..DELAY.ZDL....TAPEECHO.ZD
0035d70c: 4c00 4d4f 4444 4c59 2e5a 444c 0000 004d 4f44 444c 5932 2e5a 444c  L.MODDLY.ZDL...MODDLY2.ZDL
0035d726: 0000 414e 4c47 444c 592e 5a44 4c00 0052 5652 5344 4c59 2e5a 444c  ..ANLGDLY.ZDL..RVRSDLY.ZDL
0035d740: 0000 4d4c 5454 5044 4c59 2e5a 444c 0044 594e 4144 4c59 2e5a 444c  ..MLTTPDLY.ZDL.DYNADLY.ZDL
0035d75a: 0000 464c 5452 444c 592e 5a44 4c00 0050 4954 4348 444c 592e 5a44  ..FLTRDLY.ZDL..PITCHDLY.ZD
0035d774: 4c00 5354 4445 4c41 592e 5a44 4c00 0050 4841 5345 444c 592e 5a44  L.STDELAY.ZDL..PHASEDLY.ZD
0035d78e: 4c00 5447 484c 4444 4c59 2e5a 444c 0053 544f 4d50 444c 592e 5a44  L.TGHLDDLY.ZDL.STOMPDLY.ZD
0035d7a8: 4c00 5441 5045 4543 4833 2e5a 444c 0044 5541 4c44 4947 442e 5a44  L.TAPEECH3.ZDL.DUALDIGD.ZD
0035d7c2: 4c00 4352 424e 444c 592e 5a44 4c00 0044 5256 5f45 4348 4f2e 5a44  L.CRBNDLY.ZDL..DRV_ECHO.ZD
0035d7dc: 4c00 534c 4150 424b 442e 5a44 4c00 0053 4d53 5f44 4c59 2e5a 444c  L.SLAPBKD.ZDL..SMS_DLY.ZDL
0035d7f6: 0000 4c4f 4649 444c 592e 5a44 4c00 0053 4c57 4154 4b44 4c2e 5a44  ..LOFIDLY.ZDL..SLWATKDL.ZD
0035d810: 4c00 5452 454d 444c 592e 5a44 4c00 0046 4c54 4552 5050 442e 5a44  L.TREMDLY.ZDL..FLTERPPD.ZD
0035d82a: 4c00 4150 414e 444c 592e 5a44 4c00 0049 4345 444c 592e 5a44 4c00  L.APANDLY.ZDL..ICEDLY.ZDL.
0035d844: 0000 3c3c 3c00 0800 0000 0000 0000 003e 3e3e 0009 0000 0000 0000  ..<<<. 8>>>9
0035d85e: 0000 4844 4841 4c4c 2e5a 444c 0000 0048 445f 5245 562e 5a44 4c00  ..HDHALL.ZDL...HD_REV.ZDL.
0035d878: 0000 4841 4c4c 2e5a 444c 0000 0000 0052 4f4f 4d2e 5a44 4c00 0000  ..HALL.ZDL.....ROOM.ZDL...
0035d892: 0000 544c 4452 4f4f 4d2e 5a44 4c00 0053 5052 494e 472e 5a44 4c00  ..TLDROOM.ZDL..SPRING.ZDL.
0035d8ac: 0000 4152 454e 412e 5a44 4c00 0000 0045 4152 4c59 5245 462e 5a44  ..ARENA.ZDL....EARLYREF.ZD
0035d8c6: 4c00 4149 522e 5a44 4c00 0000 0000 0050 4c41 5445 2e5a 444c 0000  L.AIR.ZDL......PLATE.ZDL..
0035d8e0: 0000 4d4f 4452 4556 2e5a 444c 0000 0053 4c41 5042 4143 4b2e 5a44  ..MODREV.ZDL...SLAPBACK.ZD
0035d8fa: 4c00 5350 5249 4e47 3633 2e5a 444c 0043 4841 4d42 4552 2e5a 444c  L.SPRING63.ZDL.CHAMBER.ZDL
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
sixeight7, 2021-09-23:
Hi shooking,

For my project I only need to read the effect types. I do not set them. All that I found out is in the pdf’s I have provided. The values in my table are just values that made sense in some way. It is the result of reverse engineering. I stopped when I reached my goal, which is reading every effect type successfully.

Kind regards,
Catrinus

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

Closed 2022-12-05.

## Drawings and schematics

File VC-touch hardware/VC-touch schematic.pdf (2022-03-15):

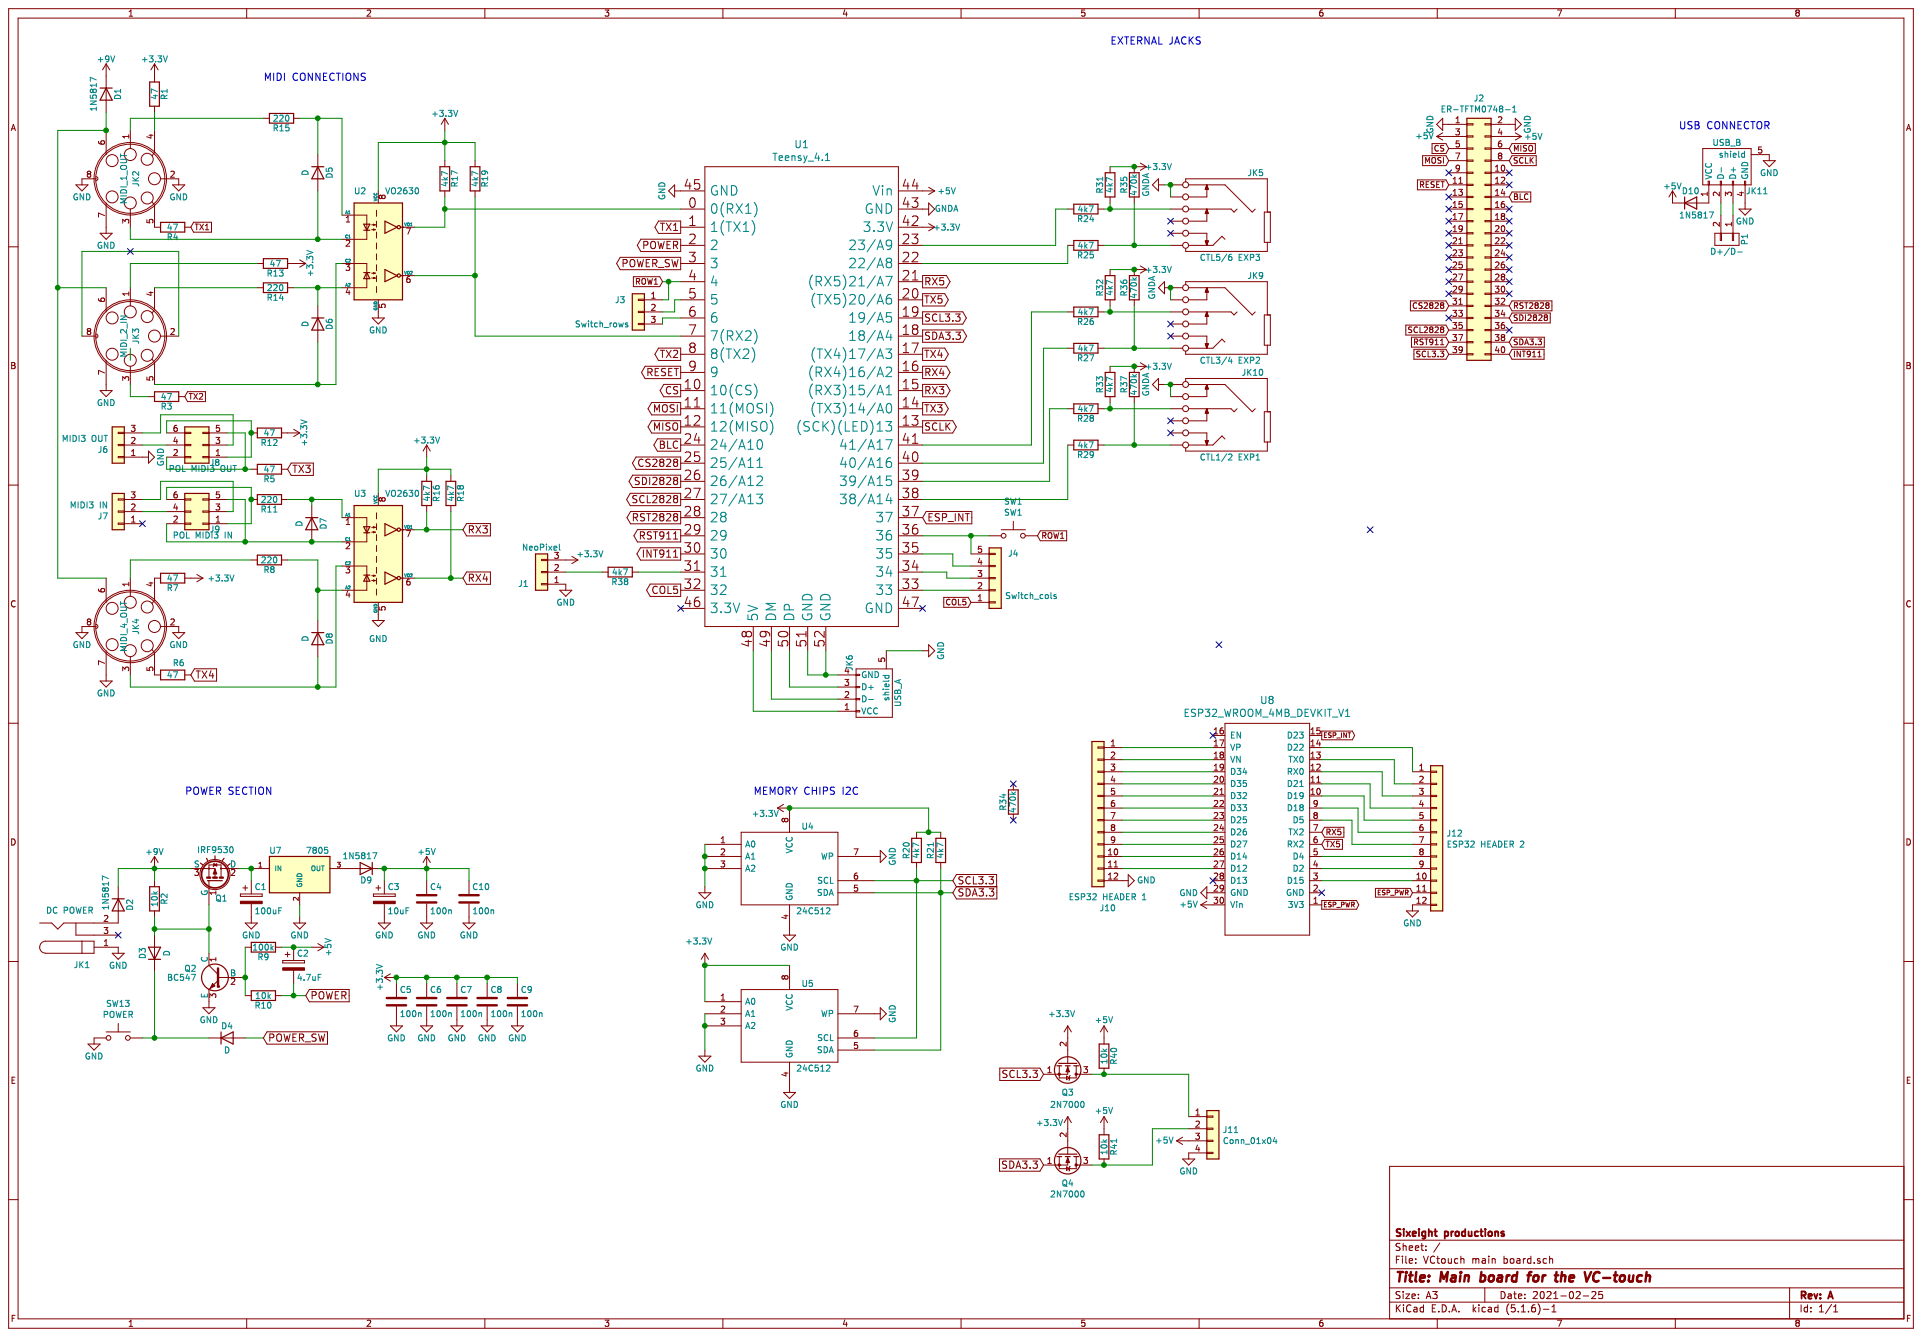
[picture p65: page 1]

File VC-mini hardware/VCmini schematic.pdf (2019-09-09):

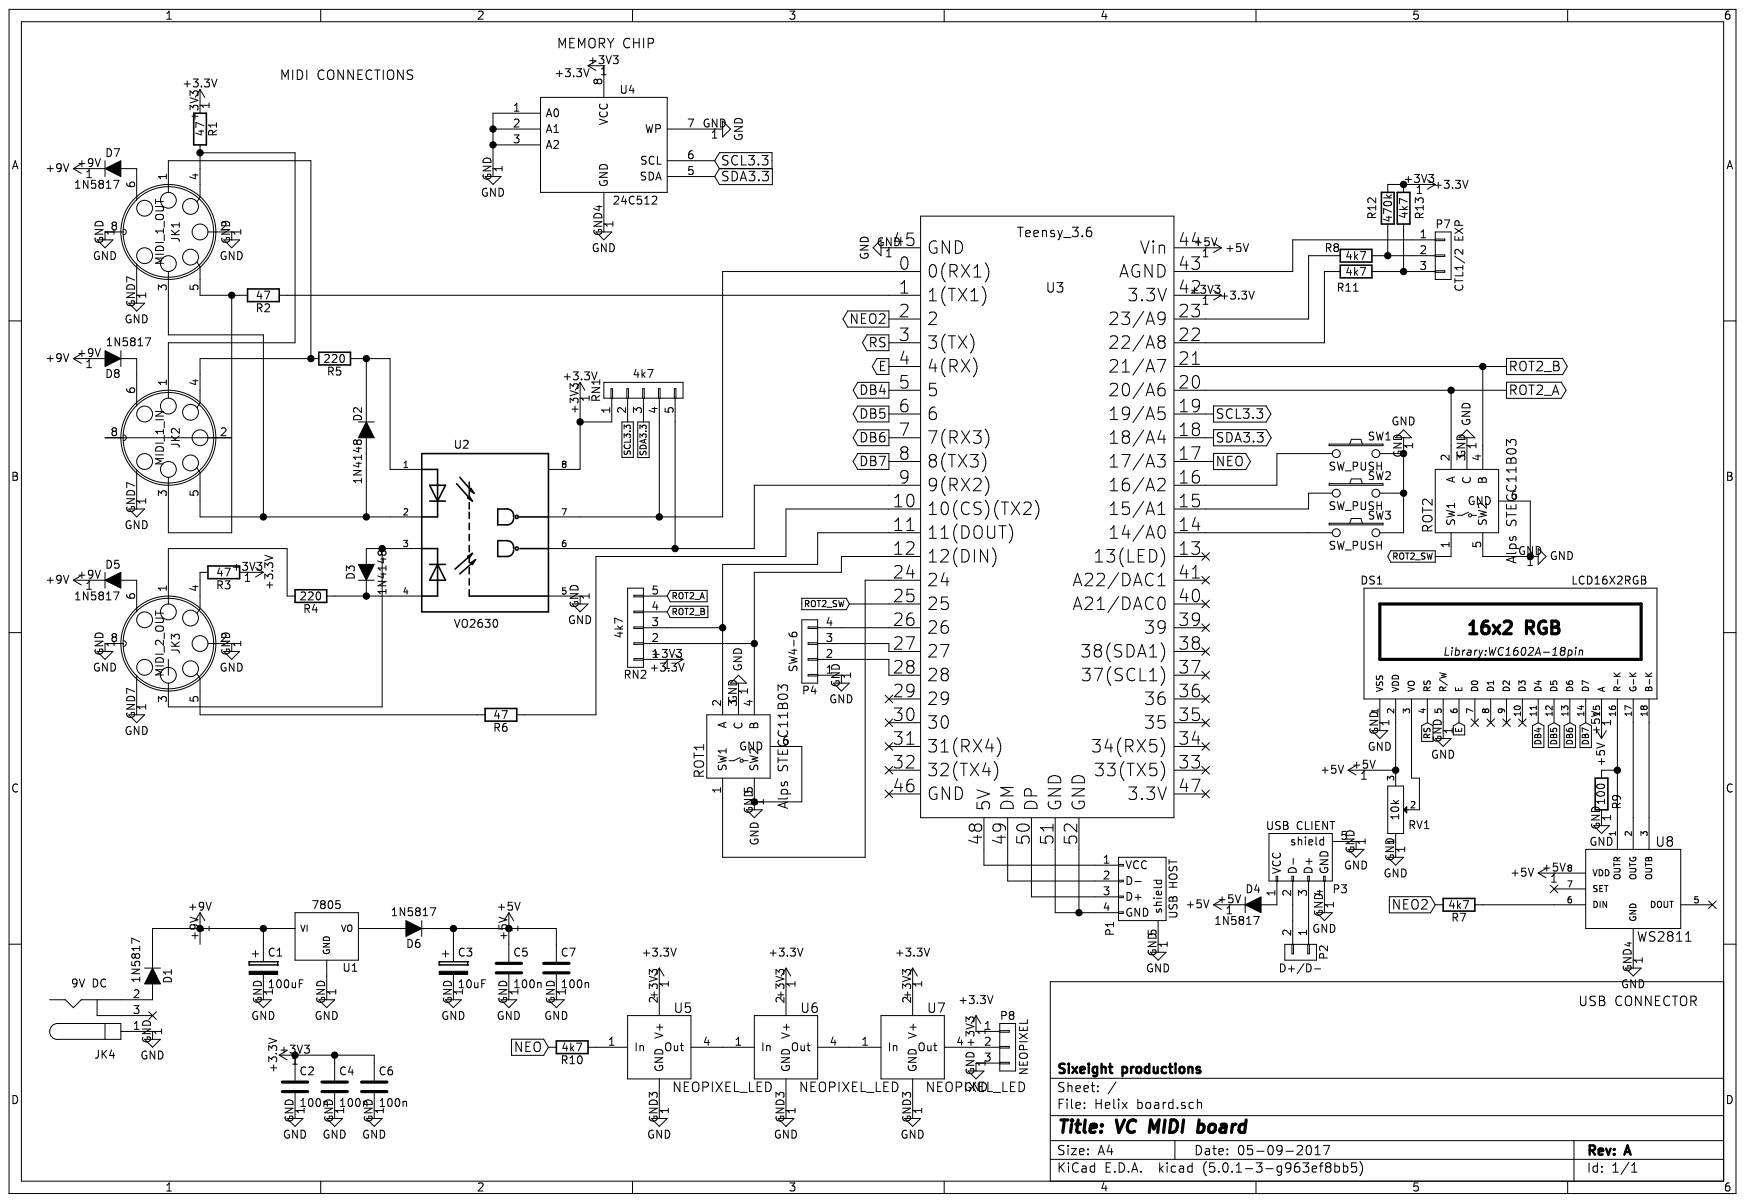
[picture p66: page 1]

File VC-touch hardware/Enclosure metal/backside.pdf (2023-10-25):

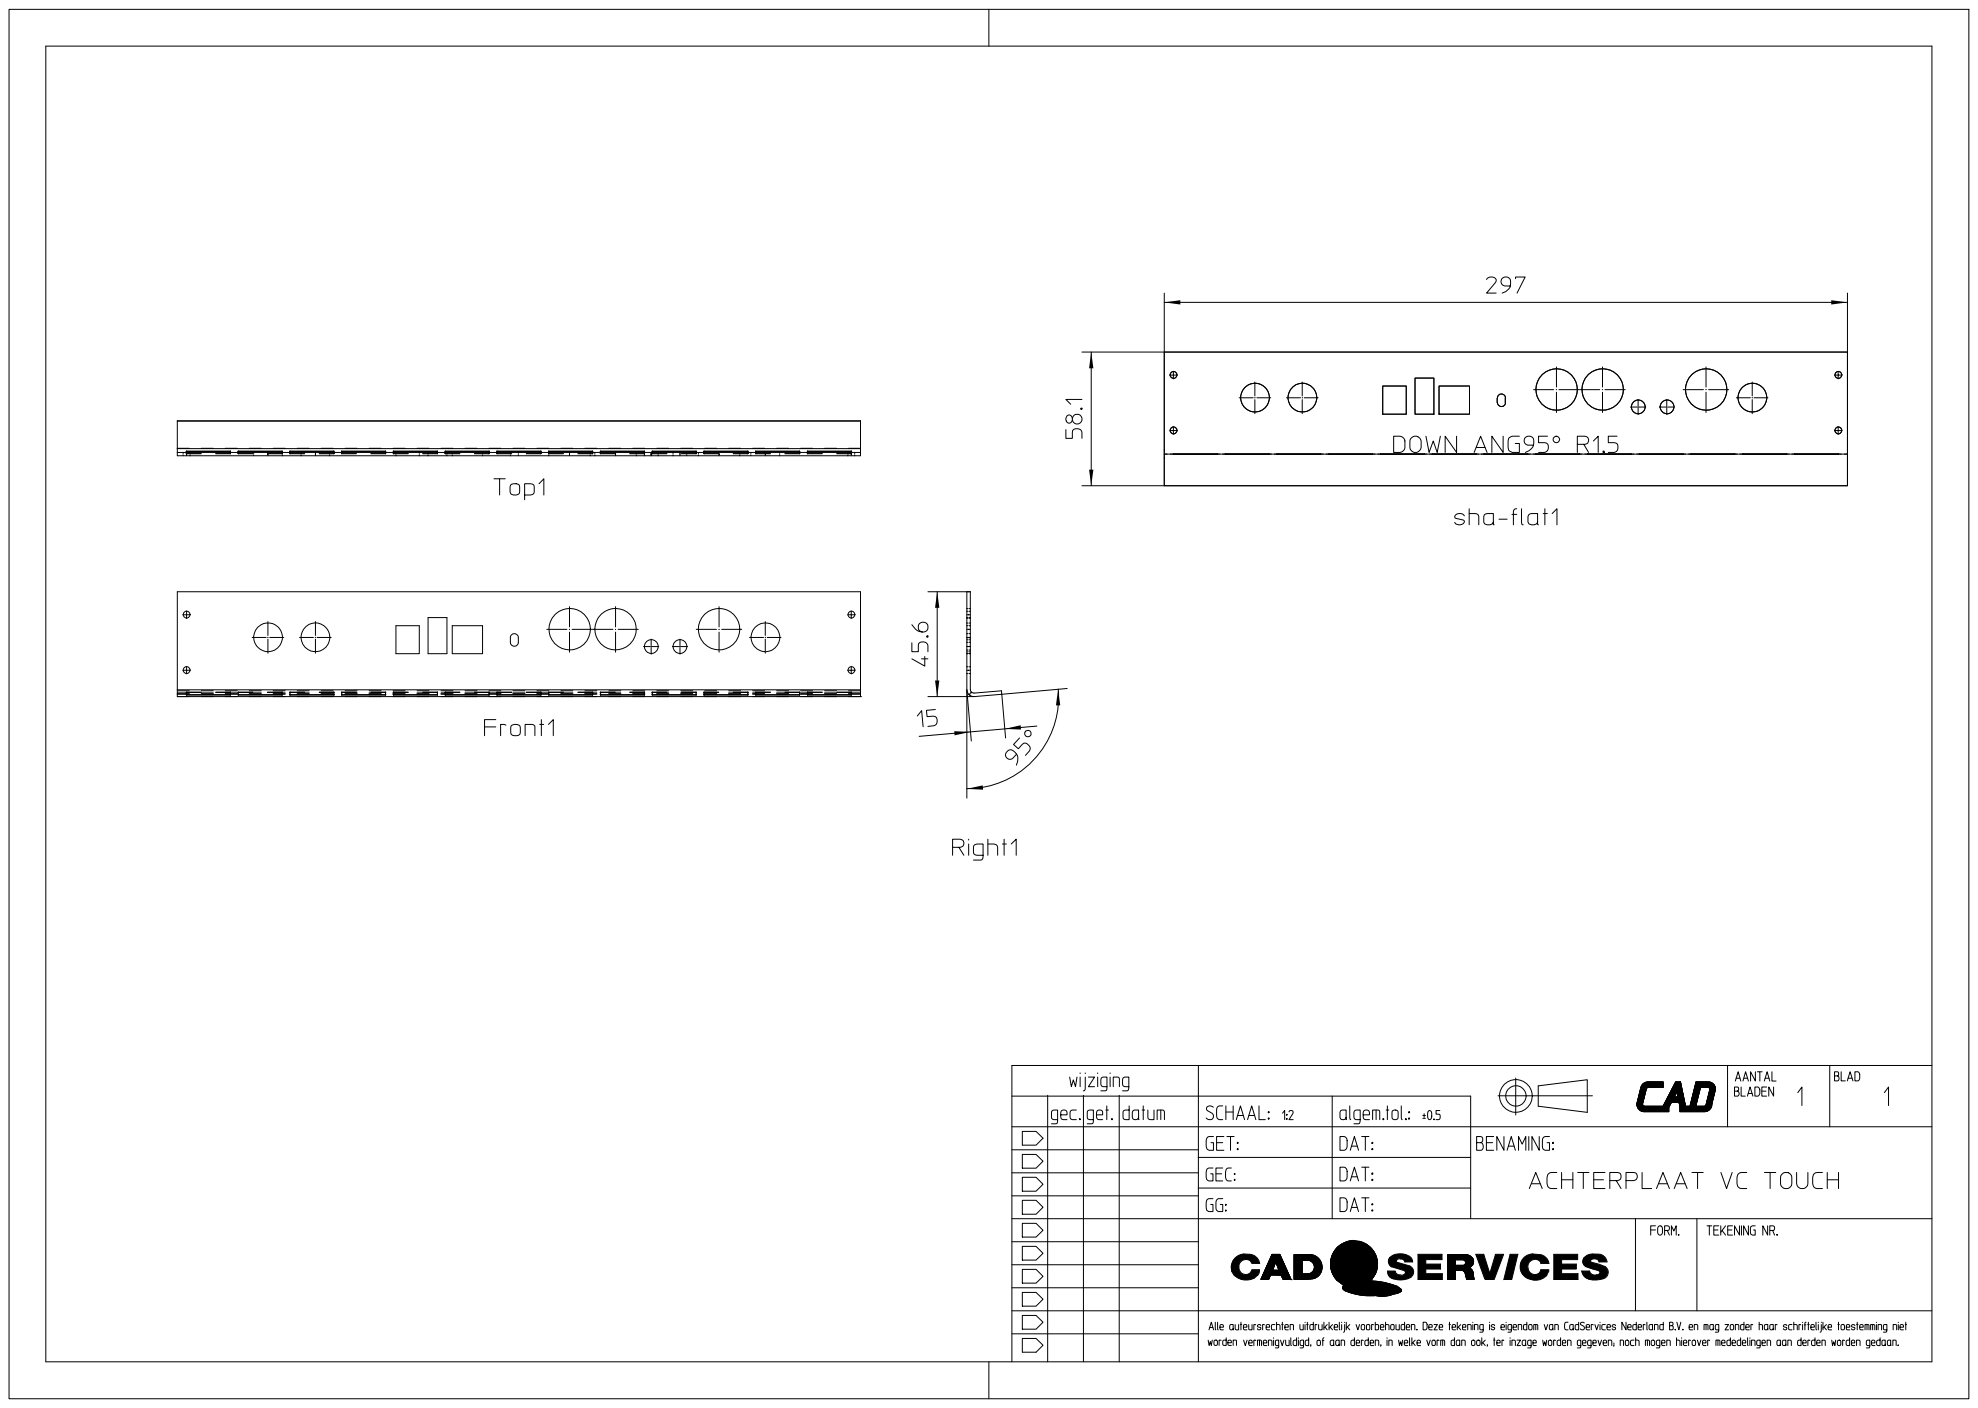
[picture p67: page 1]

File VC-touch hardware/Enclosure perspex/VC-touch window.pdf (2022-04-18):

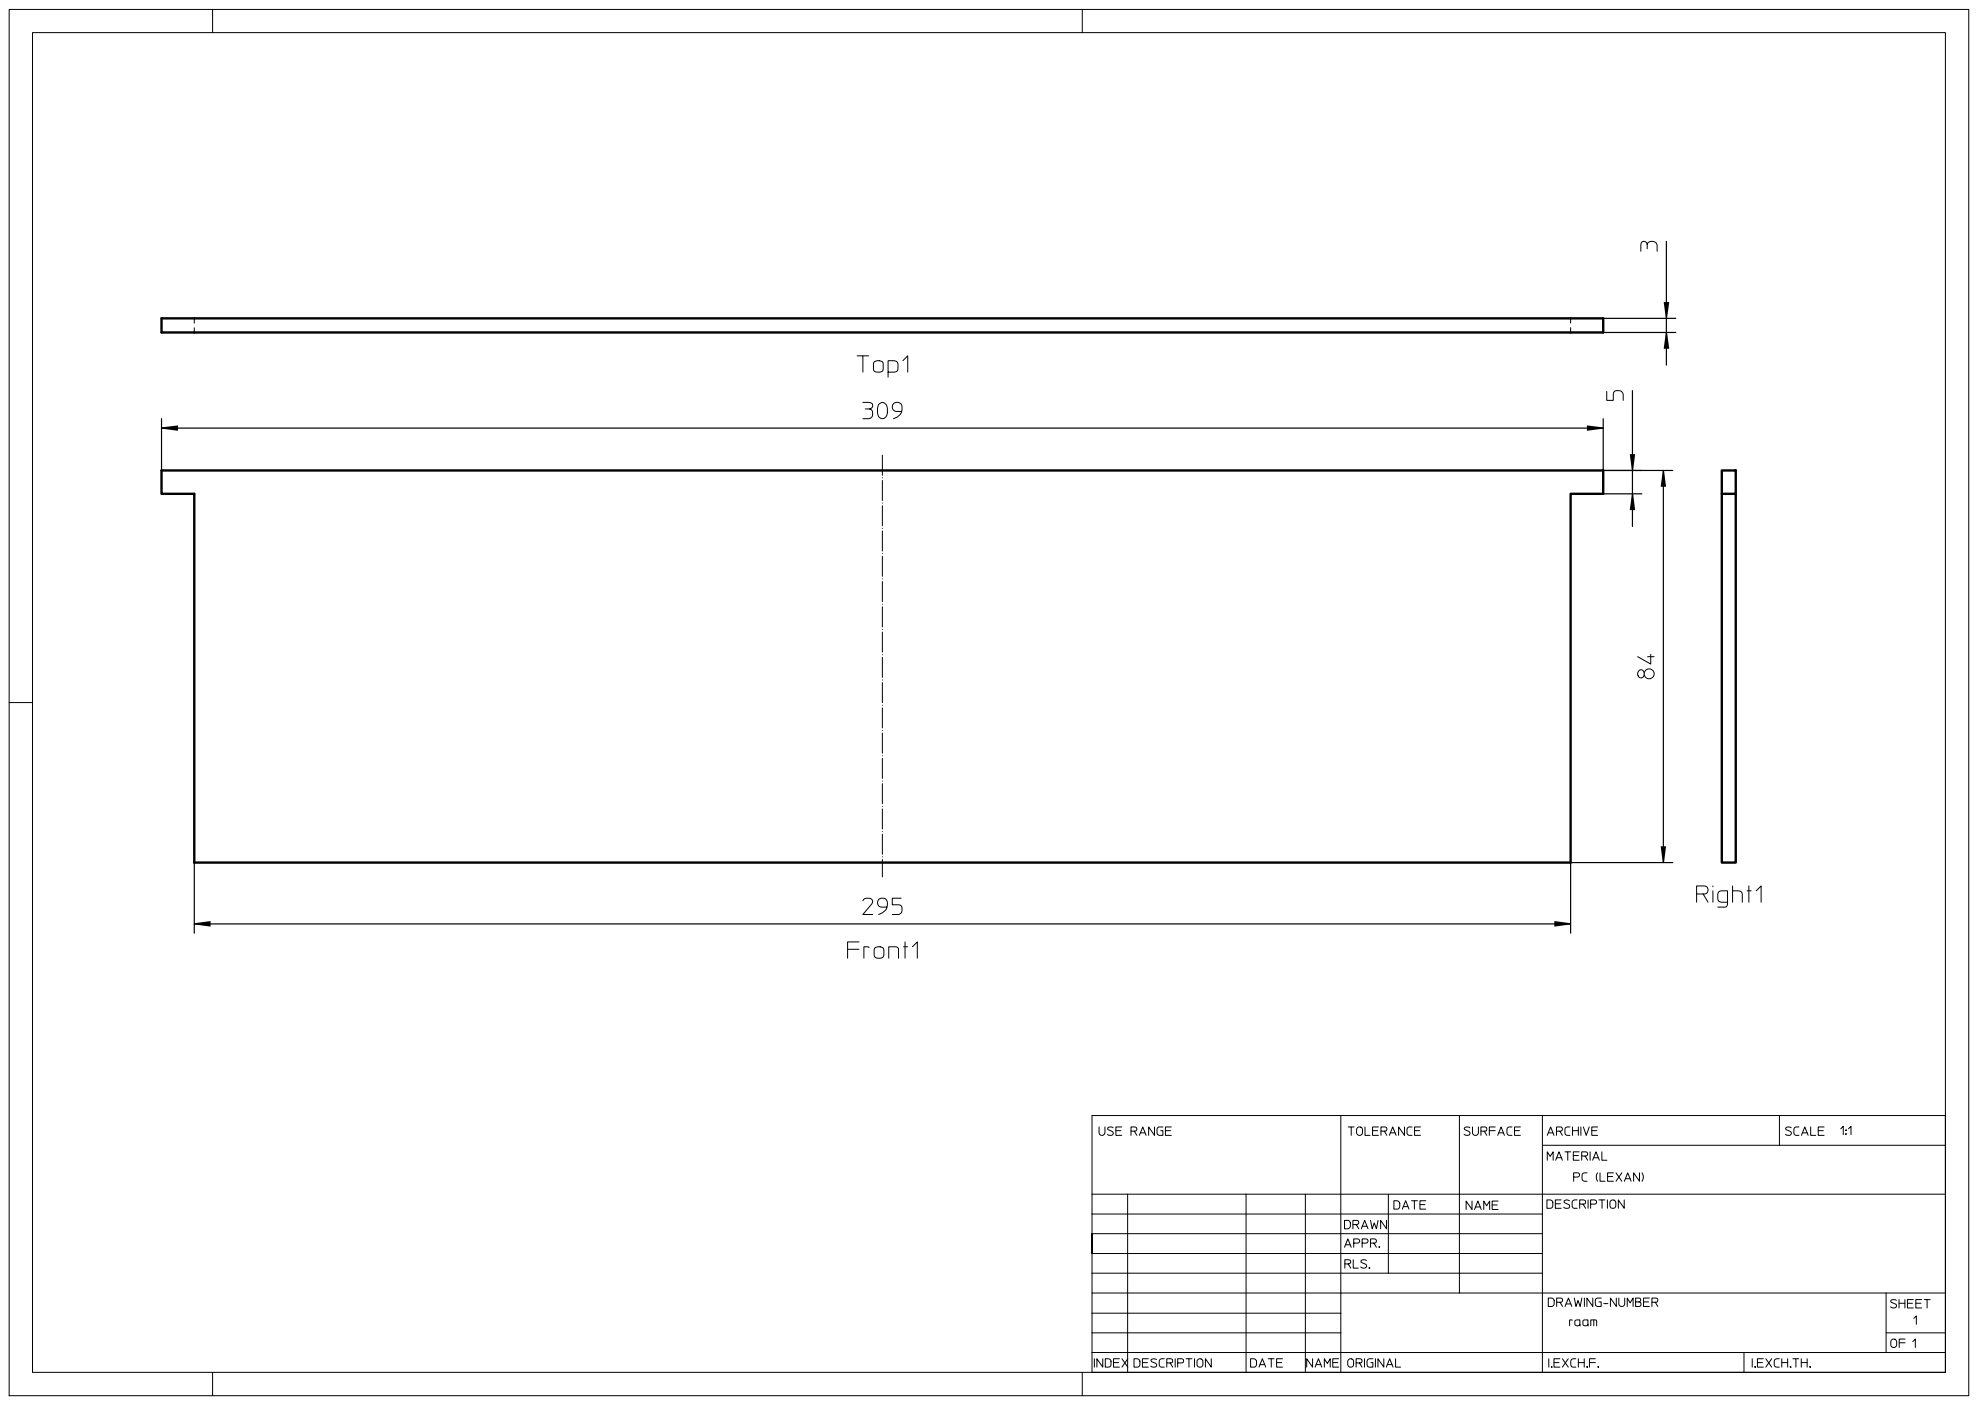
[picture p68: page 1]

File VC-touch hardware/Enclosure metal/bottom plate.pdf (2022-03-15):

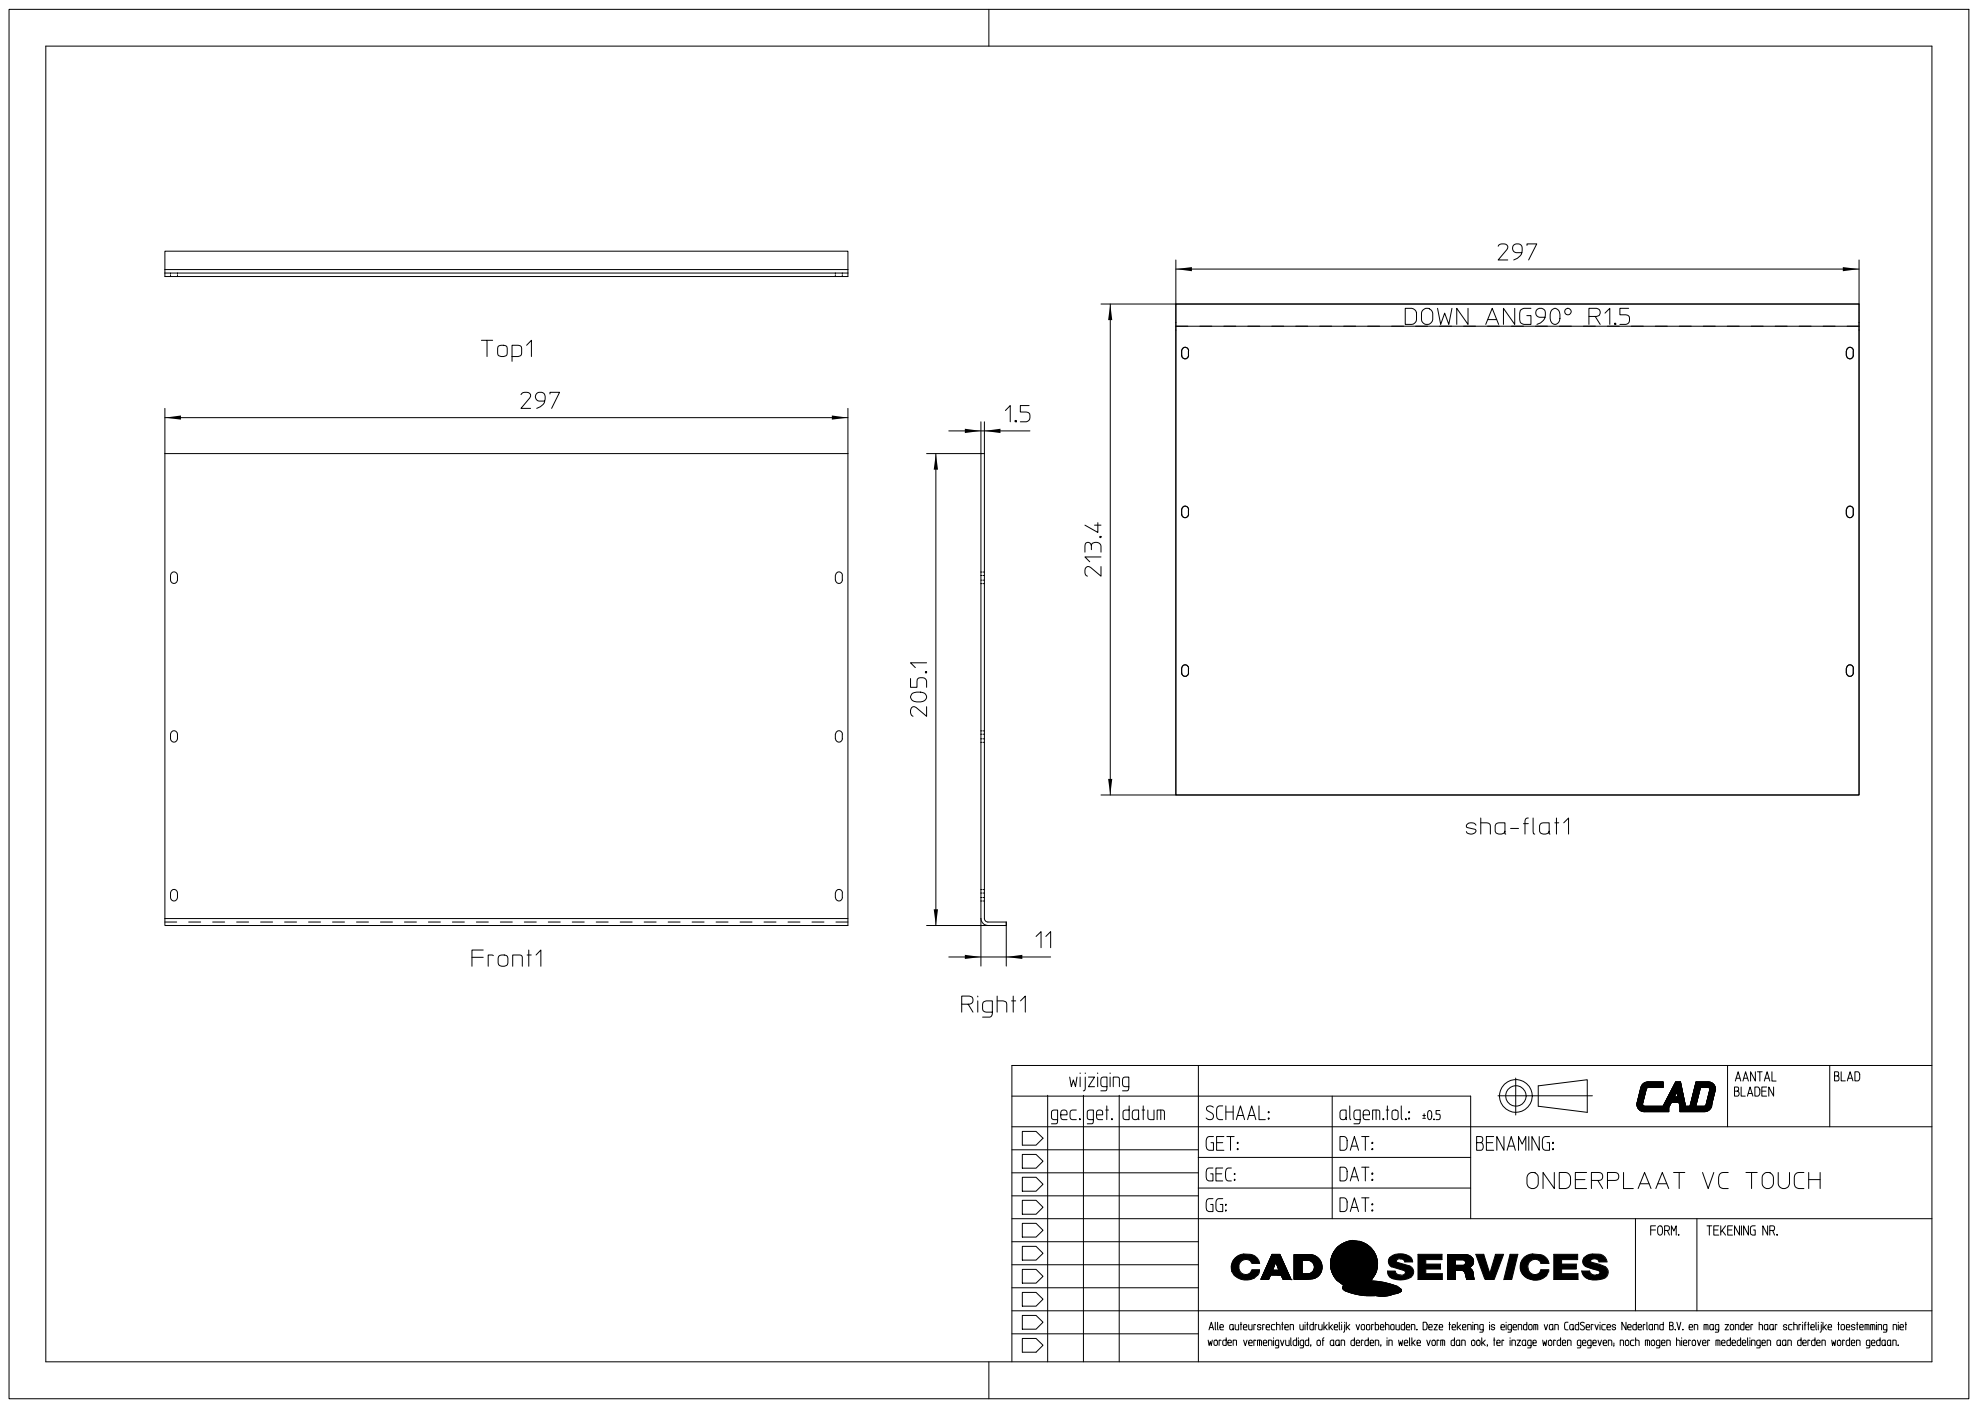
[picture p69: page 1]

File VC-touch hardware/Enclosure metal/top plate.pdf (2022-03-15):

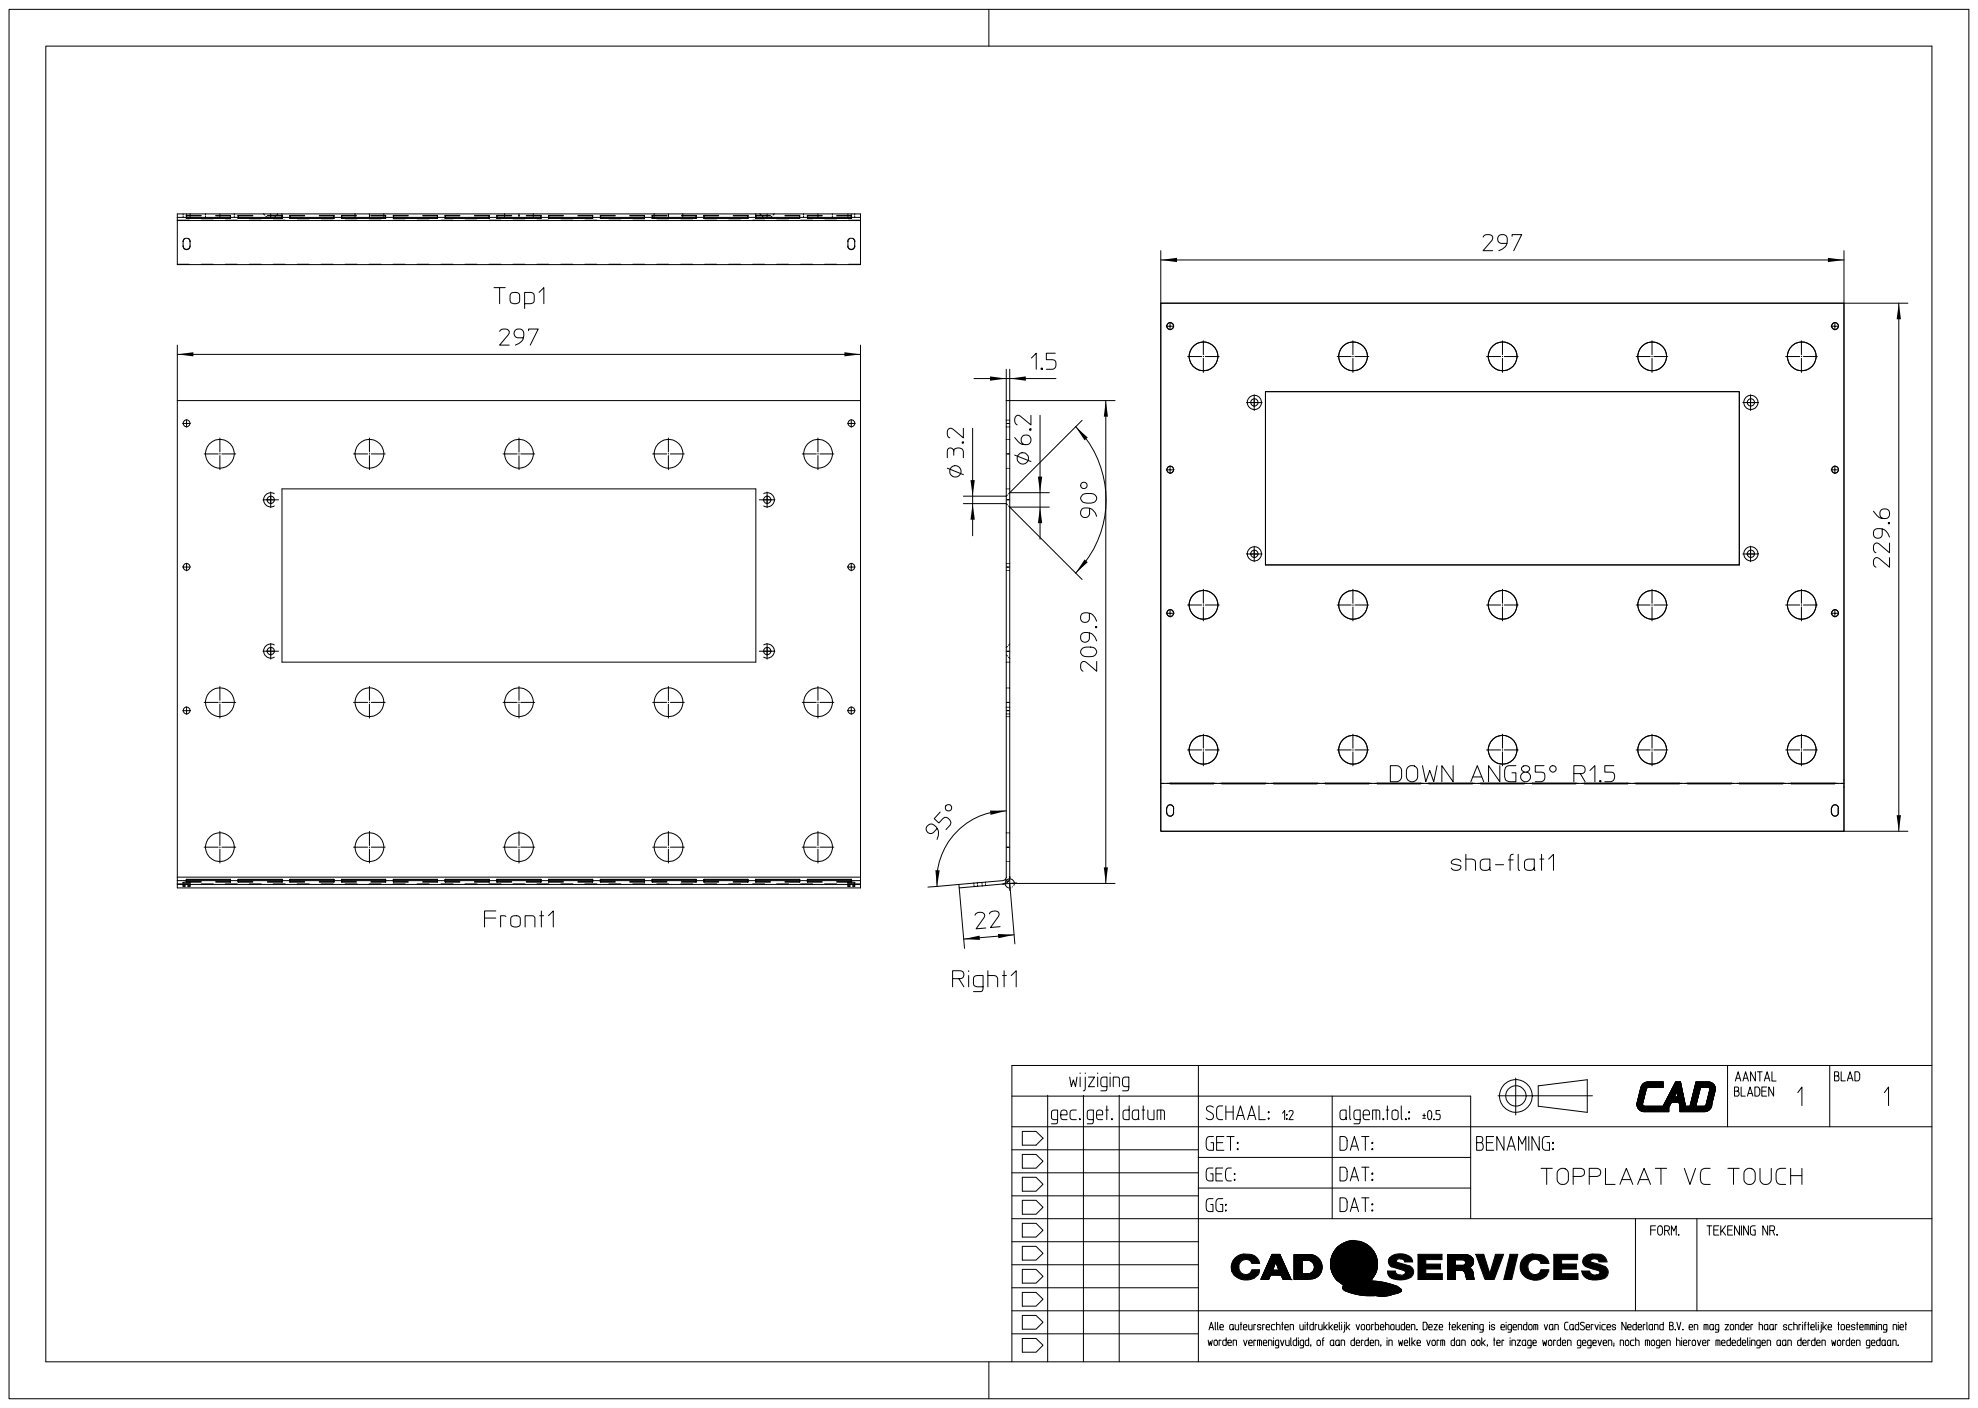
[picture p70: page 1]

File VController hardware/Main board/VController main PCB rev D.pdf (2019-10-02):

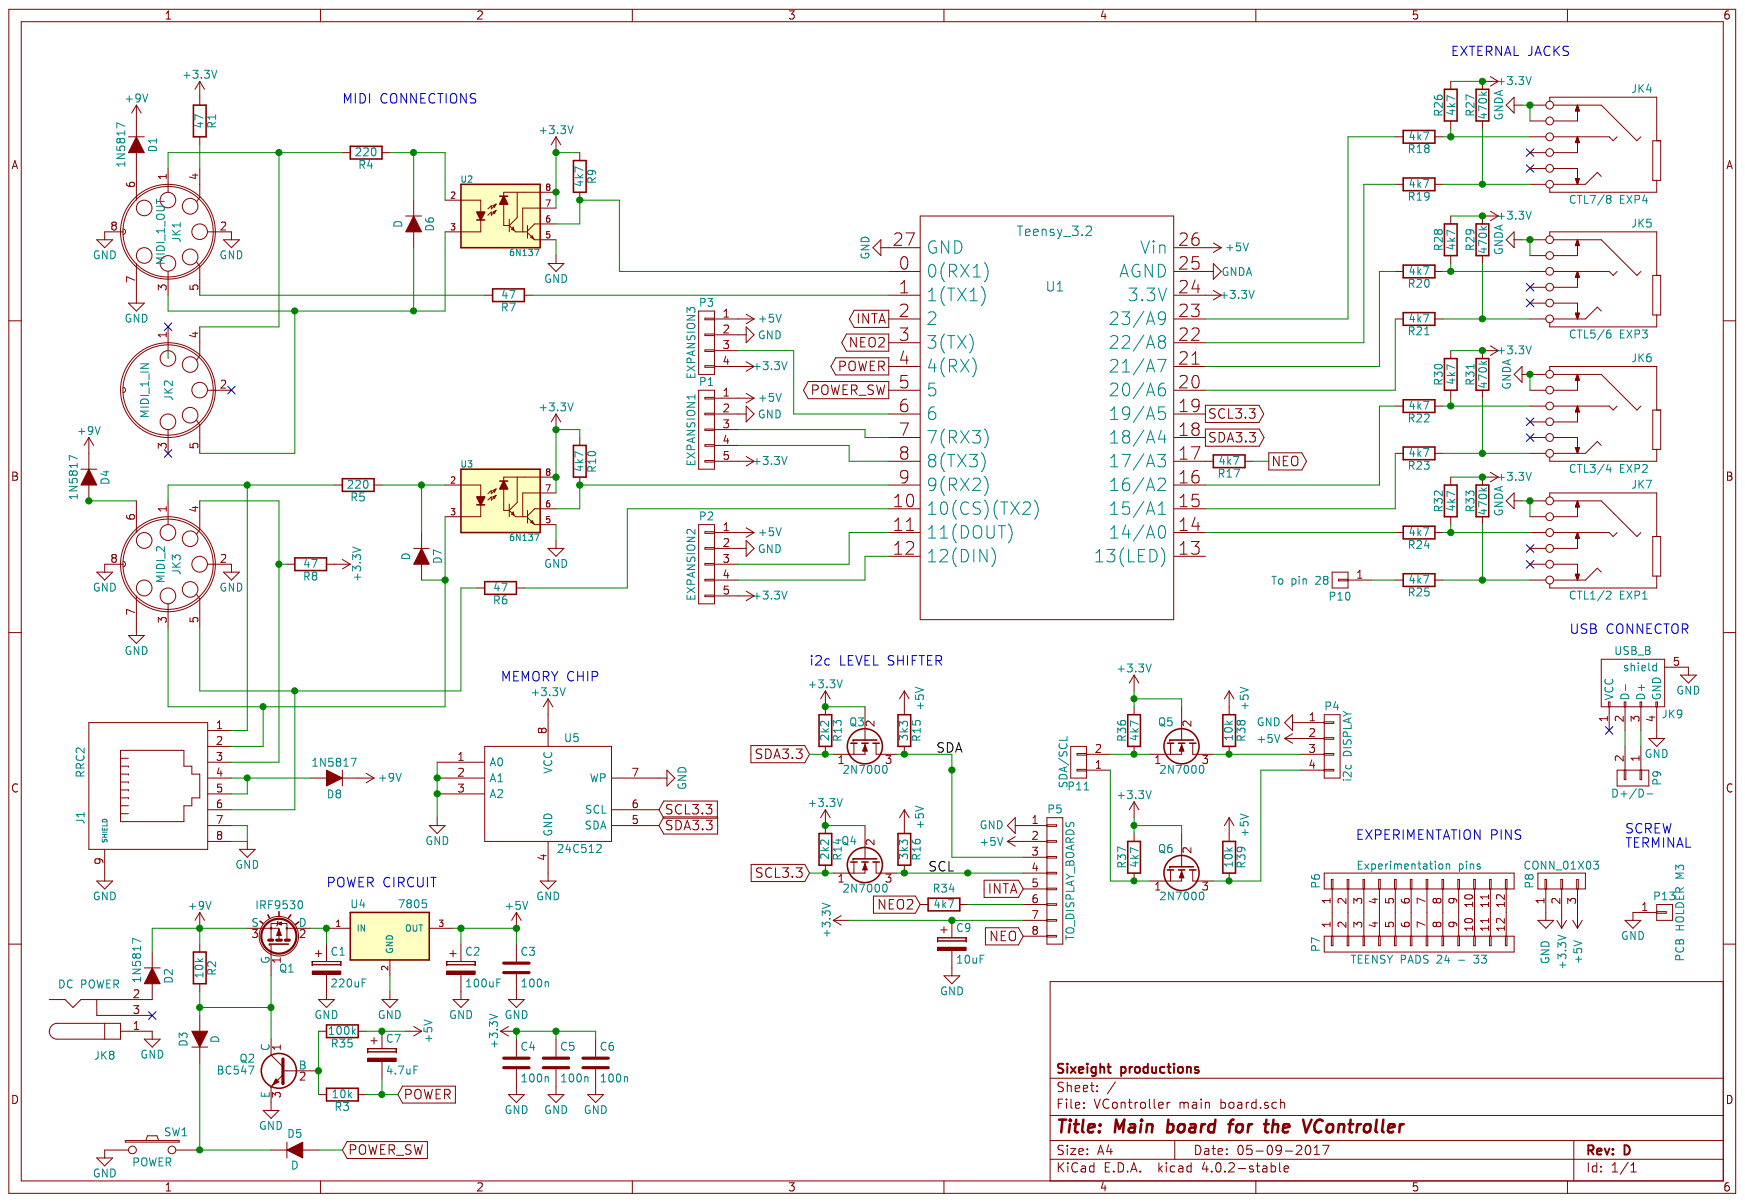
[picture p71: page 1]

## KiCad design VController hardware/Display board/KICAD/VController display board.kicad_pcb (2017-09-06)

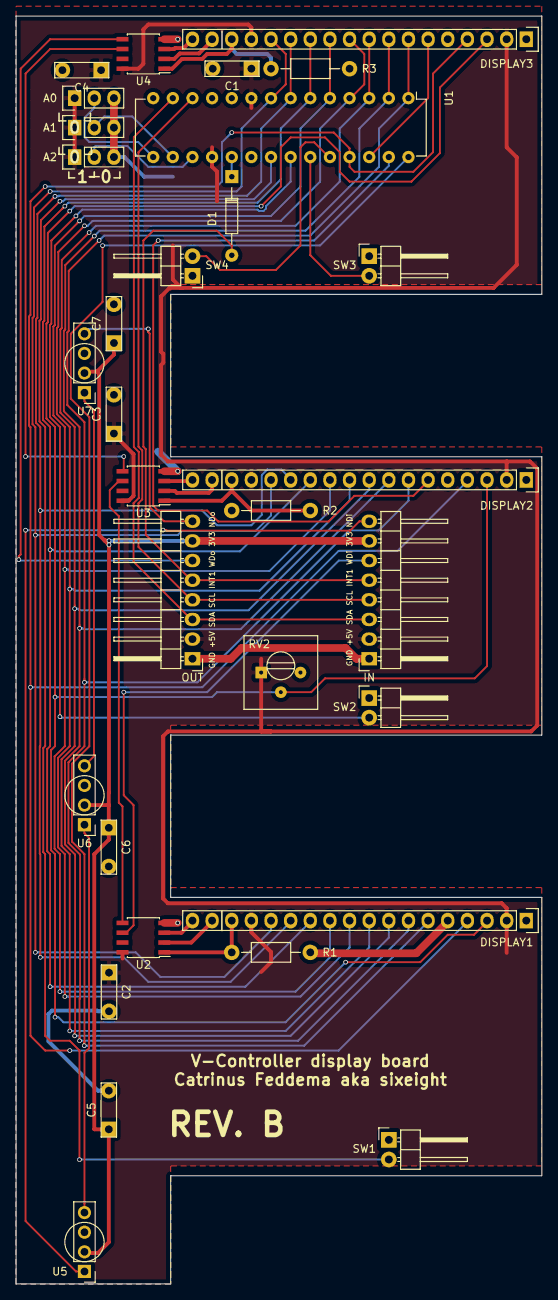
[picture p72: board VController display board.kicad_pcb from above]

Board: 2 copper layers, 68.0 x 164.0 mm, 31 parts (0 on the bottom side), 44 nets.

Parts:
A0, A1, A2: JUMPER3; Pin_Header_Straight_1x03
C1, C2, C3, C4, C5, C6, C7: 100n; C_small_CF
D1: D; Diode_DO-35_SOD27_Horizontal_RM10
DISPLAY1, DISPLAY2, DISPLAY3: LCD16X2RGB; Socket_Strip_Straight_1x18
P1: IN; Pin_Header_Angled_1x08
P2: OUT; Pin_Header_Angled_1x08
R1, R2, R3: 220; Resistor_Horizontal_RM10mm
RV2: POT; Potentiometer_Trimmer-Suntan-TSR-3386P
SW1, SW2, SW3, SW4: SW_PUSH; Pin_Header_Angled_1x02
U1: MCP23017; DIP-28_W7.62mm
U2, U3, U4: WS2811; SOIC-8_3.9x4.9mm_Pitch1.27mm
U5, U6, U7: NEOPIXEL_LED; NeoPixel_CF

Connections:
+3V3: C5.1, C6.1, C7.1, P1.7, P2.7, U5.2, U6.2, U7.2
+5V: A0.1, A1.1, A2.1, C1.1, C2.1, C3.1, C4.1, DISPLAY1.2, DISPLAY1.15, DISPLAY2.2, DISPLAY2.15, DISPLAY3.2, DISPLAY3.15, P1.2, P2.2, RV2.1, U1.9, U1.18, U2.8, U3.8, U4.8
GND: A0.3, A1.3, A2.3, C1.2, C2.2, C3.2, C4.2, C5.2, C6.2, C7.2, DISPLAY1.1, DISPLAY1.5, DISPLAY2.1, DISPLAY2.5, DISPLAY3.1, DISPLAY3.5, P1.1, P2.1, R1.2, R2.2, R3.2, RV2.3, SW1.1, SW2.1, SW3.1, SW4.1, U1.10, U2.4, U3.4, U4.4, U5.3, U6.3, U7.3
unnamed: A0.2, U1.15
unnamed: A1.2, U1.16
unnamed: A2.2, U1.17
unnamed: D1.1, U1.19
unnamed: D1.2, P1.5, P2.5
unnamed: DISPLAY1.3, DISPLAY2.3, DISPLAY3.3, RV2.2
unnamed: DISPLAY1.4, DISPLAY2.4, DISPLAY3.4, U1.25
unnamed: DISPLAY1.6, U1.28
unnamed: DISPLAY1.7, DISPLAY2.7, DISPLAY3.7, U1.1
unnamed: DISPLAY1.8, DISPLAY2.8, DISPLAY3.8, U1.2
unnamed: DISPLAY1.9, DISPLAY2.9, DISPLAY3.9, U1.3
unnamed: DISPLAY1.10, DISPLAY2.10, DISPLAY3.10, U1.4
unnamed: DISPLAY1.11, DISPLAY2.11, DISPLAY3.11, U1.5
unnamed: DISPLAY1.12, DISPLAY2.12, DISPLAY3.12, U1.6
unnamed: DISPLAY1.13, DISPLAY2.13, DISPLAY3.13, U1.7
unnamed: DISPLAY1.14, DISPLAY2.14, DISPLAY3.14, U1.8
unnamed: DISPLAY1.16, R1.1, U2.1
unnamed: DISPLAY1.17, U2.2
unnamed: DISPLAY1.18, U2.3
unnamed: DISPLAY2.6, U1.27
unnamed: DISPLAY2.16, R2.1, U3.1
unnamed: DISPLAY2.17, U3.2
unnamed: DISPLAY2.18, U3.3
unnamed: DISPLAY3.6, U1.26
unnamed: DISPLAY3.16, R3.1, U4.1
unnamed: DISPLAY3.17, U4.2
unnamed: DISPLAY3.18, U4.3
unnamed: P1.3, P2.3, U1.13
unnamed: P1.4, P2.4, U1.12
unnamed: P1.6, U2.6
unnamed: P1.8, U5.1
unnamed: P2.6, U4.5
unnamed: P2.8, U7.4
unnamed: SW1.2, U1.21
unnamed: SW2.2, U1.22
unnamed: SW3.2, U1.23
unnamed: SW4.2, U1.24
unnamed: U2.5, U3.6
unnamed: U3.5, U4.6
unnamed: U5.4, U6.1
unnamed: U6.4, U7.1

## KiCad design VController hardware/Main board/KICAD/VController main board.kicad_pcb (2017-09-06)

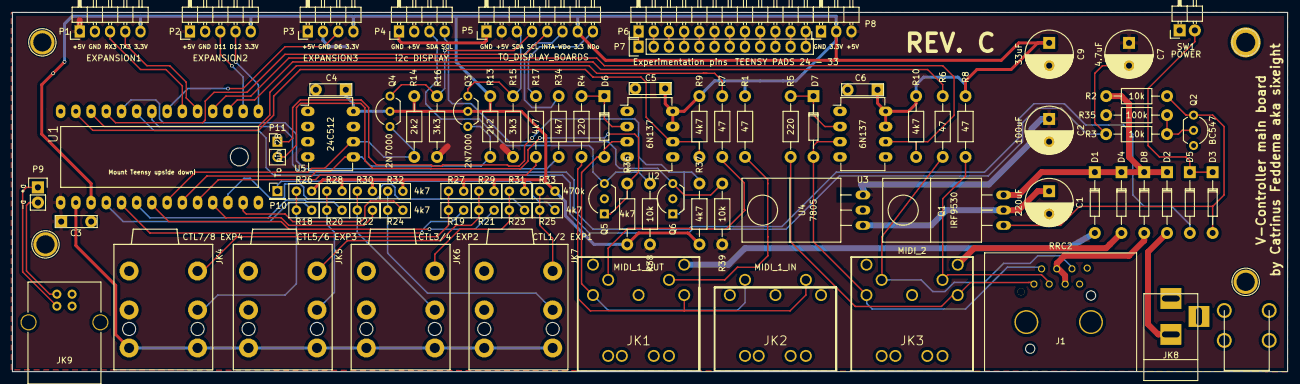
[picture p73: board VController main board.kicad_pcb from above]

Board: 2 copper layers, 213.0 x 60.0 mm, 87 parts (0 on the bottom side), 77 nets.

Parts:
C1: 220uF; C_Radial_D8_L13_P3.8
C2: 100uF; C_Radial_D8_L13_P3.8
C3, C4, C5, C6: 100n; C_small_CF
C7: 4.7uF; C_Radial_D8_L13_P3.8
C9: 33uF; C_Radial_D8_L13_P3.8
D1, D2, D4, D8: 1N5817; Diode_DO-35_SOD27_Horizontal_RM10
D3, D5, D6, D7: D; Diode_DO-35_SOD27_Horizontal_RM10
J1: RRC2; Neutrik_Ethercon_NE8FBH-S_CF
JK1: MIDI_1_OUT; DIN_7_CF
JK2: MIDI_1_IN; DIN_5_CF
JK3: MIDI_2; DIN_7_CF
JK4: CTL7/8 EXP4; NEUTRIK_NRJ6HF
JK5: CTL5/6 EXP3; NEUTRIK_NRJ6HF
JK6: CTL3/4 EXP2; NEUTRIK_NRJ6HF
JK7: CTL1/2 EXP1; NEUTRIK_NRJ6HF
JK8: DC POWER; BARREL_JACK
JK9: USB_B
P1: EXPANSION1; Pin_Header_Angled_1x05
P2: EXPANSION2; Pin_Header_Angled_1x05
P3: EXPANSION3; Pin_Header_Angled_1x04
P4: i2c DISPLAY; Pin_Header_Angled_1x04
P5: TO_DISPLAY_BOARDS; Pin_Header_Angled_1x08
P6: Experimentation pins; Pin_Header_Angled_1x12
P7: TEENSY PADS 24 - 33; Pin_Header_Straight_1x12
P8: CONN_01X03; Pin_Header_Angled_1x03
P9: D+/D-; Pin_Header_Straight_1x02
P10: To pin 28; Pin_Header_Straight_1x01_Pitch2.54mm
P11: SDA/SCL; Pin_Header_Straight_1x02_Pitch2.54mm
P13: PCB HOLDER M3; PCB_HOLDER_M3
Q1: IRF9530; TO-220_Flat_CF
Q2: BC547; TO-92_Inline_Wide
Q3, Q4, Q5, Q6: 2N7000; TO-92_Inline_Wide
R1, R6, R7, R8: 47; Resistor_Horizontal_RM10mm
R2, R3, R38, R39: 10k; Resistor_Horizontal_RM10mm
R4, R5: 220; Resistor_Horizontal_RM10mm
R9, R10, R17, R34, R36, R37: 4k7; Resistor_Horizontal_RM10mm
R13, R14: 2k2; Resistor_Horizontal_RM10mm
R15, R16: 3k3; Resistor_Horizontal_RM10mm
R18, R19, R20, R21, R22, R23, R24, R25, R26, R28, R30, R32: 4k7; RESISTOR_NETWORK
R27, R29, R31, R33: 470k; RESISTOR_NETWORK
R35: 100k; Resistor_Horizontal_RM10mm
SW1: POWER; Pin_Header_Angled_1x02
U1: Teensy_3.2; Teensy-3.1_CF_oval_pads_reversed
U2, U3: 6N137; DIP-8_W7.62mm_LongPads
U4: 7805; TO-220_Flat_CF
U5: 24C512; DIP-8_W7.62mm_LongPads

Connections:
+3V3: C4.1, C5.1, C6.1, C9.1, P1.5, P2.5, P3.4, P5.7, P8.2, Q3.2, Q4.2, R1.1, R8.1, R9.1, R10.1, R13.1, R14.1, R26.2, R27.2, R28.2, R29.2, R30.2, R31.2, R32.2, R33.2, R36.2, R37.2, U1.24, U2.7, U2.8, U3.7, U3.8, U5.8
+5V: C2.1, C3.1, C7.1, P1.1, P2.1, P3.1, P4.2, P5.2, P8.3, R15.1, R16.1, R35.1, R38.1, R39.1, U1.26, U4.3
+9V: D1.1, D2.1, D4.1, D8.1, Q1.3, R2.1
/SCL: P5.4, Q4.3, R16.2
/SDA: P5.3, Q3.3, R15.2
GND: C1.2, C2.2, C3.2, C4.2, C5.2, C6.2, C9.2, J1.7, J1.8, J1.9, JK1.2, JK1.7, JK1.8, JK3.2, JK3.7, JK3.8, JK8.1, JK9.4, JK9.5, P1.2, P2.2, P3.2, P4.1, P5.1, P8.1, P13.1, Q2.3, SW1.1, U1.27, U2.5, U3.5, U4.2, U5.1, U5.2, U5.3, U5.4, U5.7
GNDA: JK4.S, JK4.S-, JK5.S, JK5.S-, JK6.S, JK6.S-, JK7.S, JK7.S-, U1.25
INTA: P5.5, U1.2
NEO: P5.8, R17.1
NEO2: R34.2, U1.3
unnamed: C1.1, Q1.2, U4.1
unnamed: D1.2, JK1.6
unnamed: D2.2, JK8.2
unnamed: D3.1, D5.1, SW1.2
unnamed: D3.2, Q1.1, Q2.1, R2.2
unnamed: D4.2, JK3.6
unnamed: D6.1, R4.1, U2.2
unnamed: D6.2, JK1.3, JK2.5, U2.3
unnamed: D7.1, R5.1, U3.2
unnamed: D7.2, J1.2, JK3.3, U3.3
unnamed: D8.2, J1.4, J1.5
unnamed: J1.1, JK3.1, R5.2
unnamed: J1.3, JK3.4, R8.2
unnamed: J1.6, JK3.5, R6.2
unnamed: JK1.1, JK2.4, R4.2
unnamed: JK1.4, R1.2
unnamed: JK1.5, R7.2
unnamed: JK4.R, R18.1, R26.1
unnamed: JK4.T, R19.1, R27.1
unnamed: JK5.R, R20.1, R28.1
unnamed: JK5.T, R21.1, R29.1
unnamed: JK6.R, R22.1, R30.1
unnamed: JK6.T, R23.1, R31.1
unnamed: JK7.R, R24.1, R32.1
unnamed: JK7.T, R25.1, R33.1
unnamed: JK9.2, P9.2
unnamed: JK9.3, P9.1
unnamed: P1.3, U1.7
unnamed: P1.4, U1.8
unnamed: P2.3, U1.11
unnamed: P2.4, U1.12
unnamed: P3.3, U1.6
unnamed: P4.3, Q5.3, R38.2
unnamed: P4.4, Q6.3, R39.2
unnamed: P5.6, R34.1
unnamed: P6.1, P7.1
unnamed: P6.2, P7.2
unnamed: P6.3, P7.3
unnamed: P6.4, P7.4
unnamed: P6.5, P7.5
unnamed: P6.6, P7.6
unnamed: P6.7, P7.7
unnamed: P6.8, P7.8
unnamed: P6.9, P7.9
unnamed: P6.10, P7.10
unnamed: P6.11, P7.11
unnamed: P6.12, P7.12
unnamed: P10.1, R25.2
unnamed: P11.1, Q6.1, R37.1
unnamed: P11.2, Q5.1, R36.1
unnamed: Q2.2, R3.2, R35.2
unnamed: R6.1, U1.10
unnamed: R7.1, U1.1
unnamed: R9.2, U1.0, U2.6
unnamed: R10.2, U1.9, U3.6
unnamed: R17.2, U1.17
unnamed: R18.2, U1.23
unnamed: R19.2, U1.22
unnamed: R20.2, U1.21
unnamed: R21.2, U1.20
unnamed: R22.2, U1.16
unnamed: R23.2, U1.15
unnamed: R24.2, U1.14
POWER: C7.2, R3.1, U1.4
POWER_SW: D5.2, U1.5
SCL3.3: Q4.1, R14.2, U1.19, U5.6
SDA3.3: Q3.1, R13.2, U1.18, U5.5

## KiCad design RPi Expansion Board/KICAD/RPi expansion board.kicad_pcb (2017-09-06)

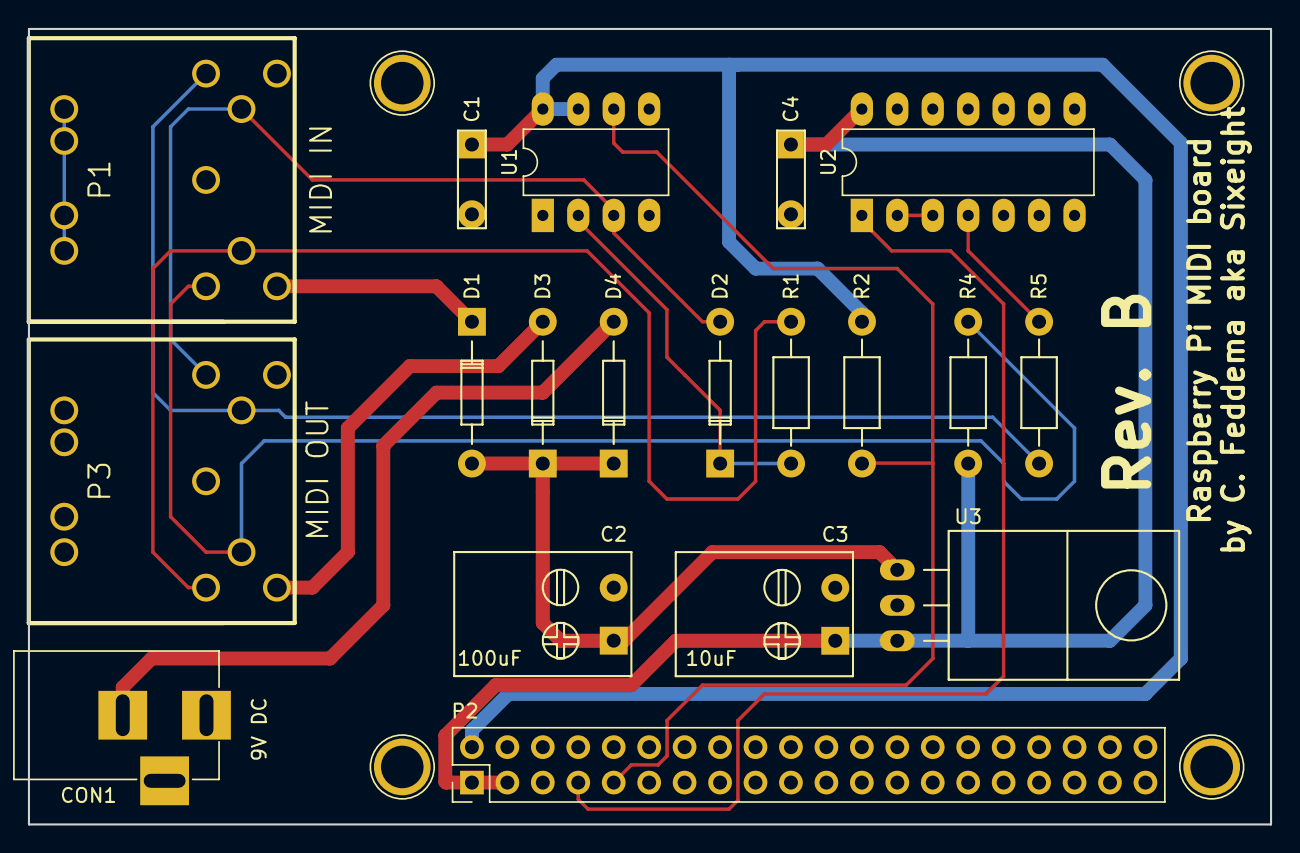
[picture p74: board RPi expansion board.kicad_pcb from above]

Board: 2 copper layers, 89.0 x 57.0 mm, 19 parts (0 on the bottom side), 16 nets.

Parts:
C1, C4: 100n; C_small_CF
C2: 100uF; C_Radial_FLAT
C3: 10uF; C_Radial_FLAT
CON1: 9V DC; BARREL_JACK
D1, D2, D3, D4: D; Diode_DO-35_SOD27_Horizontal_RM10
P1: MIDI IN; DIN_7_CF
P2: GPIO; Pin_Header_Straight_2x20_Pitch2.54mm
P3: MIDI OUT; DIN_7_CF
R1, R4, R5: 220; Resistor_Horizontal_RM10mm
R2: 4k7; Resistor_Horizontal_RM10mm
U1: 6N138; DIP-8_W7.62mm_LongPads
U2: 74HC14; DIP-14_W7.62mm_LongPads
U3: LM7805CT; TO-220_Flat_CF

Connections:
+3V3: C1.1, P2.2, R2.2, U1.7, U1.8
+5V: C3.1, C4.1, P2.1, P2.3, R4.1, U2.14, U3.3
+9V: C2.1, D1.2, D3.1, D4.1, U3.1
GND: C1.2, C2.2, C3.2, C4.2, CON1.1, P1.7, P2.5, P2.10, P2.13, P2.19, P2.26, P2.29, P2.33, P2.40, P3.2, P3.7, P3.8, U1.5, U2.5, U2.7, U2.9, U2.11, U2.13, U3.2
MRX+: P1.4, P3.1, R1.2
MRX-: D2.2, P1.5, P3.3, U1.3
MTX+: P1.1, P3.4, R4.2
MTX-: P1.3, P3.5, R5.2
unnamed: CON1.2, D4.2
unnamed: D1.1, P1.6
unnamed: D2.1, R1.1, U1.2
unnamed: D3.2, P3.6
unnamed: R5.1, U2.4
unnamed: U2.2, U2.3
RX: P2.9, R2.1, U1.6
TX: P2.7, U2.1

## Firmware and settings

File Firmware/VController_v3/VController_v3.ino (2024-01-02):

/****************************************************************************
**
** Copyright (C) 2015 Catrinus Feddema
** All rights reserved.
** This file is part of "VController v3" teensy software.
**
** This program is free software; you can redistribute it and/or modify
** it under the terms of the GNU General Public License as published by
** the Free Software Foundation; either version 2 of the License, or
** (at your option) any later version.
**
** This program is distributed in the hope that it will be useful,
** but WITHOUT ANY WARRANTY; without even the implied warranty of
** MERCHANTABILITY or FITNESS FOR A PARTICULAR PURPOSE.  See the
** GNU General Public License for more details.
**
** You should have received a copy of the GNU General Public License along
** with this program; if not, write to the Free Software Foundation, Inc.,
** 51 Franklin Street, Fifth Floor, Boston, MA 02110-1301 USA.
**
** If you use this code in a homebuild project, please support me by sending
** a donation via https://www.paypal.me/sixeight
** If you want to build VControllers, VC-mini's or VC-touches commercially, 
** please contact me on SixEightSoundControl|@gmail.com.
****************************************************************************/

// This page has the following parts:
// Section 1: Hardware selection
// Section 2: Library declaration and main setup() and loop()
// Section 3: VController documentation overview
// Section 4: VController project log

// ********************************* Section 1: Hardware selection ********************************************

// **** Choose the correct hardware below and update the Arduino compiler settings ****
// Current version of TeensyDuino: 1.8.19

// Hardware of VController production model modified for Teensy 4.1
//#include "hardware.h"
// Arduino IDE settings: Board: Teensy 4.1, USB Type: MIDI, CPU speed: 600 MHz, Optimize: Faster, Programmer: -

// Hardware of VC-touch
//#include "hardware_VCtouch.h"
// Arduino IDE settings: Board: Teensy 4.1, USB Type: MIDI, CPU speed: 600 MHz, Optimize: Faster, Programmer: -

// Hardware of VC-mini rev. B (Teensy 4.1)
#include "hardware_VCmini_41.h"
// Arduino IDE settings: Board: Teensy 4.1, USB Type: MIDI, CPU speed: 600 MHz, Optimize: Faster, Programmer: -

// Hardware of VC-mini rev. B (Teensy 3.6)
//#include "hardware_VCmini_b.h"
// Arduino IDE settings: Board: Teensy 3.6, USB Type: MIDI, CPU speed: 180 MHz, Optimize: Fast(!), Programmer: AVRISP mkII

// Hardware of VController V1 model of sixeight
//#include "hardware1.h"
// Arduino IDE settings: Board: Teensy 3.1/3.2, USB Type: MIDI, CPU speed: 96 MHz, Optimize: Smallest code with LTO, Programmer: AVRISP mkII

// Hardware of VController model of Willem Smith
//#include "hardware_WS.h"
//#include "hardware_VCmini_1.h"
// Arduino IDE settings: Board: Teensy 3.6, USB Type: MIDI, CPU speed: 180 MHz, Optimize: Fast, Programmer: AVRISP mkII

// In order for the Serial MIDI ports to receive larger messages the following files have to be edited:
// Win: C:\Program Files (x86)\Arduino\hardware\teensy\avr\cores\teensy3\serial1.c
// Mac: /Applications/Arduino.app/Contents/Java/hardware/teensy/avr/cores/teensy3/serial1.c
// Change the number 64 to 650 on the following line:
// #define SERIAL1_RX_BUFFER_SIZE 650
// Do the same thing for serial2.c and serial3.c

// ********************************* Section 2: Library declaration and main setup() and loop() ********************************************

// Used libraries:
// * https://github.com/sixeight7/ER-TFTM0784-1
// * https://github.com/sixeight7/arduino-goodix
// * https://github.com/sixeight7/extEEPROM
// * https://github.com/sixeight7/MIDI4.3 
// * https://github.com/sixeight7/encoder
// * https://github.com/sixeight7/LiquidCrystal

#if defined(__MK20DX128__) || defined(__MK20DX256__) || defined(__MK64FX512__) || defined(__MK66FX1M0__)
#include <i2c_t3.h>
#else
#include <Wire.h>
//#include <i2c_driver.h>
//#include <i2c_driver_wire.h>
#endif

#ifdef IS_VCTOUCH
#include <Goodix.h> // Must be declared on first page, otherwise sketch will not compile
#endif

#define VCONTROLLER_FIRMWARE_VERSION_MAJOR 3
#define VCONTROLLER_FIRMWARE_VERSION_MINOR 12
#define VCONTROLLER_FIRMWARE_VERSION_BUILD 1

#include "debug.h"
#include "globals.h"

void setup() {
  SCO_switch_power_on();
  setup_LED_control(); //Should be first, to reduce startup flash of Neopixel LEDs
  setup_debug();

  // Wire speeds are set in hardware.h
#if defined(__MK20DX128__) || defined(__MK20DX256__) || defined(__MK64FX512__) || defined(__MK66FX1M0__)
  Wire.begin(I2C_MASTER, 0x00, I2C_PINS_18_19, I2C_PULLUP_EXT, WIRE_SPEED);
#else
  pinMode(18, INPUT_PULLUP);
  pinMode(19, INPUT_PULLUP);
  Wire.setClock(WIRE_SPEED);
  Wire.begin();
#endif
#ifdef WIRE2_SPEED
  pinMode(24, INPUT_PULLUP);
  pinMode(25, INPUT_PULLUP);
  Wire2.setClock(WIRE2_SPEED);
  Wire2.begin();
#endif

  setup_LCD_control();
  setup_devices();
  setup_eeprom();
  setup_switch_check();
  setup_switch_control();
  setup_page();
  setup_MIDI_common();
  check_all_devices_for_manual_connection();
  DEBUGMAIN("Setup finished");
}

void loop() {
  main_switch_check(); // Check for switches pressed
  main_switch_control(); //If switch is pressed, take the configured action
  main_LED_control(); //Check update of LEDs
  main_LCD_control(); //Check update of displays
  main_MIDI_common(); //Read MIDI ports
  main_page(); // Check update of current page
  main_devices();
  main_eeprom();
  //MIDI_check_USBHMIDI();
}

// ********************************* Section 3: VController documentation overview  ********************************************

/* VController version 3.

  Hardware VController;
  - 16 momentary switches connected to display boards or in keypad matrix
  - 12  neopixel LEDs
  - 12 LCD displays for first 12 switches + main LCD display - all 16x2 character displays
  - Teensy 3.2
  - 3 MIDI input/outputs and MIDI over USB. Support for external Raspberry Pi running VCbridge to add extra ports.
  - Extra EEPROM Flash memory: 24LC512

  Hardware VC-mini
  - 3 - 6 momentary switches connected to Teensy directly
  - 2 rotary encoders with push button
  - 3 or more  neopixel LEDs
  - 1 main LCD display - a 16x2 character displays
  - Teensy 3.6
  - 2 MIDI input/outputs, a USB MIDI host port and MIDI over USB. Support for external Raspberry Pi running VCbridge to add extra ports.
  - Extra EEPROM Flash memory: 24LC512

  Software features:
  - Patch and parameter control for the following devices:
      Boss GP-10, Roland GR-55, Roland VG-99, Boss Katana
      Zoom G3, Zoom MS SERIES
      Line6 M13, Line6 Helix
      AxeFX II (other types implemented but not tested)
      Kemper Profiling Amp
  - Patchnames are read from devices (apart from the Line6 Helix)
  - Parameter states and assigns are read from devices (apart from Line6 Helix)
  - Programmable pages of switches. These can be programmed on the VController of VC-mini or via the external editor

  Software structure:
  - Initialization of LCDs, LEDs and MIDI ports
  - Configuration of the pages and switches is done in the page[] array on the Config page.
  - On startup, detection of devices, page change or patch change the current page is loaded in the SP[] array (void load_page)
  - After the page is loaded, the patchnames and parameter states are read (void Request_first_switch, Request_next_switch and PAGE_request_current_switch)
  - Main loop checks for switches being pressed (Switch_check/Switch Control), midi received and update of LCD and LED states.

*/

// ********************************* Section 4: VController project log  ********************************************

/*
  23-06-2015 First VController design ready
  14-07-2015 v.1.0.0 First basic version of VController ready.
  17-07-2015 Added global tuner
  04-08-2015 Added assigns for VG99
  11-08-2015 Added US20 emulation
  16-08-2015 Added global tempo
  10-11-2015 v.2.0.0 Start programming v2. Developed structure for VController
  19-11-2015 Finished GP10 patch selection mode
  20-12-2015 Patch change mode for GR55 and VG99 as well.
  22-12-2015 US20 emulation done
  24-12-2015 Wrote PATCH modes and fixed Bank up/down problems
  24-12-2015 Problem with occasional reboot in VG99 patch change. Previous version did not seem to have this problem...
  26-12-2015 Started writing assign mode for GP-10. Does contains bugs.
  27-12-2015 Assign mode finished. Bug was a string written out of bounds..
  29-12-2015 Programmed TRI/FOUR/(FIVE)STATE options in GP10
  30-12-2015 Parameter and assign_mode for GR55 written
  31-12-2015 Allow for multiple commands / added tap tempo and bass mode from version 1
  01-01-2016 Parameter and assign mode for VG-99
  02-01-2016 Added FC300 CTL1-8 for VG-99
  17-01-2016 Worked on individual display messages
  2?-03-2016 Updated firmware to work with the new hardware
  30-03-2016 Simplified updating individual displays
  02-04-2016 Added EEPROM.ino with global read/store and on/standbye mode for the VController
  13-06-2016 Started adding page for Zoom G3
  11-07-2016 Changed LCD_set_patch_number_and_name() so the main display can deal with the Zoom G3 and more devices as well
  12-07-2016 Added virtual LEDs (LED state in display)
  16-07-2016 Changed GP10/GR55/VG99/ZG3_detected into connect/offline system.
  26-07-2016 Updated inconsistent display update system
  27-07-2016 Consistent naming scheme for all functions and voids
  28-07-2016 Added support for expression pedals - they send fixed cc messages now
  30-12-2016 v.3.0.0 Started rewriting code into class structure
  11-02-2017 Changed structure of pages to new style with unlimited commands
  13-02-2017 Implemented default page for commands - this makes programming much more flexible...
  14-02-2017 Added bass mode for GR-55
  23-02-2017 Added support for multiple hardware - moving all hardware settings to hardware.h. Added compatibility for the new production model
  20-03-2017 Added support for VCbridge - virtual ports on s Raspberry pi
  27-03-2017 The commands array is now written to the extermal chip and read back into the memory
  17-04-2017 Added STEP type parameter
  27-05-2017 New parameter view for GP10/GR55 and VG99 - added PAR_BANK
  29-05-2017 Updated VG99 parameter list. Added EXP1,2 + EP SW1,2 assigns
  30-05-2017 Added switch hold
  01-06-2017 Added UPDOWN latch type.
  07-06-2017 Created global menu amd the menu structure.
  14-06-2017 Added support for expression pedals for VG990 parameters and assigns
  22-06-2017 Added menu command structure. Updated button respons as responded poorly on menus
  28-06-2017 Added new indexes for commands on EEPROM. Improved reading keypresses over i2c
  31-06-2017 Faster reading of new indexes. Tested and fixed executing multiple commands under one button
  08-06-2017 Increased the speed of the i2c connections. Use 1500 kHz for MCP23017 and memory and 800 kHz for PCF8745 expander chips. The production model uses both i2c ports now.
  11-06-2017 First version of command edit implemented - still kind of buggy...
  24-06-2017 Added EEPROM checks for changed data before writing to preserve EEPROM life.
  24-06-2017 Added new FX types for ZMS-cdr version 2.0.0
  27-06-2017 Adding new commands in edit mode finished.
  29-06-2017 Adding new page in edit mode finished
  30-06-2017 Added virtual keyboard for changing page names and labels
  27-07-2017 Added deleting of commands and names. Included purging of commands.
  28-07-2017 Added MIDI_CC messages including the CC ledger (memory for 25 CC values)
  29-07-2017 Added support for VCbridge on every port.
  29-08-2017 Made FX colours programmable from the menu
  30-08-2017 Split fixed and programmable commands
  01-09-2017 Re-arranged menu structure
  08-09-2017 Added PC ledger to have LEDs showing the current "patch" for GM PC. As long as channel and port match the selected PC will light up
  25-09-2017 v3.0.1 Fixed PAGE_UP and PAGE_DOWN not working properly
  04-10-2017 v3.0.2 Updown could not be selected when programming menus
  29-10-2017 New algorithm for bass mode
  04-11-2017 ZMScdr bug not showing patch name fixed. VController now diplaying full version number on powerup. Main display top line behaviour updated.
  05-11-2017 Connect of first new device automatically selects its device page. v3.0.2 published
  11-11-2017 v3.0.3 Support Line6 M13 Patch change. Reading the patch names works, but is too slow for practical use. Tap tempo and global tuner work as well
  13-11-2017 Added basic support for effects and looper control
  19-11-2017 Added full support of Line6 M13 - scenes are read after detection and stored in memory.
  22-11-2017 Added support for control of M13 expression pedals. Also disabled expression pedal triggering other functions.
  01-03-2018 Added support for Line6 Helix - basic control of patch/parameters/snapshots and looper. Also changed the connection system to allow the Helix to connect while it is not detectable.
  17-04-2018 Started with adding some support for the AxeFX2 for Ryan Muar.
  23-04-2018 Started with adding support for Boss Katana
  28-04-2018 Changed LCDs.ino, with better centring of titles and labels for the individual displays. Removed all printf statements
  29-04-2018 Improved direct select - it now shows patchnames and allows bank up/down during selection.
  15-05-2018 Patch selection, IA and XY switches, tap tempo and tuner support for the AxeFX working and tested.
  19-05-2018 Devices can now have up to four pages associated to the device. Selecting the next device will move to the page that was last selected for a specific device.
  20-05-2018 Added master expression pedal. You can edit the menu and command settings with an expression pedal!!!
  23-05-2018 Added calibration menu and implemented the calibration in the code.
  03-06-2018 Added master expression pedal support for GR55 (limited), VG99 and Katana
  04-06-2018 Even faster LCD support. LCD contents are copied in memory and only the changes are written to the displays
  06-06-2018 Added faster LCD support for main display as well.
  13-06-2018 Added looper support with moving ledbar for M13 and Helix
  14-06-2018 Added looper support for the AxeFX
  16-06-2018 AxeFX parameter bank now only shows active effects (bypass and XY states)
  17-06-2018 VG99 parameters are now split in categories
  july 2018  Added editor support for the VController
  29-08-2018 Added port forwarding for Katana editor - works partially - editor gives error on patch sync, but parameters can be edited!
  30-08-2018 Added Katana edit mode, added large part of the parameters, but all the MOD and FX parameters will be too much data. Allowed UPDOWN and RANGE to support large numbers for delay times.
  10-09-2018 Katana can now store 80 extra patches.
  14-09-2018 Made the code for the Katana patch storage more readable. Also the extra parameters of the SDE-3000 are stored on the Katana now.
  15-09-2018 Alpha testing release 3.1. Fixed minor bugs, improved patch reading for G3/MS SERIES, GR55 direct select improved, M13 properly switched between EXP1 and 2. Updated fixed configuration for GR55, Katana and direct select
  22-09-2018 When switching between pages with different bank sizes, the bank with the current patch is now always shown.
  22-09-2018 Release of firmware 3.1
  27-09-2018 Started with KPA support
  20-10-2018 Changed the layout of the PARAMETER and PAR_BANK displays. Took out the device name. Updated this for all devices
  30-10-2018 Fixed bug in UPDOWN behaviour in PAR_BANK. Increaded speed of switch holding
  01-04-2019 Added support for Teensy 3.6 and the USB host port - make sure you use Arduino 1.8.9 and Teensyduino 1.46 to compile for proper Roland device support.GP-10 does not work yet.
  20-04-2019 VController looper now responds to CC looper messages from Helix. Also added the Helix data forwarding mode (from VC-edit rev. A code)
  21-04-2019 Added CC control of all switches and expression pedals.
  22-04-2019 Updated internal editor for MIDI switch support
  28-04-2019 Added VC-edit support for MIDI switches
  30-04-2019 Started VCmini support from main code. Added VCmini mode for main display.
  01-05-2019 Added ON_RELEASE and ON_LONG_PRESS options to make full use of only three switches. Also added the option to press switch 1+2, 2+3 and 1+3 for the VC-mini. VC-edit still must be updated with these changes.
  31-05-2019 Finished updating menu structure for VC-mini.
  03-06-2019 Added Katana v3.0 FX and new KPA reverbs. Fixed several bugs (repressing switch on different page error and MEP parameter control)
  15-06-2019 Added USB hub support for max eight connections and fixed GP-10 sysex communication (needs cable 1)
  17-06-2019 Added Katana editing via encoders for the VC-mini
  24-06-2019 Added double and triple snapshot selection options for snapshots/scenes
  13-07-2019 Fixed looper bar error for longer loops
  16-07-2019 Helix PC/CC forwarding now stores and checks the current setlist. This ensures no faulty messages are sent when changing setlist on the Helix. Fixed wrong label shown on large VController for looper bar
  23-07-2019 Changed format of PAGE, PATCH and ASSIGN commands - also updated the onboard editing and fixed a bug in making new commands.
  09-09-2019 Uploaded V3.3.0 firmware to Github.
  29-09-2019 Implemented new library for encoders that is more stable and supports encoder acceleration - when the encoder is rotated faster, the encoders value will increment faster.
  05-10-2019 Memory versions of external memory are stored on the external EEPROM instead of internal. This is easier when swapping memory chips.
  30-10-2019 v.3.3.3 Solved an issue with changing devices from an external MIDI foot controller. Some MIDI messages were not received, because writing i2c is blocking midi data reception. Writing the current page and device is now delayed.
  02-11-2019 v.3.3.4 Added high string priority. Also added basic support for the Strymon Volante.
  18-11-2019 v.3.3.5 Added custom effect types of the MS-50G and th MS-60B to the MS SERIES. Thanks to Dr. Michael Cvachovec for supplying the custom firmware packages for this.
  30-12-2019 Added Katana patch dump from and to editor
  03-12-2019 Added MIDI clock receive.
  27-12-2019 Added MIDI clock transmit. Also the tap tempo LED turns blue whenever it is synced through MIDI clock. The tap tempo LED is now updated from the MIDI clock timer.
  03-01-2020 Found a workaround for the VG-99 displaying sysex receive messages that freeze the user interface. Solved by sending back a PC MIDI message for the current patch. That supresses the messages
  03-01-2020 Fixed UPDOWN function for the VC-mini.
  11-01-2020 Added support for Buydisplay RGB backlight colour scheme.
  11-01-2020 Changed read/write of Katana patches to allow storage of pedal block parameters. EQ and GEQ parameters are now stored in same location to find the space.
  12-01-2020 Added EQ/GEQ and PEDAL block parameters to the edit page of the VController.
  18-01-2020 Fixed the menu on VController and in VC-edit to work with the new parameters. Fixed some bugs in showing the proper parameter values in VC-edit.
  20-01-2020 v.3.4.0 release version. Is backwards compatible with older versions of the Katana. Version is detected at startup.
  27-01-2020 Fixed some bugs: 1) Sysex errors on sending clock via USB host port - temporary workaround: clock is not sent on this port!
                              2) Changing settings will reset them??? Looks like the labels are disappearing on the VC-mini - labels now always show for page select and menu.
                              3) Last MIDI switch can not be edited - fixed on VController and VC-edit
  17-03-2020 Started developing the SY1000 compatibility remotely with Dave LaBrosse
  28-03-2020 EEPROM is now automatically initialized for new values in settings on firmware upgrades
  29-03-2020 SY1000 code in Alpha - waiting on Dave to finish testing
  06-04-2020 Started developing the TC electronics GMajor-2 compatibility remotely with AndyE of vguitarforums.com
  27-04-2020 Cannot read long sysex messages via serial port - therefore patchnames are not read beforehand on GMajor.
  30-04-2020 USB MIDI name has been renamed from Teensy MIDI to VC MIDI
  01-05-2020 GMajor code is now in Alpha - waiting for AndyE to finish testing
  02-05-2020 External pedals (expression and switches) are now hot pluggable
  03-05-2020 Enabled optional SW 4-6 in the firmware of the VC-mini
  08-05-2020 Added the option to show the tempo instead of the device name at the top right of the main menu.
  09-05-2020 Added CURNUM option in Global Menu with option for Previous patch, tap tempo, tuner and direct select.
  22-05-2020 Fixed Helix/VG99 issue with forwarding PC messages. Fix of 03-01-2020 was causing trouble since firmware 2.9 of Helix
  20-07-2020 v.3.5.0 release Added support for the SY1000 and the GMajor 2. Added hot pluggable expression pedals and CURNUM action.
  22-08-2020 Started support for the NUX MG300.
  23-08-2020 Updated the USBHost_t36 library to support longer sysex messages as that is the only way to communicate with the MG300
  30-08-2020 MS SERIES: toggling effect on the VController now selects that effect on the MS SERIES.
  30-08-2020 NUX MG300 effect control implemented
  02-11-2020 Start implementing Katana MK2
  03-11-2020 Fixed HI-LEVEL of EQ not working properly for Katana. It was swapped with Hi-CUT.
  09-11-2020 Added GEQ support for Global Eq Katana.
  14-11-2020 Fixed delay mod parameters were not properly saved
  16-11-2020 Changed behaviour of encoders. Almost all encoder turns use update_encoder_value(). This will make the encoder stop at minimum and maximum values. After one second you can cross from min to max or vise versa
  18-11-2020 Improved the speed of the encoder for parameters with large ranges (like delay time: 0 - 2000 ms)
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

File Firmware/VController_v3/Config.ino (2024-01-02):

// Please read VController_v3.ino for information about the license and authors

// This page has the following parts:
// Section 1: VController commands
// Section 2: VController configuration for fixed command pages
// Section 3: VController default configuration for programmable pages
// Section 4: VC-mini configuration for fixed command pages
// Section 5: VC-mini configuration for programmable pages
// Section 6: VC-touch configuration for fixed command pages
// Section 7: VC-touch configuration for programmable pages
// Section 8: CUSTOM configuration for fixed command pages
// Section 9: CUSTOM configuration for programmable pages

// ********************************* Section 1: VController commands ********************************************

// Here we define the supported devices
#define GP10 0
#define GR55 1
#define VG99 2
#define ZG3 3
#define ZMS 4
#define M13 5
#define HLX 6
#define AXEFX 7
#define KTN 8
#define KPA 9
#define SVL 10
#define SY1000 11
#define GM2 12
#define MG300 13
#define NUMBER_OF_PROGRAMMED_DEVICES 14

// User devices have higher numbers, so they can always be at the end of the device list
#define USER1 14
#define USER2 15
#define USER3 16
#define USER4 17
#define USER5 18
#define USER6 19
#define USER7 20
#define USER8 21
#define USER9 22
#define USER10 23
#define NUMBER_OF_USER_DEVICES 10

#define NUMBER_OF_DEVICES (NUMBER_OF_PROGRAMMED_DEVICES + NUMBER_OF_USER_DEVICES)


#define CURRENT 254 // To select the current device
#define COMMON 255 // Not really a device, but used for common procedures, that are not device specific or for all devices.

//Possible switch types:
#define LABEL 0xE0 // Bit 6 - 8 of the switch number is set to one all labels - this saved one byte and keeps the command structure short.
#define ON_DUAL_PRESS 0x80 // Switch and right neighbouring switch are pressed
#define ON_LONG_PRESS 0x40
#define ON_RELEASE 0x20
#define SWITCH_MASK 0x1F
#define SWITCH_TYPE_MASK 0xE0

// Example:  {<PAGE>, <SWITCH> | LABEL, 'P', 'A', 'T', 'C', 'H', ' ', ' ', ' ' }

// Common command types
#define NUMBER_OF_COMMON_TYPES 13 // Only the one that can be selected in the command builder
#define NOTHING 0            // Example: {<PAGE>, <SWITCH>, NOTHING, COMMON}
#define PAGE 1               // Example: {<PAGE>, <SWITCH>, PAGE, COMMON, SELECT, PAGE_COMBO1}
#define TAP_TEMPO 2          // Example: {<PAGE>, <SWITCH>, TAP_TEMPO, COMMON}
#define SET_TEMPO 3          // Example: {<PAGE>, <SWITCH>, SET_TEMPO, COMMON, 120}
#define GLOBAL_TUNER 4       // Example: {<PAGE>, <SWITCH>, GLOBAL_TUNER, COMMON}
#define MIDI_PC 5            // Example: {<PAGE>, <SWITCH>, MIDI_PC, COMMON, SELECT, Program, Channel, Port}
#define MIDI_CC 6            // Example: {<PAGE>, <SWITCH>, MIDI_CC, COMMON, Controller, CC_TOGGLE_TYPE, Value1, Value2, Channel, Port}
#define MIDI_NOTE 7          // Example: {<PAGE>, <SWITCH>, MIDI_NOTE, COMMON, Note, Velocity, Channel, Port}
#define SELECT_NEXT_DEVICE 8 // Example: {<PAGE>, <SWITCH>, SELECT_NEXT_DEVICE, COMMON}
#define SETLIST 9            // Example: {<PAGE>, <SWITCH>, SETLIST, COMMON, NEXT}
#define SONG 10              // Example: {<PAGE>, <SWITCH>, SONG, COMMON, NEXT}
#define MODE 11              // Example: {<PAGE>, <SWITCH>, MODE, COMMON, SELECT, 0}
#define MIDI_MORE 12         // Example: {<PAGE>, <SWITCH>, MIDI_PC, COMMON, START}

// Common functions that can not be selected in the command builder
#define NUMBER_OF_COMMON_TYPES_NOT_SELECTABLE 1
#define MENU 13             // Example: {<PAGE>, <SWITCH>, MENU, COMMON, 1} - to display first menu item

// Device command types
#define NUMBER_OF_DEVICE_TYPES 10
#define PATCH 100      // Example: {<PAGE>, <SWITCH>, PATCH, <DEVICE>, 25, 1} - to select patch 125
#define PARAMETER 101      // Example: {<PAGE>, <SWITCH>, PARAMETER, <DEVICE>, 1, TOGGLE, 1, 0}
#define ASSIGN 102         // Example: {<PAGE>, <SWITCH>, ASSIGN, <DEVICE>, SELECT, 1, 21}
#define SNAPSCENE 103      // Example: {<PAGE>, <SWITCH>, SNAPSCENE, <DEVICE>, 1}
#define LOOPER 104         // Example: {<PAGE>, <SWITCH>, LOOPER, <DEVICE>, START}
#define MUTE 105           // Example: {<PAGE>, <SWITCH>, MUTE, <DEVICE>} 
#define OPEN_PAGE_DEVICE 106     // Example: {<PAGE>, <SWITCH>, OPEN_PAGE_DEVICE, ZG3, PAGE_ZOOM_PATCH_BANK}
#define OPEN_NEXT_PAGE_OF_DEVICE 107      // Example: {<PAGE>, <SWITCH>, OPEN_NEXT_PAGE_OF_DEVICE, <DEVICE>}
#define MASTER_EXP_PEDAL 108 // Example: {<PAGE>, <SWITCH>, MASTER_EXP_PEDAL, <DEVICE>, <number>} number of expression pedal: 0, 1, 2 or 3. If 0, it will choose the number as selected with TOGGLE_EXP_PEDAL
#define TOGGLE_EXP_PEDAL 109 // Example: {<PAGE>, <SWITCH>, TOGGLE_EXP_PEDAL, <DEVICE>}
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

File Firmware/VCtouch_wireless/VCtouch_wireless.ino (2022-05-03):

/****************************************************************************
**
** Copyright (C) 2022 Catrinus Feddema
** All rights reserved.
** This file is part of "VCtouch_wireless" ESP32 software.
**
** This program is free software; you can redistribute it and/or modify
** it under the terms of the GNU General Public License as published by
** the Free Software Foundation; either version 2 of the License, or
** (at your option) any later version.
**
** This program is distributed in the hope that it will be useful,
** but WITHOUT ANY WARRANTY; without even the implied warranty of
** MERCHANTABILITY or FITNESS FOR A PARTICULAR PURPOSE.  See the
** GNU General Public License for more details.
**
** You should have received a copy of the GNU General Public License along
** with this program; if not, write to the Free Software Foundation, Inc.,
** 51 Franklin Street, Fifth Floor, Boston, MA 02110-1301 USA.
**
** If you use this code in a homebuild project, please support me by sending
** a donation via https://www.paypal.me/sixeight
** If you want to build VControllers, VC-mini's or VC-touches commercially, 
** please contact me on SixEightSoundControl|@gmail.com.
****************************************************************************/

// This page has the following parts:
// Section 1: Library declaration and main setup() and loop()
// Section 2: VCtouch_wireless documentation overview
// Section 3: VCtouch_wireless project log

// Section 1: Library declaration and main setup() and loop()

// Used libraries:
// * MIDI library 5.0.2
// * NIM-BLE Arduino 1.2.0
// * https://github.com/sixeight7/Arduino-AppleMIDI-Library
// * https://github.com/sixeight7/Arduino-BLE-MIDI
// * preferences - should be part of ESP32 installation
// * WIFI - should be part of ESP32 installation


#include <MIDI.h>
#include "debug.h"

#define VCTOUCH_WL_FIRMWARE_VERSION_MAJOR 1
#define VCTOUCH_WL_FIRMWARE_VERSION_MINOR 0
#define VCTOUCH_WL_FIRMWARE_VERSION_BUILD 0

#define MIDI2_SPEED 500000

#define LED_BUILTIN 2

#define LED_TIME 100
unsigned long led_timer = 0xFFFFFFFF;
bool led_on = false;

// -----------------------------------------------------------------------------
// When BLE connected, LED will turn on (indication that connection was successful)
// When receiving a NoteOn, LED will go out, on NoteOff, light comes back on.
// This is an easy and conveniant way to show that the connection is alive and working.
// -----------------------------------------------------------------------------
void setup()
{
  //Serial.begin(115200);

  setup_debug();
  setup_eeprom();
  setup_MIDI();
  setup_BLE();
  setup_WIFI();

  pinMode(LED_BUILTIN, OUTPUT);
  digitalWrite(LED_BUILTIN, LOW);

  
}

// -----------------------------------------------------------------------------
//
// -----------------------------------------------------------------------------
void loop()
{
  run_MIDI();
  run_BLE();
  run_MIDI();
  run_WIFI();
  run_server();
  check_flash_LED();
}

void flash_LED() {
  digitalWrite(LED_BUILTIN, LOW);
  led_timer = millis() + LED_TIME;
  led_on = false;
}

void check_flash_LED() {
  if (led_on) return;
  if (millis() > led_timer) {
    digitalWrite(LED_BUILTIN, HIGH);
    led_on = true;
  }
}

// Section 2: VCtouch_wireless documentation overview
// This sketch is used for the ESP32 module in the VC-touch. It hass the following features:
// * BLE midi support - so far only in client mode.
// * RTP or applemidi support - also only in client mode.
// * A 500 kHz MIDI connection to the main Teensy of the VC-touch
// * OTA firmware upgrades
// * Active scanning of SSID's.
// * All settings can be made from the VC-touch wireless menu

// Section 3: VCtouch_wireless project log
// 21-07-2021 Started development of the wireless module 
// 23-07-2021 BLE midi working
// 20-08-2021 Added AppleMIDI/RTP MIDI
// 08-01-2022 Made WIFI programmable from the VC-touch. Added scanning of ssid's
// 29-04-2022 Disabled sysex debugging as it seems to slow down communication

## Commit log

2017-03-23 Publish building plans
    [Half support 3xLCD diameter_2_0.stl, Large LCD support_2_0.stl, RPi expansion board bracket.dwg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]
2017-04-09 Updated resistors in display board
2017-09-04 Updated schematics, boards and guide
    [RPi expansion board-B.Cu.gbl, RPi expansion board-B.Mask.gbs, RPi expansion board-B.SilkS.gbo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]
2017-09-04 Added Rpi case
    [bottom part.stl, top part.stl]
2017-09-06 Added Protel gerbers and KICAD files
    [RPi expansion board-B.Cu.gbl, RPi expansion board-B.Mask.gbs, RPi expansion board-B.SilkS.gbo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]
2017-09-23 Updated BOM and power option
2017-09-23 Updated BOM again
2017-10-29 Easier to bend bracket
    [RPi expansion board bracket.dwg]
2018-11-22 Version 1.1
    Added missing diodes in BOM.
2018-11-22 BOM updated
2019-09-09 Firmware v3.3
    Now support for the new VC-mini hardware. Added Teensy 3.6 USB Host
    support, encoders, dual switch press support, MIID controllable switches
    and much more.
2019-09-09 VC-mini hardware
    Enclosure and schematic of the VC-mini
    [VC-mini enclosure.stp, VC-mini_lower_cover_b.stl, VCmini_upper_cover_Adafruit_display.stl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]
2019-09-09 Updated building plans for VController and VC-mini
    [Half support 3xLCD diameter_2_0.stl, Large LCD support_2_0.stl, RPi expansion board bracket.dwg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]
2019-09-29 Firmware 3.3.1 - Improved encoder support for VC-mini
2019-09-30 Updated BOM
2019-10-02 Main board rev. D
    Fixed Q5/Q6 not having 3.3V on center pin.
    [VController main board-B.Cu.gbl, VController main board-B.Mask.gbs, VController main board-B.SilkS.gbo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]
2020-01-04 Updated enclosure for VC-mini
    [VC-mini enclosure.stp, VC-mini_lower_cover_b.stl, VC-mini_upper_cover_color_display.stl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]
2020-01-04 Updated building guide with new enclosure
2020-01-04 Added alternative option for enclosure
2020-02-13 Removed old stl for Adafruit display
    [VC-mini_upper_cover_Adafruit_display.stl, VCmini_upper_cover_Adafruit_display.stl]
2022-03-15 VC-touch hardware upload
    [backside.dxf, bottom plate.dxf, top plate.dxf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]
2022-04-18 VC-touch window
    [VC-touch_window.stp]
2022-05-02 Release of VCtouch wireless v1.0.0
2022-05-04 Updated stl's for display
    [vctouch_display_bezel.stl, vctouch_display_support.stl]
2023-10-25 Updated VC-touch hardware
    [backside.dxf, vctouch_plate_holder.stl]
2023-10-26 VController modification for Teensy 4.1
